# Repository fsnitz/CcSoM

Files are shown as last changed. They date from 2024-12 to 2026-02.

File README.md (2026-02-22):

# CcSoM
Screenshot 2024-12-20 at 3 45 26 PM

## Description
CcSoM is a credit card-sized System on Module built around the GateMate FPGA from Cologne Chip. It is designed to accommodate the CCGM1A1 and CCGM1A2 FPGAs with all their features. 
This repository contains all the necessary design files to fabricate and further develop the SoM itself or an application specific baseboard for it. 
A simple IO tester and programmer baseboard can be found in the [Baseboards](Baseboards) folder.
The [Library](Library) folder contains a symbol and footprint to simplify the process of creating a new baseboard. 
Each board folder includes a PDF version of the board and schematics, as well as an interactive HTML BOM.

## Features: 
  - Choose the IO-Bank supply voltage for each IO-Bank freely within the capability of the GateMate FPGA (default 2.5V).
  - All IOs are routed to the SODIMM-connector and can be accessed either as single-ended signal or as differential pair with its designated partner IO.
  - Configuration of the FPGA is possible over JTAG or the on-board QSPI-Flash.

## Manufacturing notes
- The SoM is designed for JLCPCBs "JLC0610H-3313" layer stack and with vias in pads. If a different manufacturer is chosen, it is advisable to either reroute all differential lines or to find a manufacturer where the layer stack can be specified.
- Most of the resistors and capacitors have a 0201 footprint, which may complicate the manufacturing process. 

## Author
Felix Sebastian Nitz

## Acknowledgment
A special thanks to Cologne chip and its employees for their feedback on the design and FPGA samples.

## License
This project falls under the open hardware licence agreement.

## Project status
- SoM revision 1.0 is currently tested with the CCGM1A1 FPGA. Beginning of 2025 an evaluation of its capabilities with an CCGM1A2 will follow.
- A version of the SoM with a 0402 footprint can be found under its designated Tag [0402 Version](https://github.com/fsnitz/CcSoM/tree/VersionWith0402Components).

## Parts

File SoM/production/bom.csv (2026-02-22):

Designator | Footprint | Quantity | Value | LCSC Part #
C1, C11, C13, C21, C23, C29, C35, C41, C7 | 0402 | 9 | 2u2
C10, C20, C44, C45, C46, C47, C6 | 0603 | 7 | 22u
C12, C22, C8 | 0402 | 3 | 220n
C14, C24, C30, C36 | 0402 | 4 | 470n
C15, C16, C19, C2, C25, C26, C3, C31, C32, C37, C38, C4, C42, C43, C5, C9 | 0402 | 16 | 100n
C17, C18, C27, C28, C33, C34, C39, C40 | 0402 | 8 | 10n
D1 | 0603 | 1 | Orange
D2, D3 | 0603 | 2 | GREEN
JP9 | Diff_pair_solderbridge_closed | 1 | ~
L1, L2 | 0603 | 2 | 600R 1.5A, 0.1R
Q1, Q2 | SOT-23 | 2 | BC847
R1, R12, R13 | 0402 | 3 | 200R
R10, R4, R5 | 0402 | 3 | 4K7
R11, R18, R19, R2, R20, R21, R22, R23, R24, R27, R31, R36, R41, R6, R7, R8, R9 | 0402 | 17 | 10K
R14 | Diff_pair_solderbridge_closed | 1 | 100R
R15 | 0402 | 1 | 1R 1%
R16, R17 | 0402 | 2 | DNS
R25 | 0402 | 1 | 100R
R26, R37 | 0402 | 2 | 1K
R28 | 0402 | 1 | 20K 1%
R29 | 0402 | 1 | 100K 1%
R3 | 0402 | 1 | 33R
R30 | 0402 | 1 | 51K 1%
R32 | 0402 | 1 | 240K 1%
R33 | 0402 | 1 | 47K 1%
R34 | 0402 | 1 | 120K 1%
R35 | 0402 | 1 | 62K 1%
R38 | 0402 | 1 | 200K 1%
R39 | 0402 | 1 | 12K
R40 | 0402 | 1 | 63K4 1%
TP21 | TestPoint_Pad_D1.0mm | 1 | Vcore
TP22 | TestPoint_Pad_D1.0mm | 1 | PG
U1 | BGA-324_15.0x15.0mm_Layout18x18_P0.8mm_Ball0.45mm_Pad0.4mm_NSMD | 1 | CCGM1A1
U2 | SOP-8(150_200MIL) | 1 | MX25V8035F
U3 | DCU8 | 1 | 74LVC2G53
U4, U5 | QFN18 | 2 | MPM3833C
X1 | 5x3.2_Oscillator | 1 | ECS-5032MV

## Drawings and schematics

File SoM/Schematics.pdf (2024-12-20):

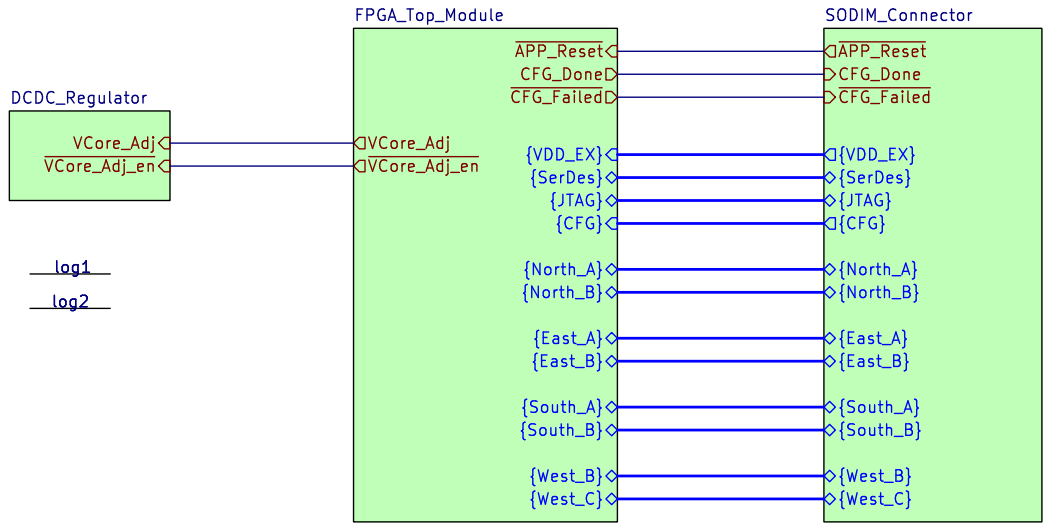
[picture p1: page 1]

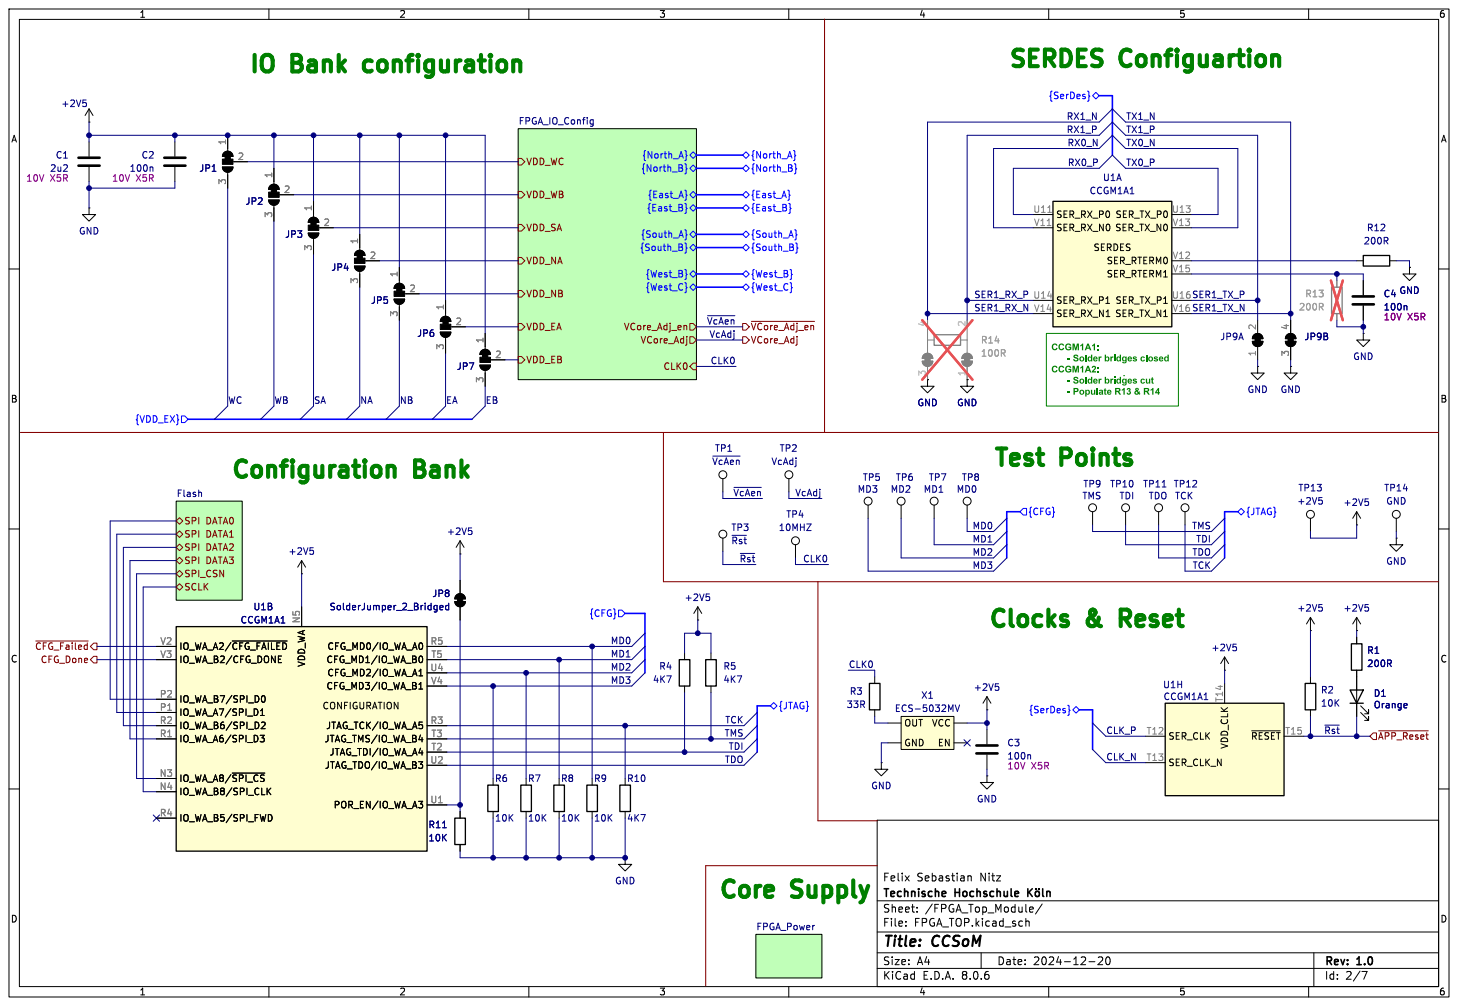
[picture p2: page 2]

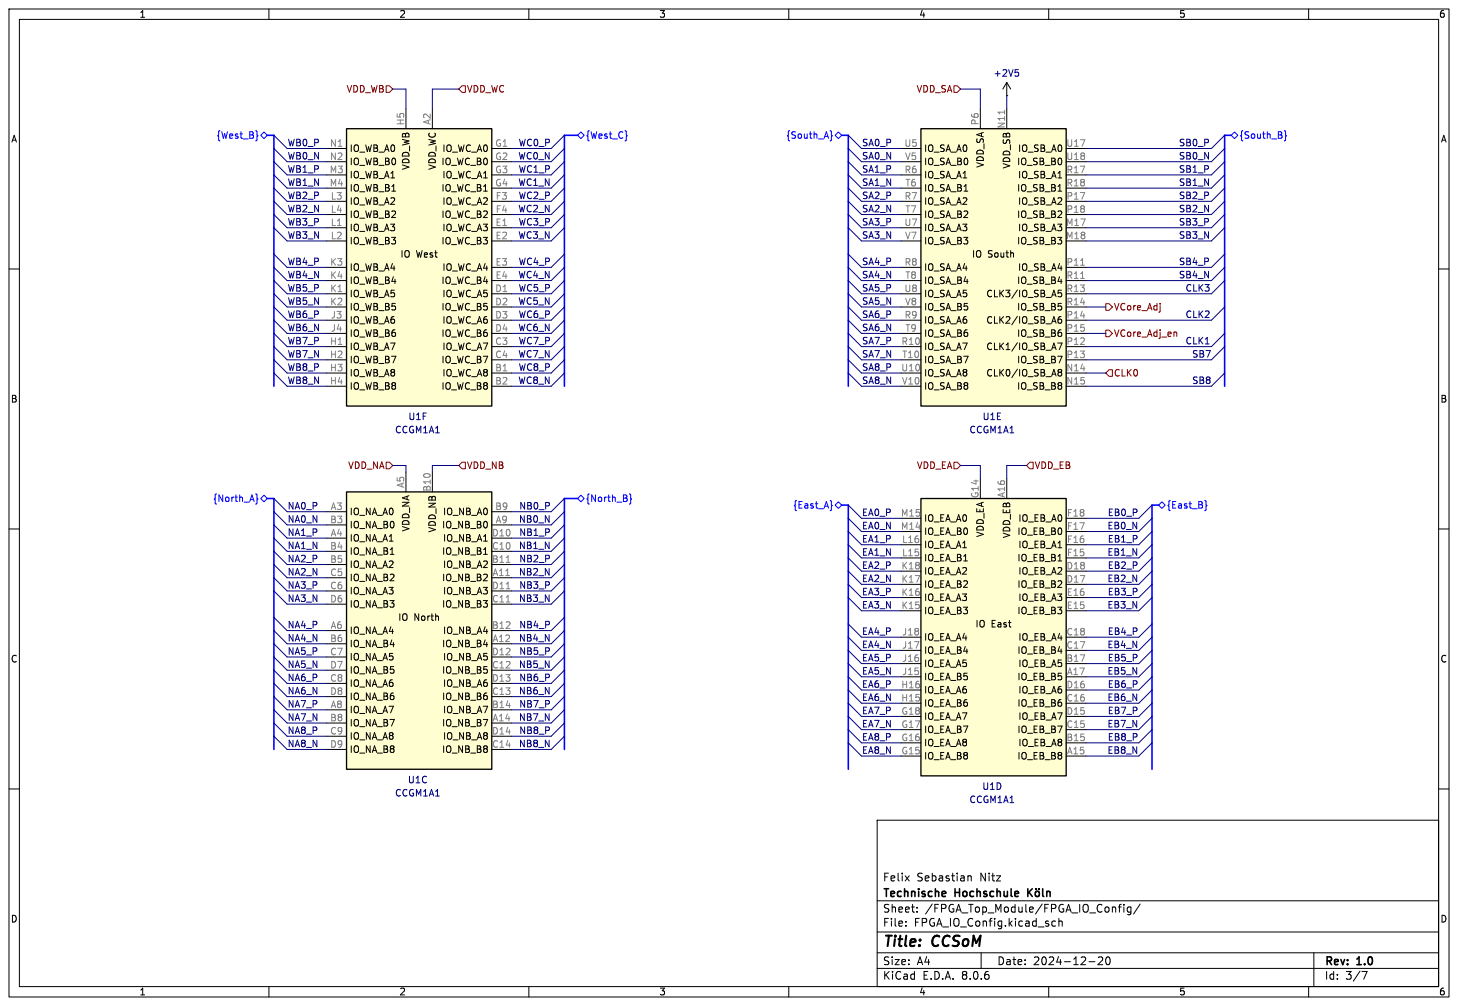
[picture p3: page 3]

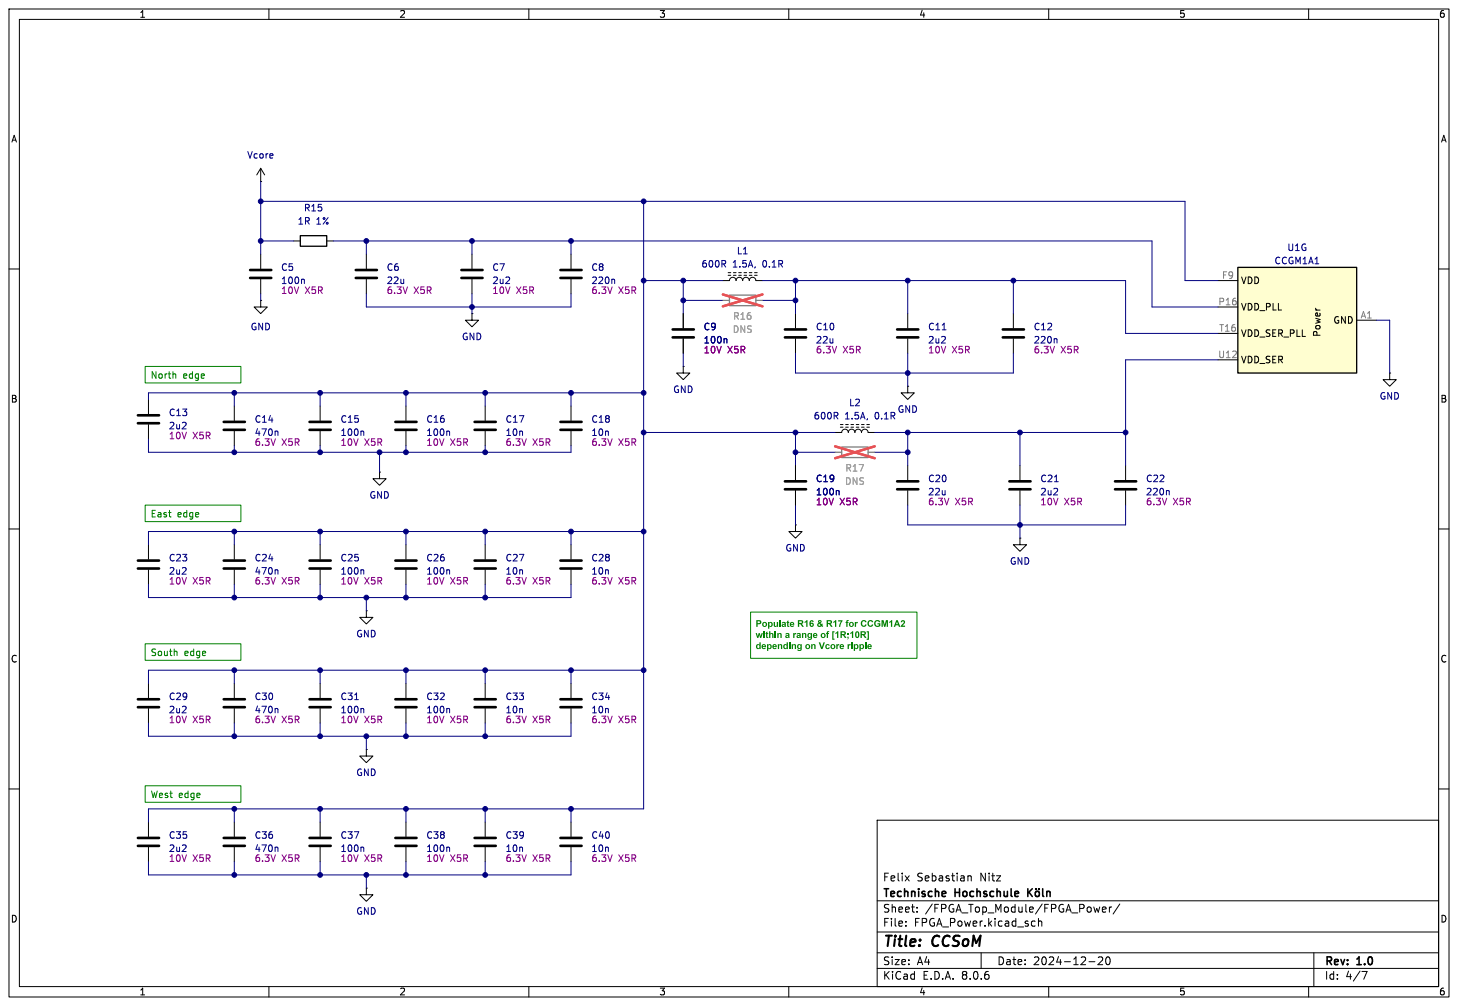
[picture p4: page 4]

Populate R16 & R17 for CCGM1A2 within a range of [1R;10R]

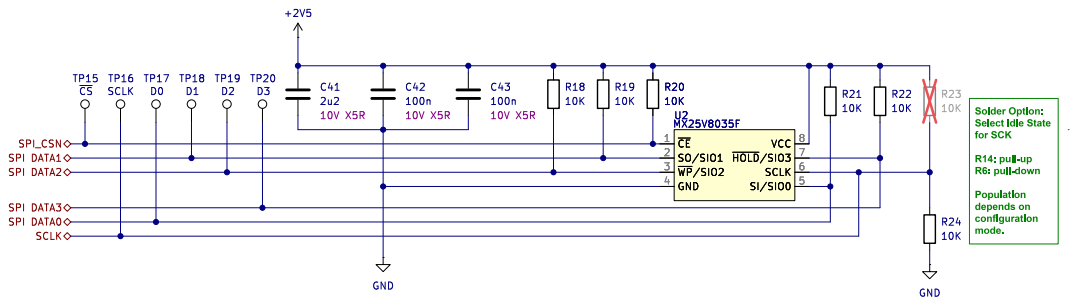
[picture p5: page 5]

Solder Option: Select Idle State

R14: pull-up R6: pull-down

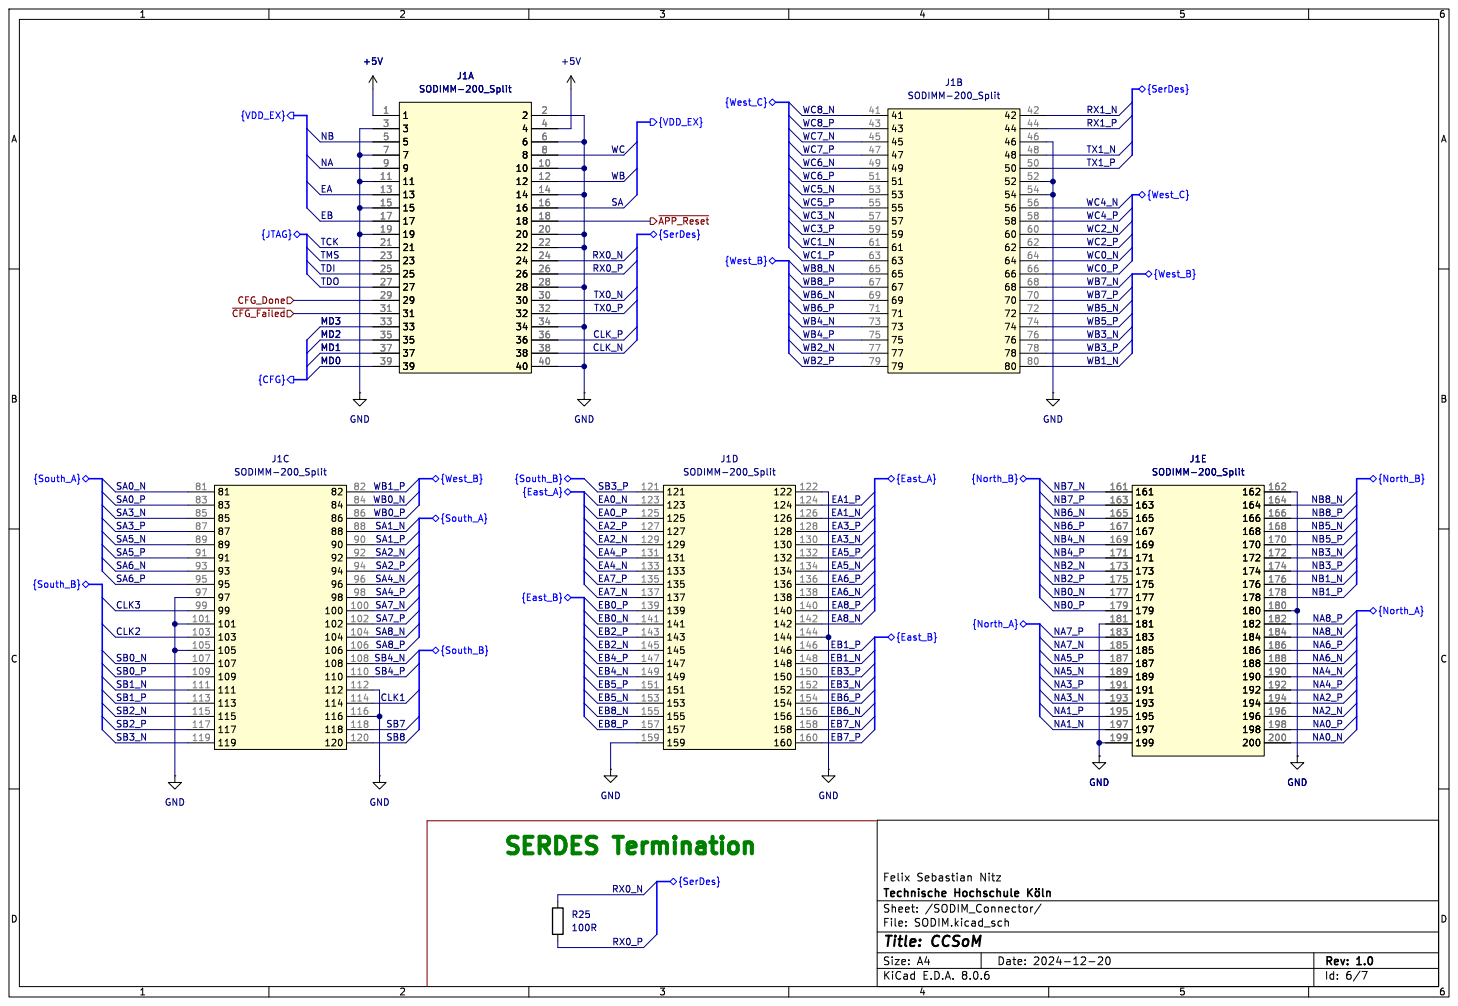
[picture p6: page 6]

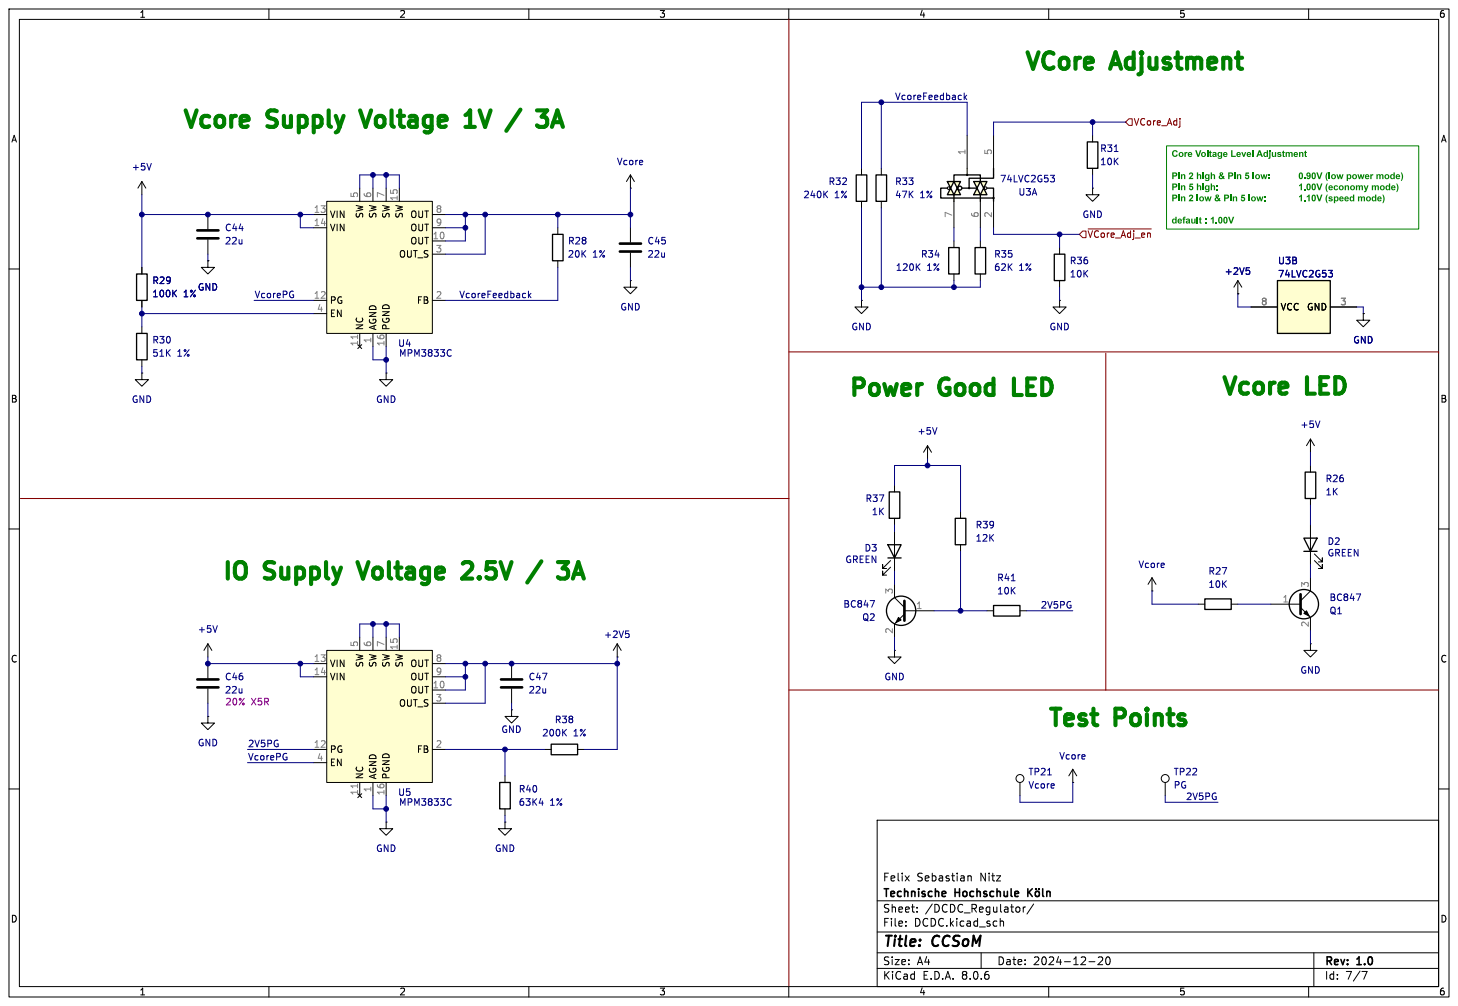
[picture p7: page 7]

1 OUT 10 NC 11 PG 12 VIN 13 VIN 14 SW 15 PGND 16 FB 2 OUT_S 3 EN 4 SW

7 OUT 8 OUT 9 U4MPM3833C GND GND

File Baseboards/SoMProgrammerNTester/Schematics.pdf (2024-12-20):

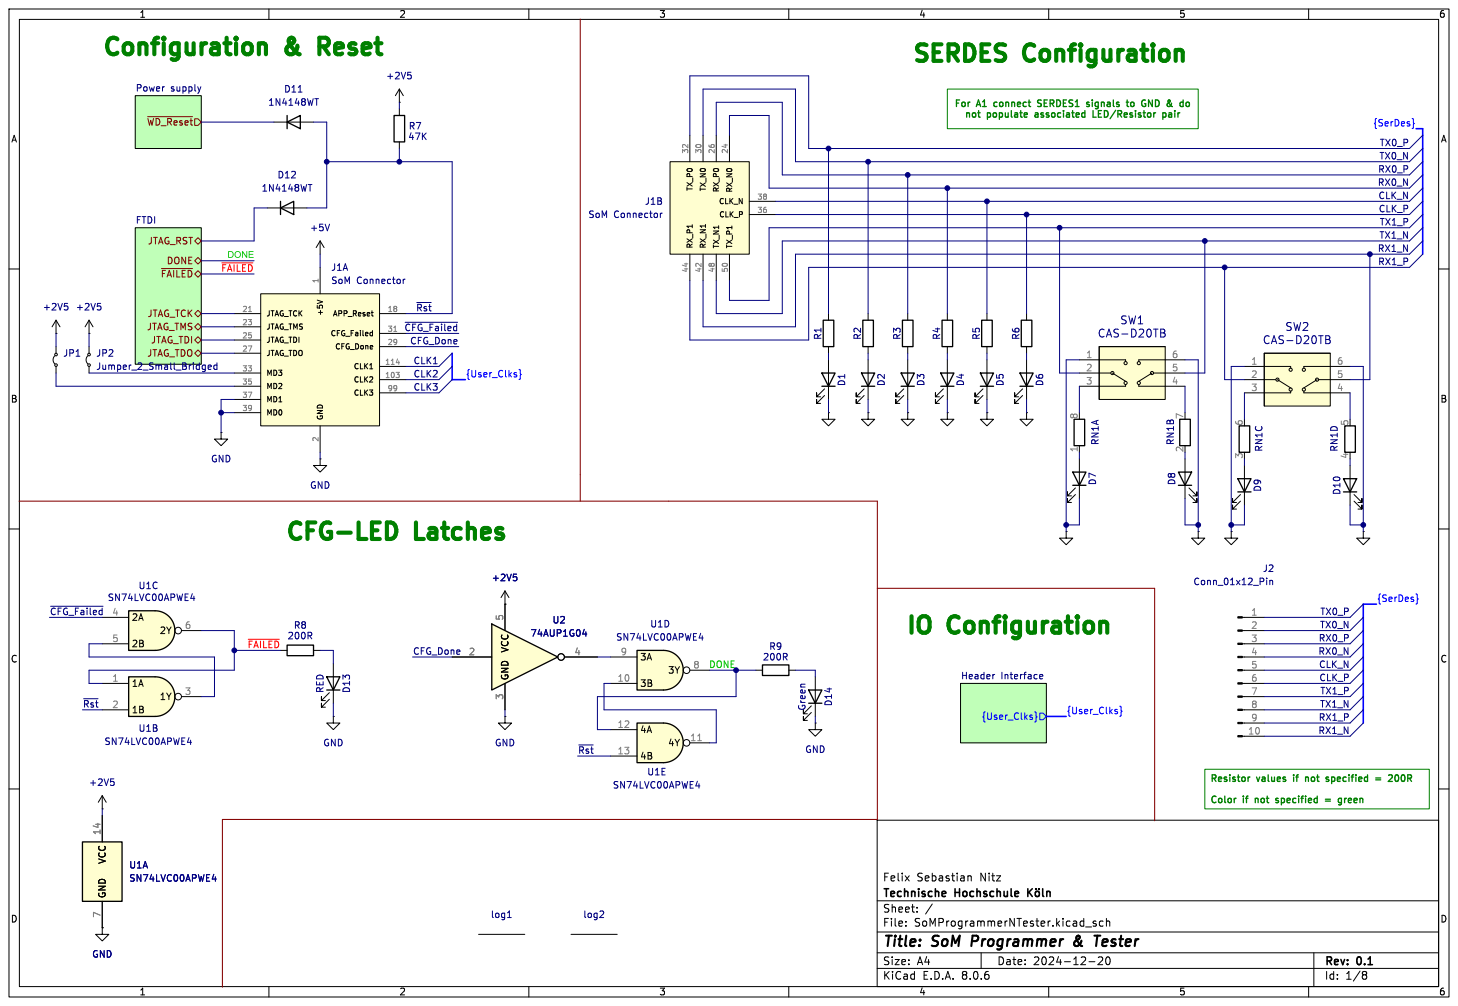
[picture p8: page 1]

For A1 connect SERDES1 signals to GND & do

Color if not specified = green U1A

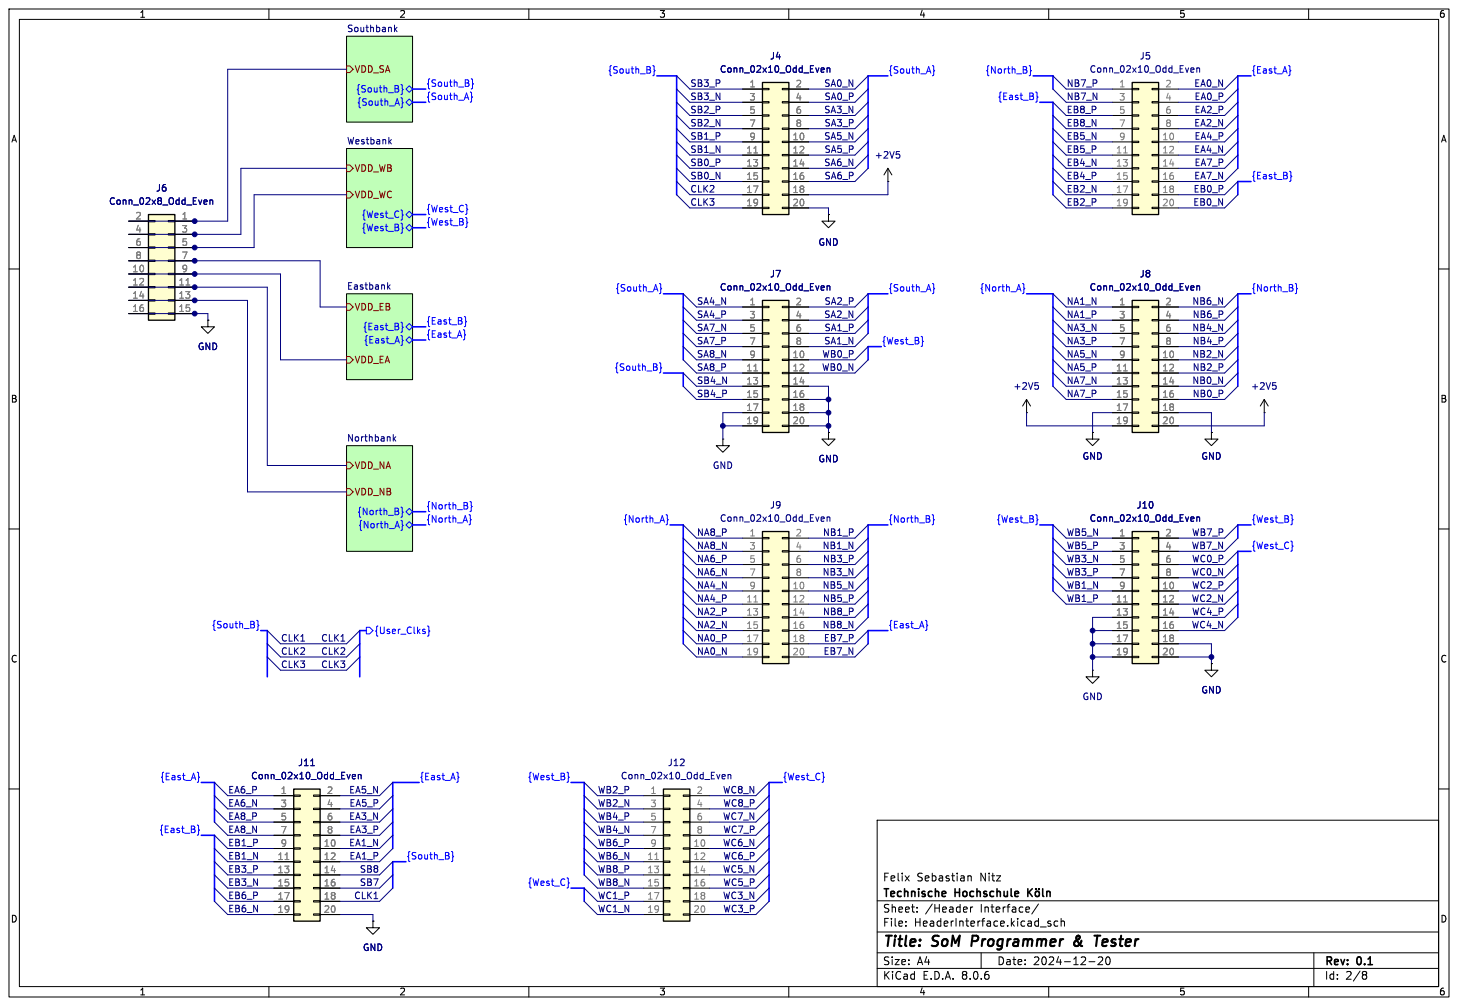
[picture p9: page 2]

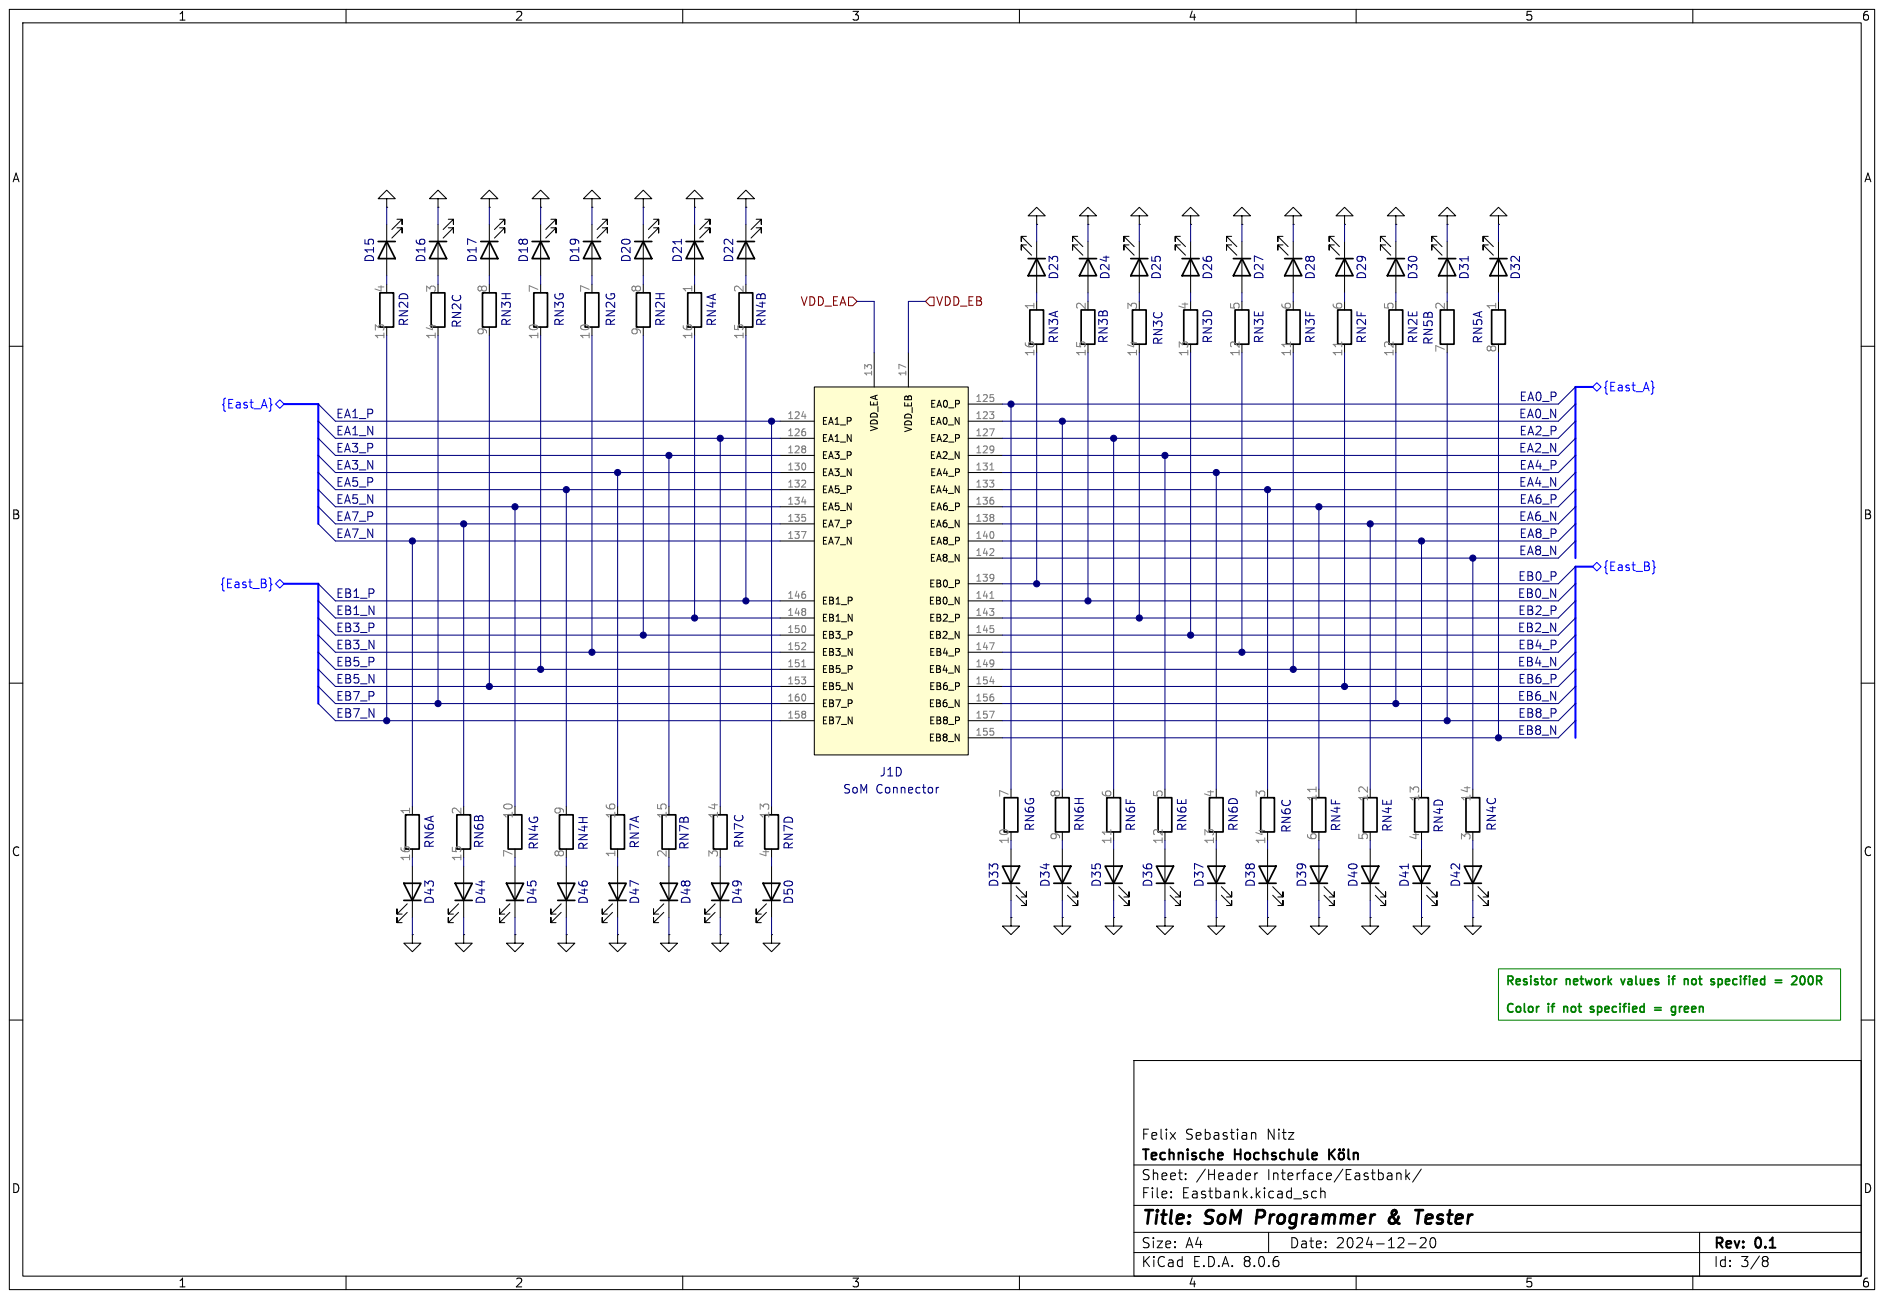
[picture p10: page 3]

Resistor network values if not specified = 200R

Color if not specified = green

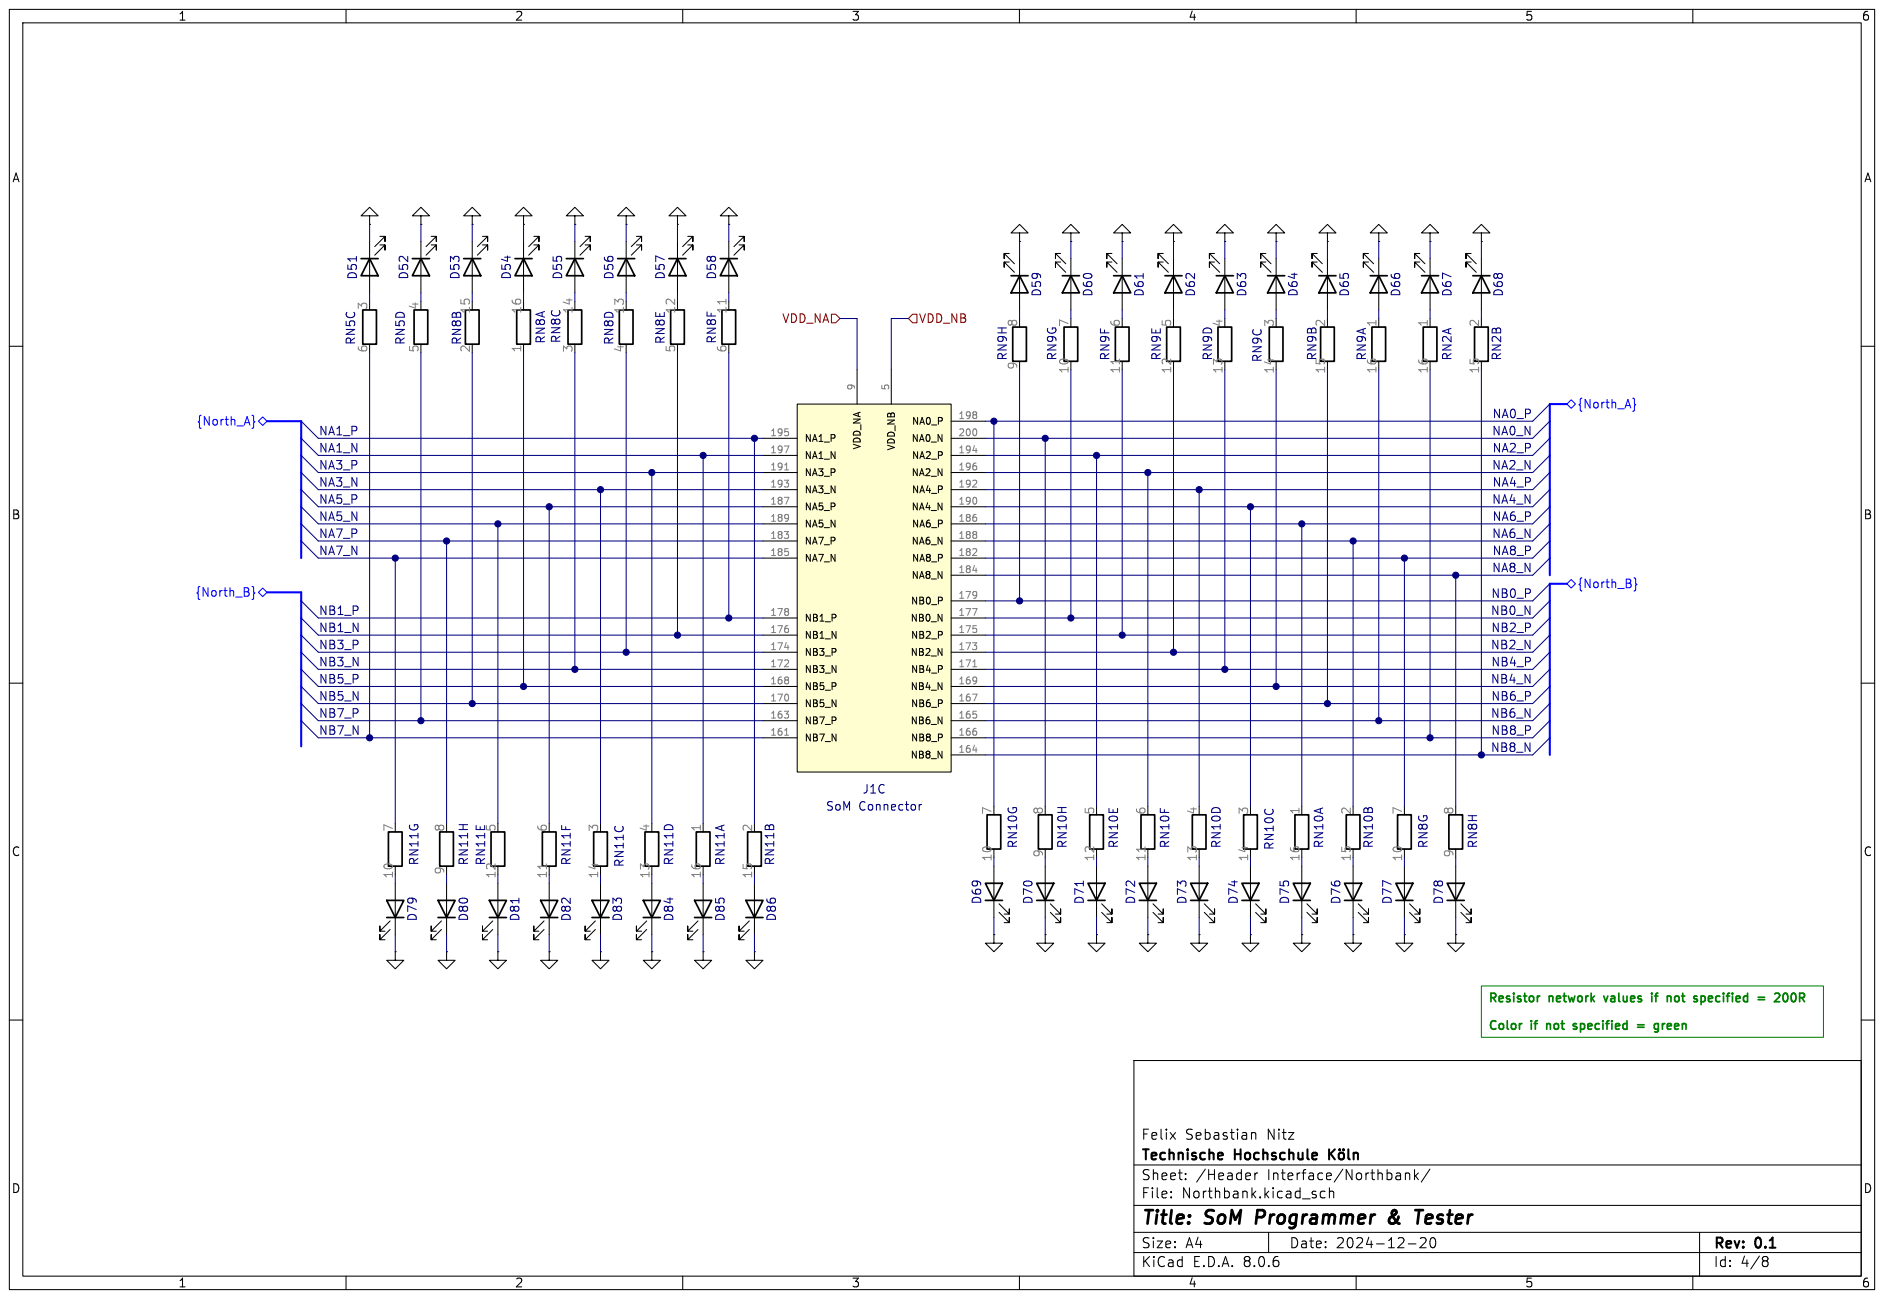
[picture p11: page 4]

NA0_P Resistor network values if not specified = 200R

Color if not specified = green

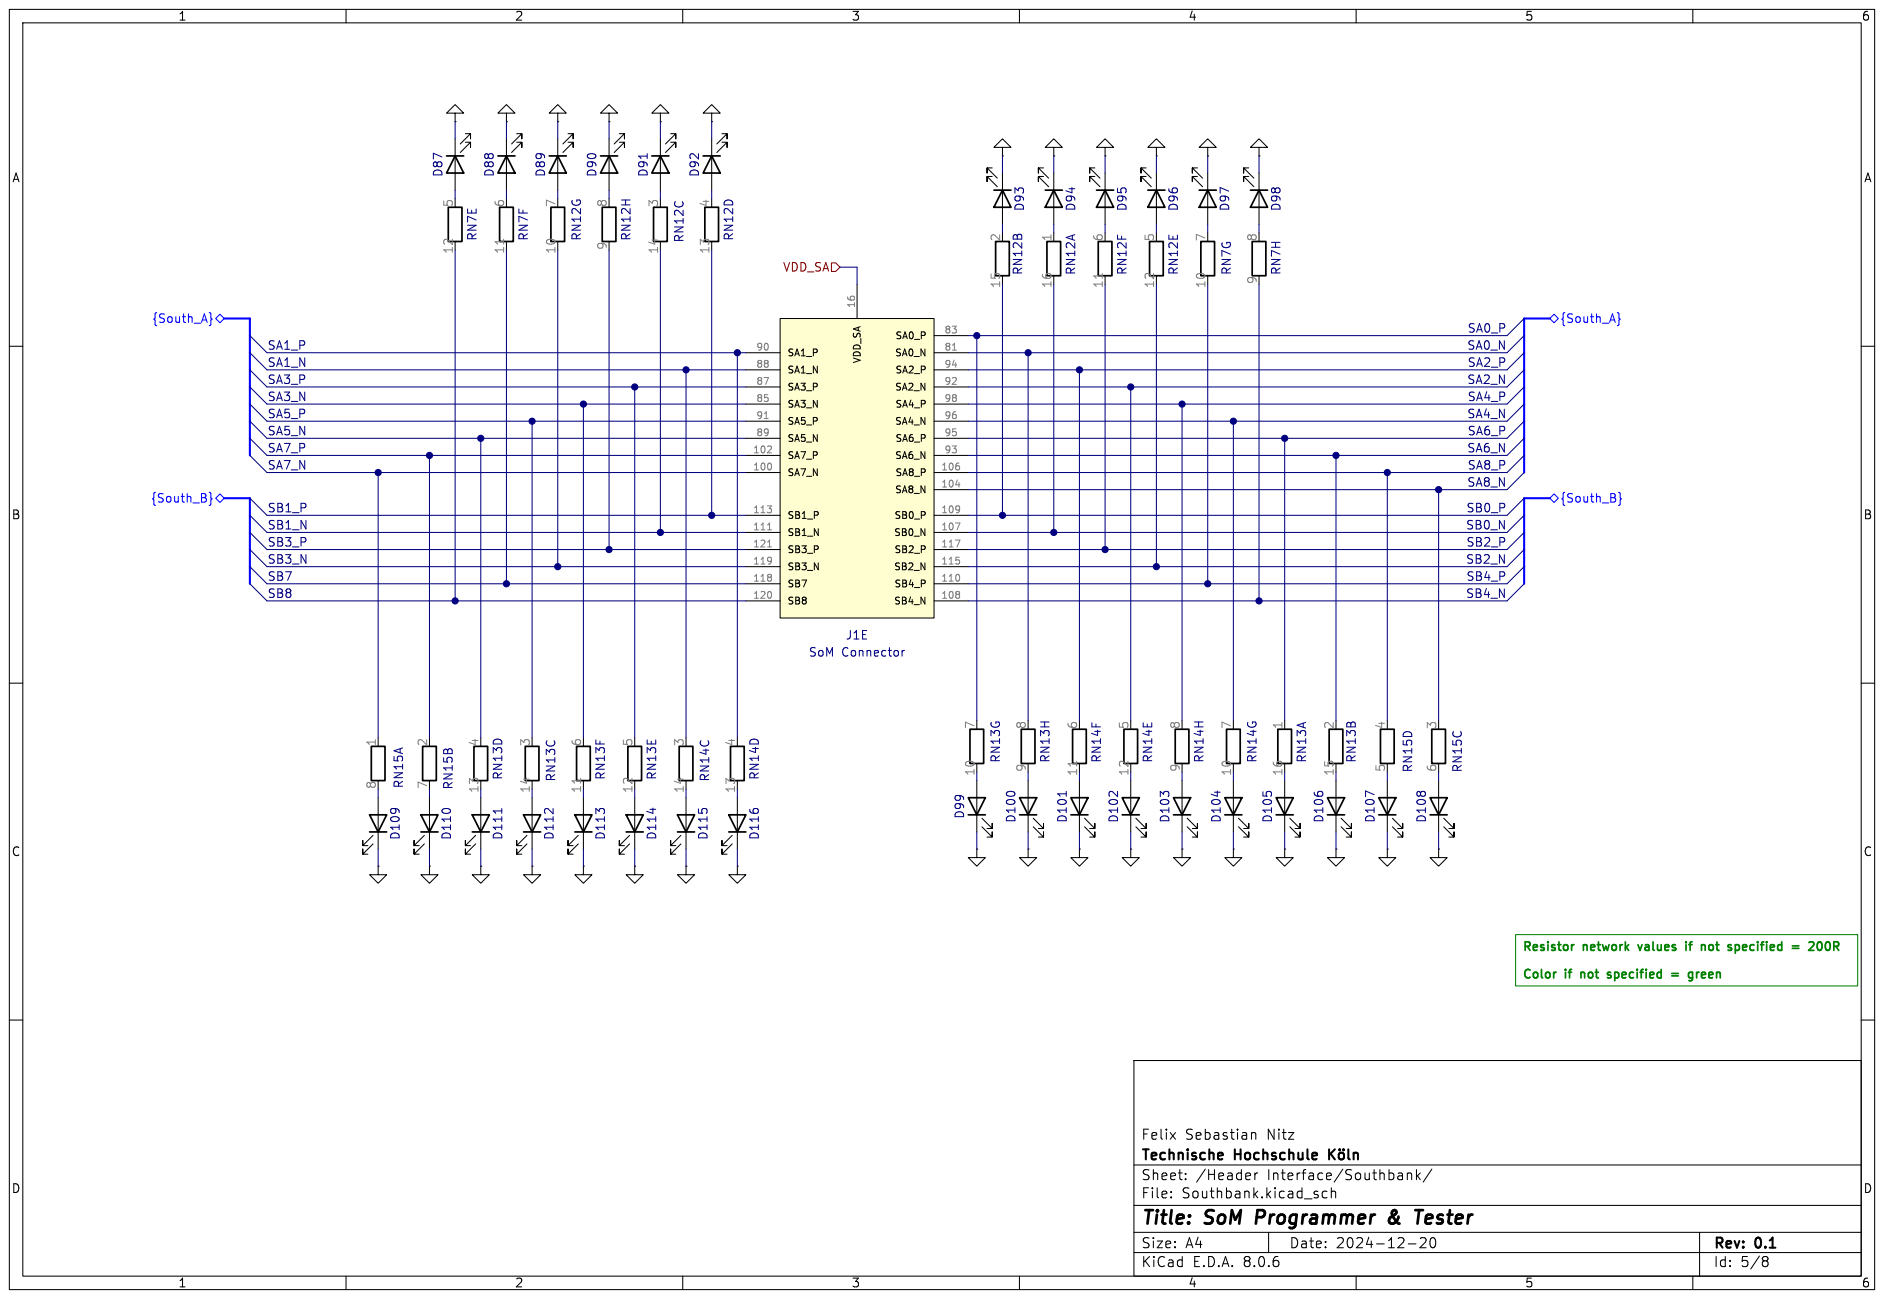
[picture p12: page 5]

Resistor network values if not specified = 200R

Color if not specified = green


Resistor network values if not specified = 200R

Color if not specified = green


1 AGND 10 GND 11 VCORE 12 TEST 13 ~{RESET} 14 GND 15 ADBUS0 16 ADBUS1 17 ADBUS2 18 ADBUS3 19 OSCI 2 VCCIO 20 ADBUS4 21 ADBUS5 22 ADBUS6 23 ADBUS7 24 GND 25 ACBUS0 26 ACBUS1 27 ACBUS2 28 ACBUS3 29 OSCO 3 ACBUS4 30 VCCIO 31 ACBUS5 32 ACBUS6 33 ACBUS7 34 GND 35

4 BDBUS2 40 BDBUS3 41 VCCIO 42 BDBUS4 43 BDBUS5 44 BDBUS6 45 BDBUS7 46 GND 47 BCBUS0 48 VREGOUT 49 GND

5 VREGIN 50 GND 51 BCBUS1 52 BCBUS2 53 BCBUS3 54 BCBUS4 55 VCCIO 56 BCBUS5 57 BCBUS6 58 BCBUS7 59 REF 6 ~{PWREN}60 EEDATA 61 EECLK 62 EECS 63 VCORE 64 DM 7 DP 8 VPLL




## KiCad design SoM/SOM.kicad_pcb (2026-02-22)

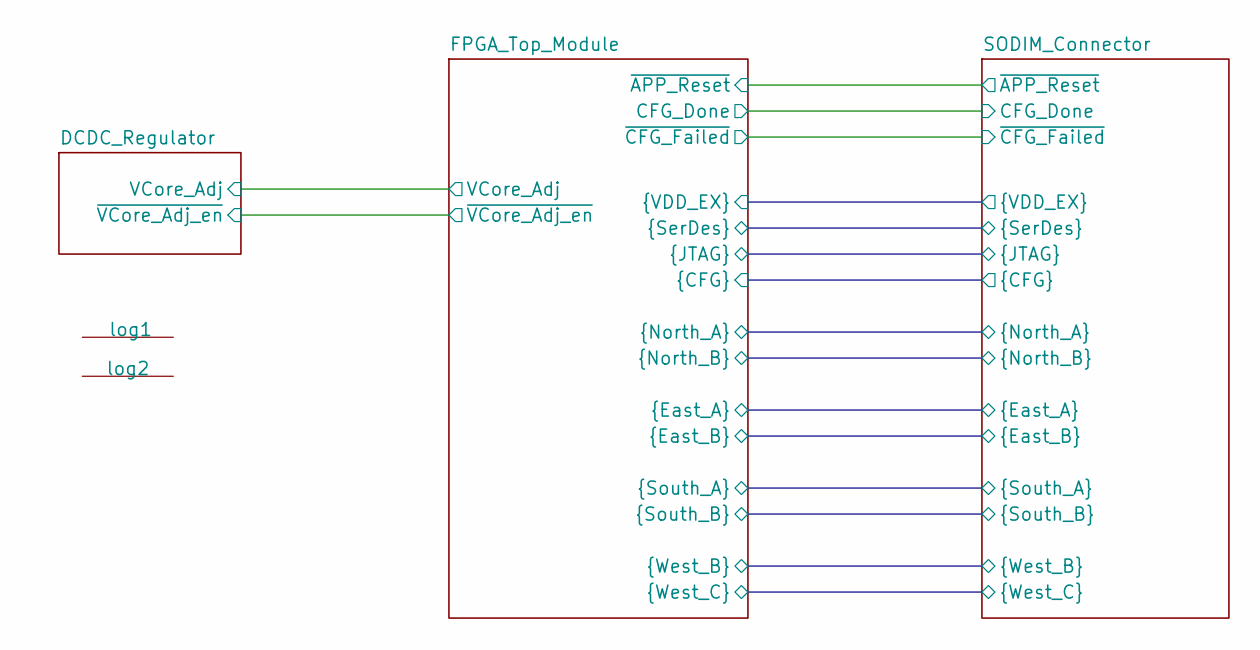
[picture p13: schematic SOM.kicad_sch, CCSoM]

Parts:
log1: PinguinLogo
log2: OpenHardwareLogo

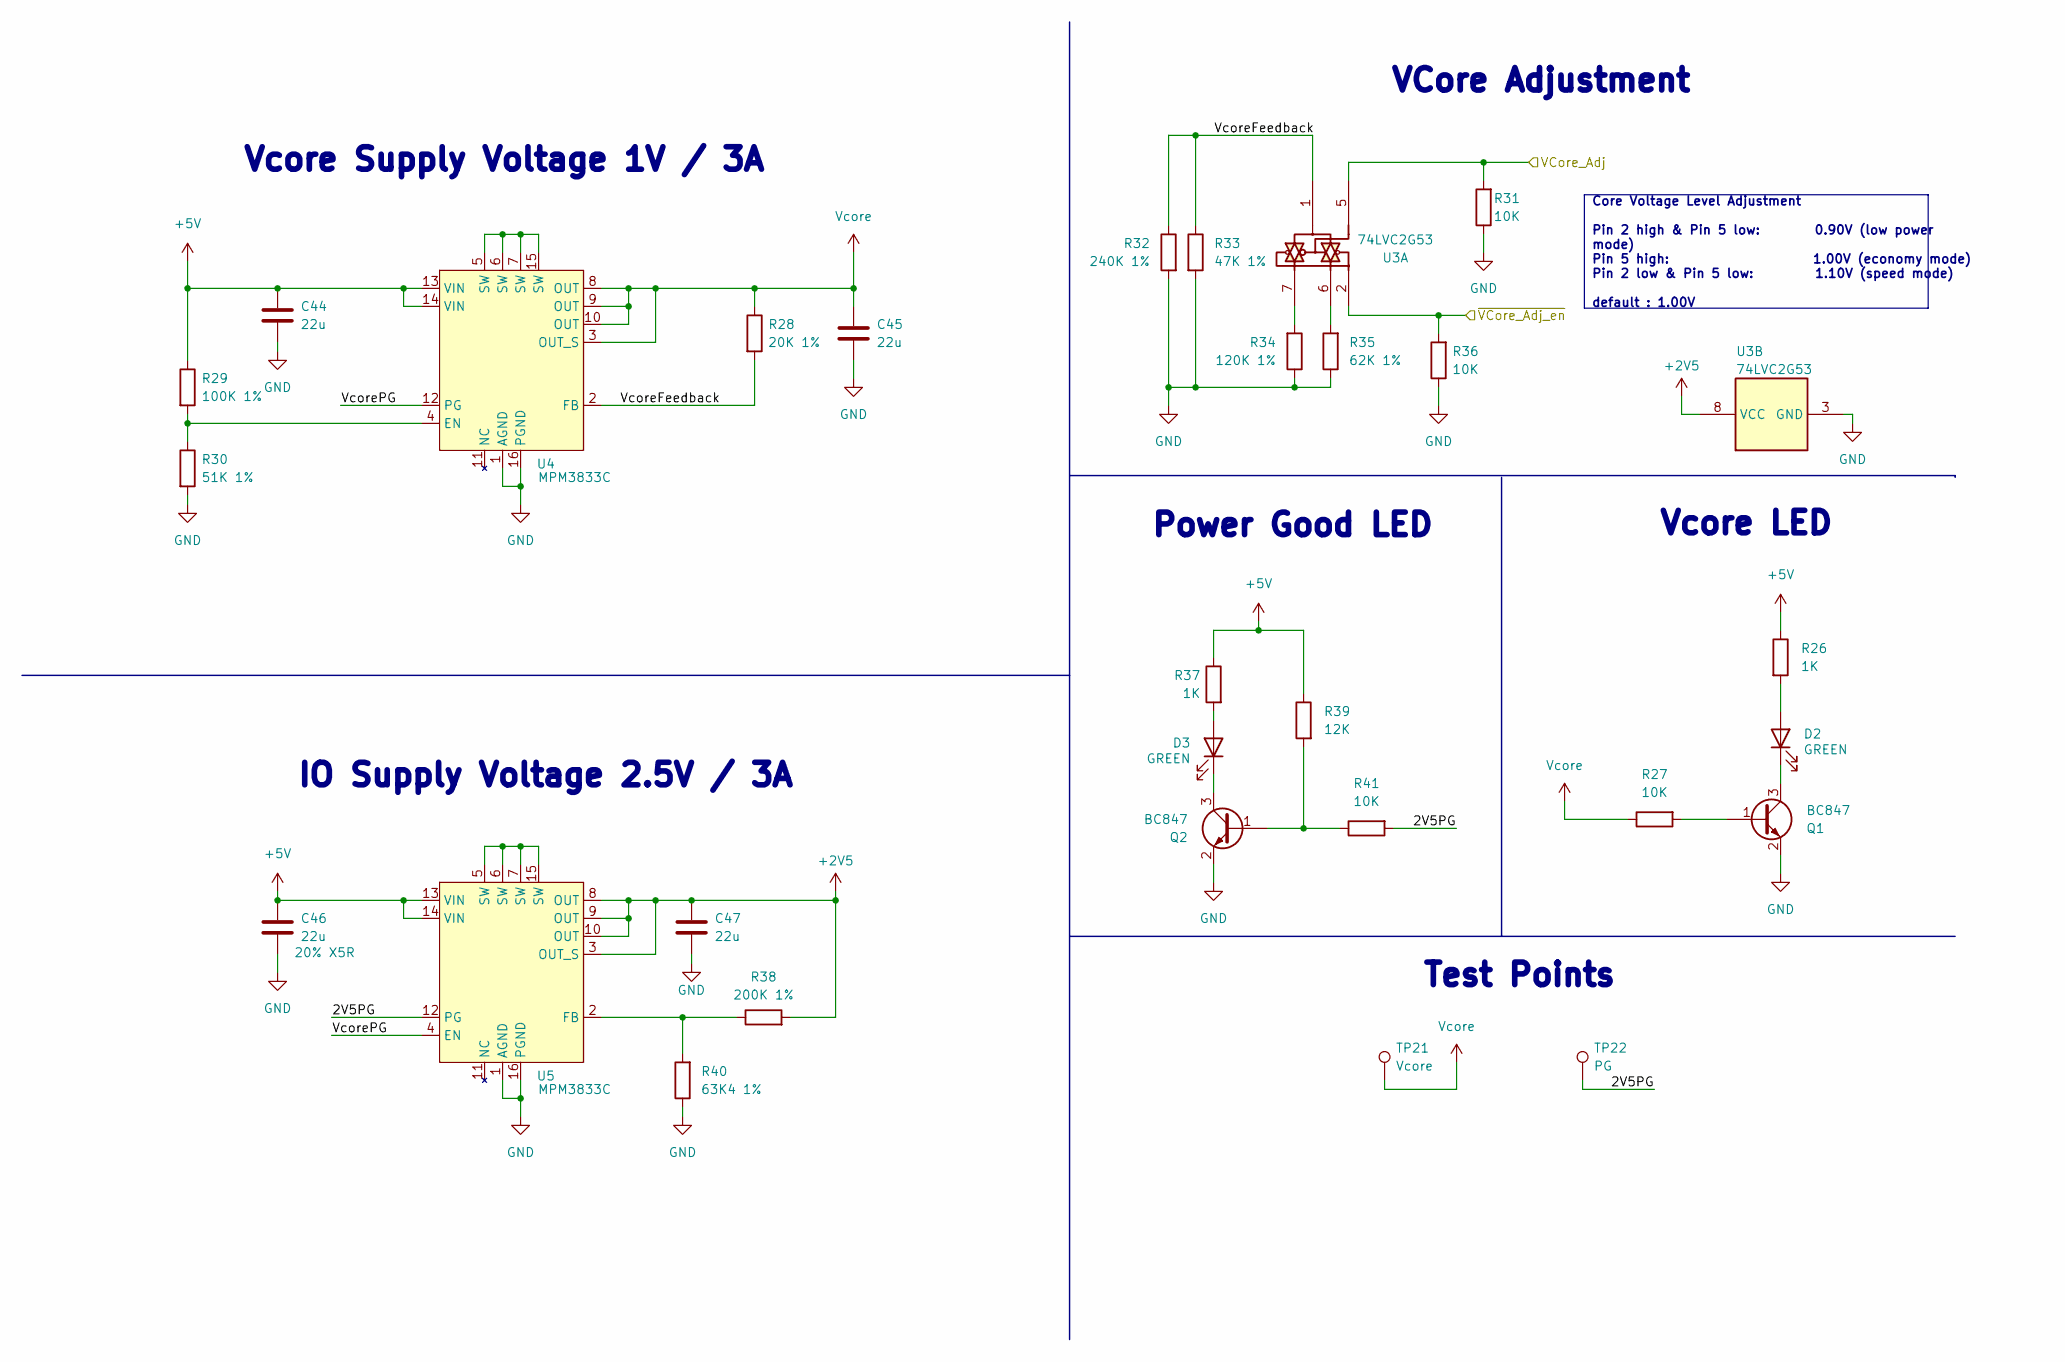
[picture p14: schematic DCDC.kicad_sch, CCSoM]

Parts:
C44, C45, C46, C47: 22u; C_0603_1608Metric; Mouser Part Number GRM188C61C226ME01W
D2, D3: GREEN; LED_0603_1608Metric; Mouser Part Number 150060VS75000
Q1, Q2: BC847; SOT-23; Mouser Part Number BC847C-C
R26, R37: 1K; R_0402_1005Metric; Mouser Part Number MCS04020C1001FE000
R27, R31, R36, R41: 10K; R_0402_1005Metric; Mouser Part Number MCS0402MC1002FE000
R28: 20K 1%; R_0402_1005Metric; Mouser Part Number CRCW040220K0FKED
R29: 100K 1%; R_0402_1005Metric; Mouser Part Number MCS04020C1003FE000
R30: 51K 1%; R_0402_1005Metric; Mouser Part Number CRCW040251K0FKEDC
R32: 240K 1%; R_0402_1005Metric; Mouser Part Number MCS04020C2403FE000
R33: 47K 1%; R_0402_1005Metric; Mouser Part Number CRCW040247K0FKED
R34: 120K 1%; R_0402_1005Metric; Mouser Part Number MCS04020C1203FE000
R35: 62K 1%; R_0402_1005Metric; Mouser Part Number CRCW040262K0FKED
R38: 200K 1%; R_0402_1005Metric; Mouser Part Number CRCW0402200KFKEDC
R39: 12K; R_0402_1005Metric; Mouser Part Number MCS04020C1202FE000
R40: 63K4 1%; R_0402_1005Metric; Mouser Part Number CRCW040263K4FKED
TP21: Vcore; TestPoint_Pad_D1.0mm
TP22: PG; TestPoint_Pad_D1.0mm
U3: 74LVC2G53; DCU8; Mouser Part Number SN74LVC2G53DCUR
U4, U5: MPM3833C; QFN18; Mouser Part Number MPM3833CGRH-Z

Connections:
+2V5: C47.1, R38.2, U3.8 (VCC), U5.3 (OUT_S), U5.8 (OUT), U5.9 (OUT), U5.10 (OUT), U5.20 (OUT); also elsewhere on the board
+5V: C44.1, C46.1, R26.1, R29.1, R37.1, R39.1, U4.13 (VIN), U4.14 (VIN), U5.13 (VIN), U5.14 (VIN); also elsewhere on the board
/DCDC_Regulator/2V5PG: R41.2, TP22.1, U5.12 (PG)
/DCDC_Regulator/VcoreFeedback: R28.2, R32.1, R33.1, U3.1, U4.2 (FB)
/DCDC_Regulator/VcorePG: U4.12 (PG), U5.4 (EN)
/FPGA_Top_Module/VcAdj: R31.2, U3.5; also elsewhere on the board
/FPGA_Top_Module/~VcAen: R36.2, U3.2; also elsewhere on the board
GND: C44.2, C45.2, C46.2, C47.2, Q1.2 (E), Q2.2 (E), R30.2, R31.1, R32.2, R33.2, R34.1, R35.1, R36.1, R40.1, U3.3 (GND), U3.4 (GND), U4.1 (AGND), U4.16 (PGND), U5.1 (AGND), U5.16 (PGND); also elsewhere on the board
unnamed: D2.2 (A), R26.2
unnamed: D2.1 (K), Q1.3 (C)
unnamed: D3.2 (A), R37.2
unnamed: D3.1 (K), Q2.3 (C)
unnamed: Q1.1 (B), R27.2
unnamed: Q2.1 (B), R39.2, R41.1
unnamed: R34.2, U3.7
unnamed: R35.2, U3.6
unnamed: R29.2, R30.1, U4.4 (EN)
unnamed: U4.5 (SW), U4.6 (SW), U4.7 (SW), U4.15 (SW), U4.19 (SW)
unnamed: R38.1, R40.2, U5.2 (FB)
unnamed: U5.5 (SW), U5.6 (SW), U5.7 (SW), U5.15 (SW), U5.19 (SW)
Vcore: C45.1, R27.1, R28.1, TP21.1, U4.3 (OUT_S), U4.8 (OUT), U4.9 (OUT), U4.10 (OUT), U4.20 (OUT); also elsewhere on the board

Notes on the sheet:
Power Good LED
Test Points
Vcore LED
Vcore Supply Voltage 1V / 3A
IO Supply Voltage 2.5V / 3A
VCore Adjustment
Core Voltage Level Adjustment Pin 2 high & Pin 5 low: 0.90V (low power mode) Pin 5 high: 1.00V (economy mode) Pin 2 low & Pin 5 low: 1.10V (speed mode) default : 1.00V

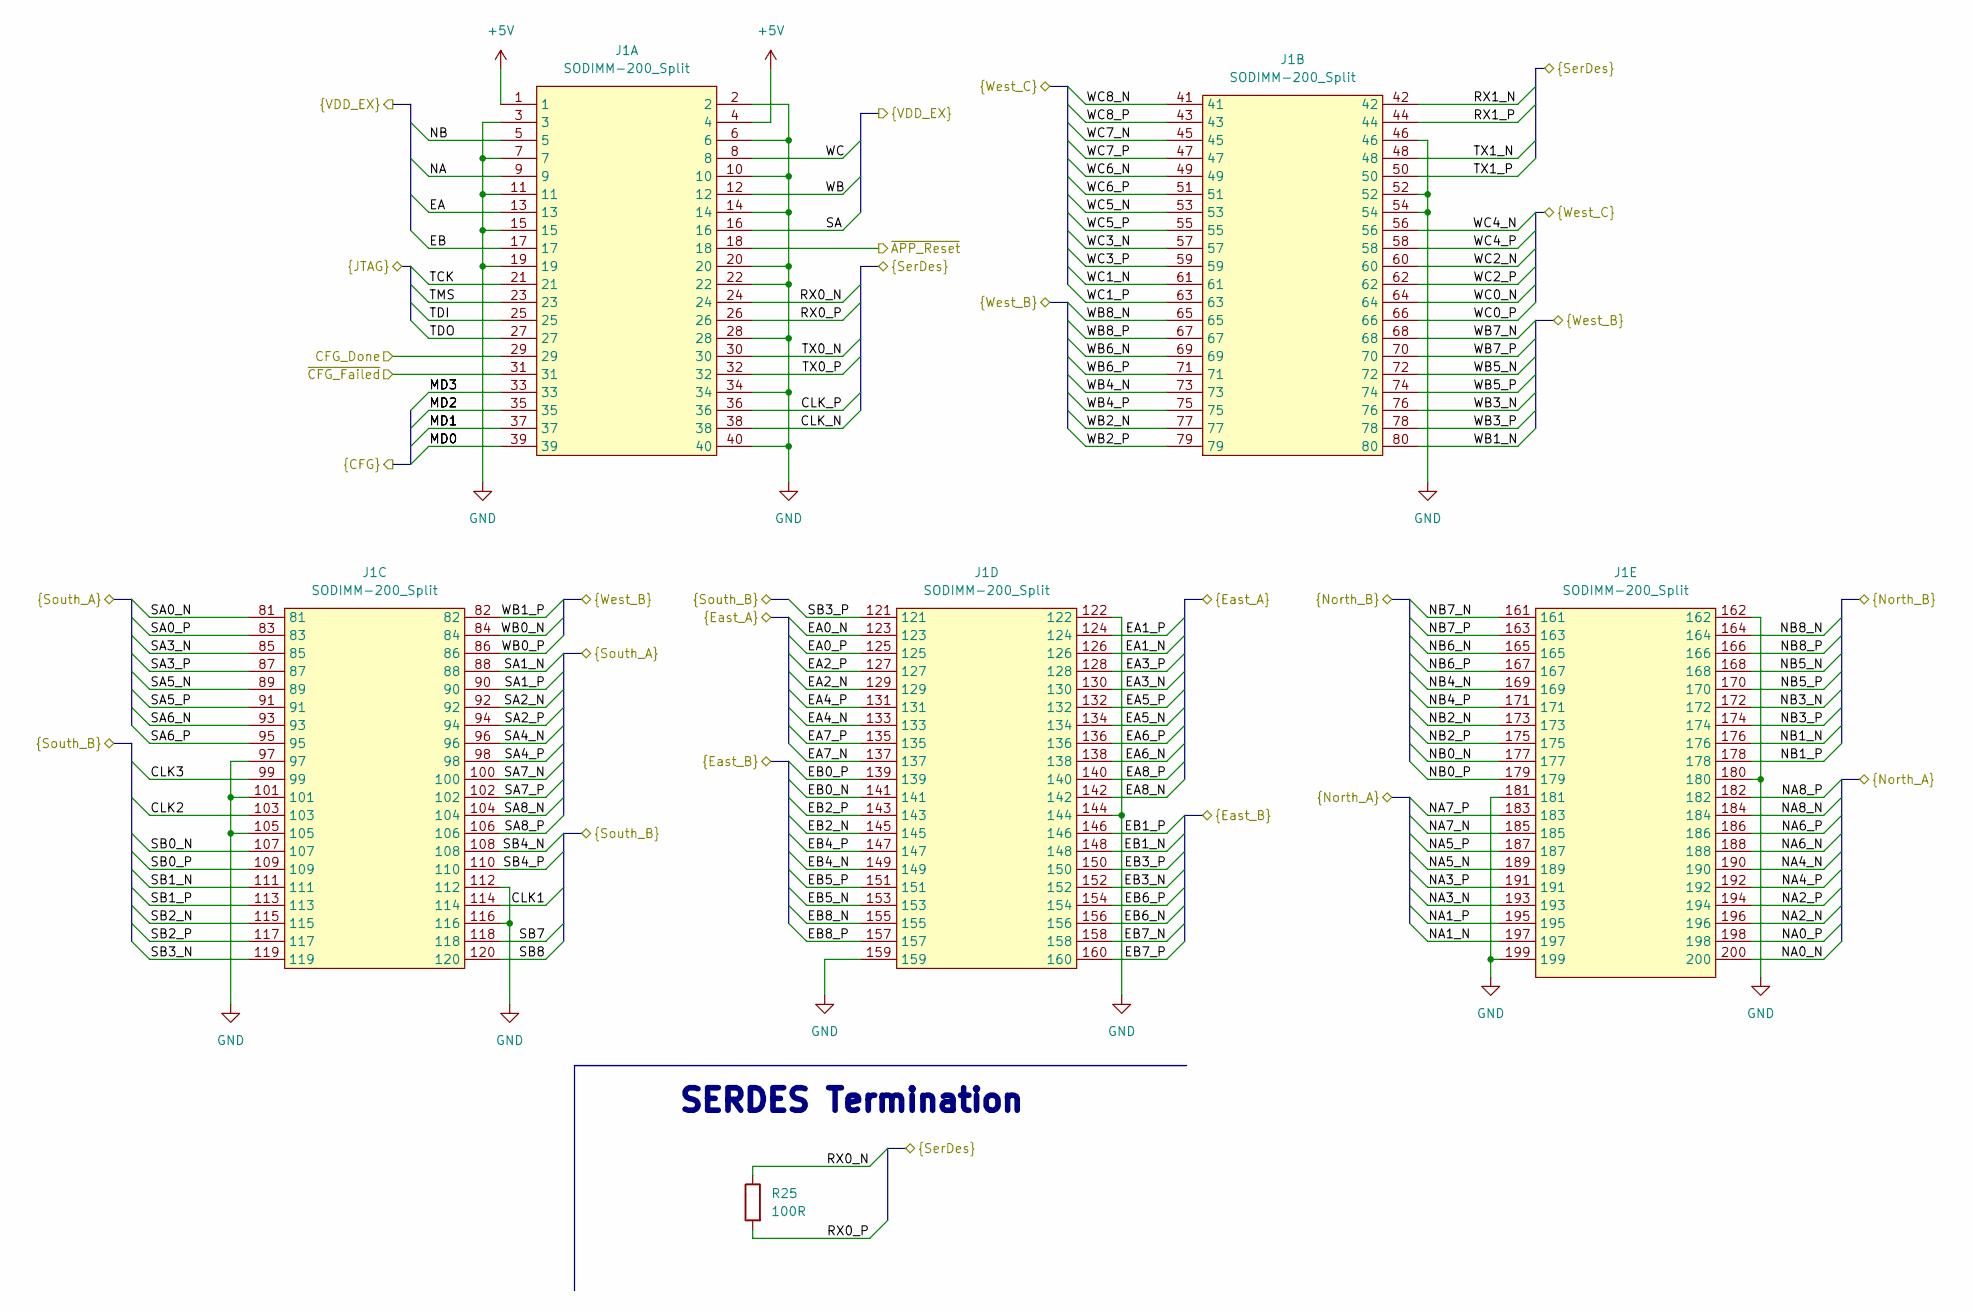
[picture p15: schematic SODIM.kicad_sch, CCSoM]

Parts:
J1: SODIMM-200_Split; SODIMM-200_2.5V_Card_edge
R25: 100R; R_0402_1005Metric; Mouser Part Number MCS04020C1000FE000

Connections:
+5V: J1.1, J1.4; also elsewhere on the board
/FPGA_Top_Module/CFG_Done: J1.29; also elsewhere on the board
/FPGA_Top_Module/CLK1: J1.114; also elsewhere on the board
/FPGA_Top_Module/CLK2: J1.103; also elsewhere on the board
/FPGA_Top_Module/CLK3: J1.99; also elsewhere on the board
/FPGA_Top_Module/CLK_N: J1.38; also elsewhere on the board
/FPGA_Top_Module/CLK_P: J1.36; also elsewhere on the board
/FPGA_Top_Module/EA: J1.13; also elsewhere on the board
/FPGA_Top_Module/EA0_N: J1.123; also elsewhere on the board
/FPGA_Top_Module/EA0_P: J1.125; also elsewhere on the board
/FPGA_Top_Module/EA1_N: J1.126; also elsewhere on the board
/FPGA_Top_Module/EA1_P: J1.124; also elsewhere on the board
/FPGA_Top_Module/EA2_N: J1.129; also elsewhere on the board
/FPGA_Top_Module/EA2_P: J1.127; also elsewhere on the board
/FPGA_Top_Module/EA3_N: J1.130; also elsewhere on the board
/FPGA_Top_Module/EA3_P: J1.128; also elsewhere on the board
/FPGA_Top_Module/EA4_N: J1.133; also elsewhere on the board
/FPGA_Top_Module/EA4_P: J1.131; also elsewhere on the board
/FPGA_Top_Module/EA5_N: J1.134; also elsewhere on the board
/FPGA_Top_Module/EA5_P: J1.132; also elsewhere on the board
/FPGA_Top_Module/EA6_N: J1.138; also elsewhere on the board
/FPGA_Top_Module/EA6_P: J1.136; also elsewhere on the board
/FPGA_Top_Module/EA7_N: J1.137; also elsewhere on the board
/FPGA_Top_Module/EA7_P: J1.135; also elsewhere on the board
/FPGA_Top_Module/EA8_N: J1.142; also elsewhere on the board
/FPGA_Top_Module/EA8_P: J1.140; also elsewhere on the board
/FPGA_Top_Module/EB: J1.17; also elsewhere on the board
/FPGA_Top_Module/EB0_N: J1.141; also elsewhere on the board
/FPGA_Top_Module/EB0_P: J1.139; also elsewhere on the board
/FPGA_Top_Module/EB1_N: J1.148; also elsewhere on the board
/FPGA_Top_Module/EB1_P: J1.146; also elsewhere on the board
/FPGA_Top_Module/EB2_N: J1.145; also elsewhere on the board
/FPGA_Top_Module/EB2_P: J1.143; also elsewhere on the board
/FPGA_Top_Module/EB3_N: J1.152; also elsewhere on the board
/FPGA_Top_Module/EB3_P: J1.150; also elsewhere on the board
/FPGA_Top_Module/EB4_N: J1.149; also elsewhere on the board
/FPGA_Top_Module/EB4_P: J1.147; also elsewhere on the board
/FPGA_Top_Module/EB5_N: J1.153; also elsewhere on the board
/FPGA_Top_Module/EB5_P: J1.151; also elsewhere on the board
/FPGA_Top_Module/EB6_N: J1.156; also elsewhere on the board
/FPGA_Top_Module/EB6_P: J1.154; also elsewhere on the board
/FPGA_Top_Module/EB7_N: J1.158; also elsewhere on the board
/FPGA_Top_Module/EB7_P: J1.160; also elsewhere on the board
/FPGA_Top_Module/EB8_N: J1.155; also elsewhere on the board
/FPGA_Top_Module/EB8_P: J1.157; also elsewhere on the board
/FPGA_Top_Module/MD0: J1.39; also elsewhere on the board
/FPGA_Top_Module/MD1: J1.37; also elsewhere on the board
/FPGA_Top_Module/MD2: J1.35; also elsewhere on the board
/FPGA_Top_Module/MD3: J1.33; also elsewhere on the board
/FPGA_Top_Module/NA: J1.9; also elsewhere on the board
/FPGA_Top_Module/NA0_N: J1.200; also elsewhere on the board
/FPGA_Top_Module/NA0_P: J1.198; also elsewhere on the board
/FPGA_Top_Module/NA1_N: J1.197; also elsewhere on the board
/FPGA_Top_Module/NA1_P: J1.195; also elsewhere on the board
/FPGA_Top_Module/NA2_N: J1.196; also elsewhere on the board
/FPGA_Top_Module/NA2_P: J1.194; also elsewhere on the board
/FPGA_Top_Module/NA3_N: J1.193; also elsewhere on the board
/FPGA_Top_Module/NA3_P: J1.191; also elsewhere on the board
/FPGA_Top_Module/NA4_N: J1.190; also elsewhere on the board
/FPGA_Top_Module/NA4_P: J1.192; also elsewhere on the board
/FPGA_Top_Module/NA5_N: J1.189; also elsewhere on the board
/FPGA_Top_Module/NA5_P: J1.187; also elsewhere on the board
/FPGA_Top_Module/NA6_N: J1.188; also elsewhere on the board
/FPGA_Top_Module/NA6_P: J1.186; also elsewhere on the board
/FPGA_Top_Module/NA7_N: J1.185; also elsewhere on the board
/FPGA_Top_Module/NA7_P: J1.183; also elsewhere on the board
/FPGA_Top_Module/NA8_N: J1.184; also elsewhere on the board
/FPGA_Top_Module/NA8_P: J1.182; also elsewhere on the board
/FPGA_Top_Module/NB: J1.5; also elsewhere on the board
/FPGA_Top_Module/NB0_N: J1.177; also elsewhere on the board
/FPGA_Top_Module/NB0_P: J1.179; also elsewhere on the board
/FPGA_Top_Module/NB1_N: J1.176; also elsewhere on the board
/FPGA_Top_Module/NB1_P: J1.178; also elsewhere on the board
/FPGA_Top_Module/NB2_N: J1.173; also elsewhere on the board
/FPGA_Top_Module/NB2_P: J1.175; also elsewhere on the board
/FPGA_Top_Module/NB3_N: J1.172; also elsewhere on the board
/FPGA_Top_Module/NB3_P: J1.174; also elsewhere on the board
/FPGA_Top_Module/NB4_N: J1.169; also elsewhere on the board
/FPGA_Top_Module/NB4_P: J1.171; also elsewhere on the board
/FPGA_Top_Module/NB5_N: J1.168; also elsewhere on the board
/FPGA_Top_Module/NB5_P: J1.170; also elsewhere on the board
/FPGA_Top_Module/NB6_N: J1.165; also elsewhere on the board
/FPGA_Top_Module/NB6_P: J1.167; also elsewhere on the board
/FPGA_Top_Module/NB7_N: J1.161; also elsewhere on the board
/FPGA_Top_Module/NB7_P: J1.163; also elsewhere on the board
/FPGA_Top_Module/NB8_N: J1.164; also elsewhere on the board
/FPGA_Top_Module/NB8_P: J1.166; also elsewhere on the board
/FPGA_Top_Module/RX0_N: J1.24, R25.1; also elsewhere on the board
/FPGA_Top_Module/RX0_P: J1.26, R25.2; also elsewhere on the board
/FPGA_Top_Module/RX1_N: J1.42; also elsewhere on the board
/FPGA_Top_Module/RX1_P: J1.44; also elsewhere on the board
/FPGA_Top_Module/SA: J1.16; also elsewhere on the board
/FPGA_Top_Module/SA0_N: J1.81; also elsewhere on the board
/FPGA_Top_Module/SA0_P: J1.83; also elsewhere on the board
/FPGA_Top_Module/SA1_N: J1.88; also elsewhere on the board
/FPGA_Top_Module/SA1_P: J1.90; also elsewhere on the board
/FPGA_Top_Module/SA2_N: J1.92; also elsewhere on the board
/FPGA_Top_Module/SA2_P: J1.94; also elsewhere on the board
/FPGA_Top_Module/SA3_N: J1.85; also elsewhere on the board
/FPGA_Top_Module/SA3_P: J1.87; also elsewhere on the board
/FPGA_Top_Module/SA4_N: J1.96; also elsewhere on the board
/FPGA_Top_Module/SA4_P: J1.98; also elsewhere on the board
/FPGA_Top_Module/SA5_N: J1.89; also elsewhere on the board
/FPGA_Top_Module/SA5_P: J1.91; also elsewhere on the board
/FPGA_Top_Module/SA6_N: J1.93; also elsewhere on the board
/FPGA_Top_Module/SA6_P: J1.95; also elsewhere on the board
/FPGA_Top_Module/SA7_N: J1.100; also elsewhere on the board
/FPGA_Top_Module/SA7_P: J1.102; also elsewhere on the board
/FPGA_Top_Module/SA8_N: J1.104; also elsewhere on the board
/FPGA_Top_Module/SA8_P: J1.106; also elsewhere on the board
/FPGA_Top_Module/SB0_N: J1.107; also elsewhere on the board
/FPGA_Top_Module/SB0_P: J1.109; also elsewhere on the board
/FPGA_Top_Module/SB1_N: J1.111; also elsewhere on the board
/FPGA_Top_Module/SB1_P: J1.113; also elsewhere on the board
/FPGA_Top_Module/SB2_N: J1.115; also elsewhere on the board
/FPGA_Top_Module/SB2_P: J1.117; also elsewhere on the board
/FPGA_Top_Module/SB3_N: J1.119; also elsewhere on the board
/FPGA_Top_Module/SB3_P: J1.121; also elsewhere on the board
/FPGA_Top_Module/SB4_N: J1.108; also elsewhere on the board
/FPGA_Top_Module/SB4_P: J1.110; also elsewhere on the board
/FPGA_Top_Module/SB7: J1.118; also elsewhere on the board
/FPGA_Top_Module/SB8: J1.120; also elsewhere on the board
/FPGA_Top_Module/TCK: J1.21; also elsewhere on the board
/FPGA_Top_Module/TDI: J1.25; also elsewhere on the board
/FPGA_Top_Module/TDO: J1.27; also elsewhere on the board
/FPGA_Top_Module/TMS: J1.23; also elsewhere on the board
/FPGA_Top_Module/TX0_N: J1.30; also elsewhere on the board
/FPGA_Top_Module/TX0_P: J1.32; also elsewhere on the board
/FPGA_Top_Module/TX1_N: J1.48; also elsewhere on the board
/FPGA_Top_Module/TX1_P: J1.50; also elsewhere on the board
/FPGA_Top_Module/WB: J1.12; also elsewhere on the board
/FPGA_Top_Module/WB0_N: J1.84; also elsewhere on the board
/FPGA_Top_Module/WB0_P: J1.86; also elsewhere on the board
/FPGA_Top_Module/WB1_N: J1.80; also elsewhere on the board
/FPGA_Top_Module/WB1_P: J1.82; also elsewhere on the board
/FPGA_Top_Module/WB2_N: J1.77; also elsewhere on the board
/FPGA_Top_Module/WB2_P: J1.79; also elsewhere on the board
/FPGA_Top_Module/WB3_N: J1.76; also elsewhere on the board
/FPGA_Top_Module/WB3_P: J1.78; also elsewhere on the board
/FPGA_Top_Module/WB4_N: J1.73; also elsewhere on the board
/FPGA_Top_Module/WB4_P: J1.75; also elsewhere on the board
/FPGA_Top_Module/WB5_N: J1.72; also elsewhere on the board
/FPGA_Top_Module/WB5_P: J1.74; also elsewhere on the board
/FPGA_Top_Module/WB6_N: J1.69; also elsewhere on the board
/FPGA_Top_Module/WB6_P: J1.71; also elsewhere on the board
/FPGA_Top_Module/WB7_N: J1.68; also elsewhere on the board
/FPGA_Top_Module/WB7_P: J1.70; also elsewhere on the board
/FPGA_Top_Module/WB8_N: J1.65; also elsewhere on the board
/FPGA_Top_Module/WB8_P: J1.67; also elsewhere on the board
/FPGA_Top_Module/WC: J1.8; also elsewhere on the board
/FPGA_Top_Module/WC0_N: J1.64; also elsewhere on the board
/FPGA_Top_Module/WC0_P: J1.66; also elsewhere on the board
/FPGA_Top_Module/WC1_N: J1.61; also elsewhere on the board
/FPGA_Top_Module/WC1_P: J1.63; also elsewhere on the board
/FPGA_Top_Module/WC2_N: J1.60; also elsewhere on the board
/FPGA_Top_Module/WC2_P: J1.62; also elsewhere on the board
/FPGA_Top_Module/WC3_N: J1.57; also elsewhere on the board
/FPGA_Top_Module/WC3_P: J1.59; also elsewhere on the board
/FPGA_Top_Module/WC4_N: J1.56; also elsewhere on the board
/FPGA_Top_Module/WC4_P: J1.58; also elsewhere on the board
/FPGA_Top_Module/WC5_N: J1.53; also elsewhere on the board
/FPGA_Top_Module/WC5_P: J1.55; also elsewhere on the board
/FPGA_Top_Module/WC6_N: J1.49; also elsewhere on the board
/FPGA_Top_Module/WC6_P: J1.51; also elsewhere on the board
/FPGA_Top_Module/WC7_N: J1.45; also elsewhere on the board
/FPGA_Top_Module/WC7_P: J1.47; also elsewhere on the board
/FPGA_Top_Module/WC8_N: J1.41; also elsewhere on the board
/FPGA_Top_Module/WC8_P: J1.43; also elsewhere on the board
/FPGA_Top_Module/~CFG_Failed: J1.31; also elsewhere on the board
/FPGA_Top_Module/~Rst: J1.18; also elsewhere on the board
GND: J1.2, J1.3, J1.6, J1.7, J1.10, J1.11, J1.14, J1.15, J1.19, J1.20, J1.22, J1.28, J1.34, J1.40, J1.46, J1.52, J1.54, J1.97, J1.101, J1.105, J1.112, J1.116, J1.122, J1.144, J1.159, J1.162, J1.180, J1.181, J1.199; also elsewhere on the board

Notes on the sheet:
SERDES Termination

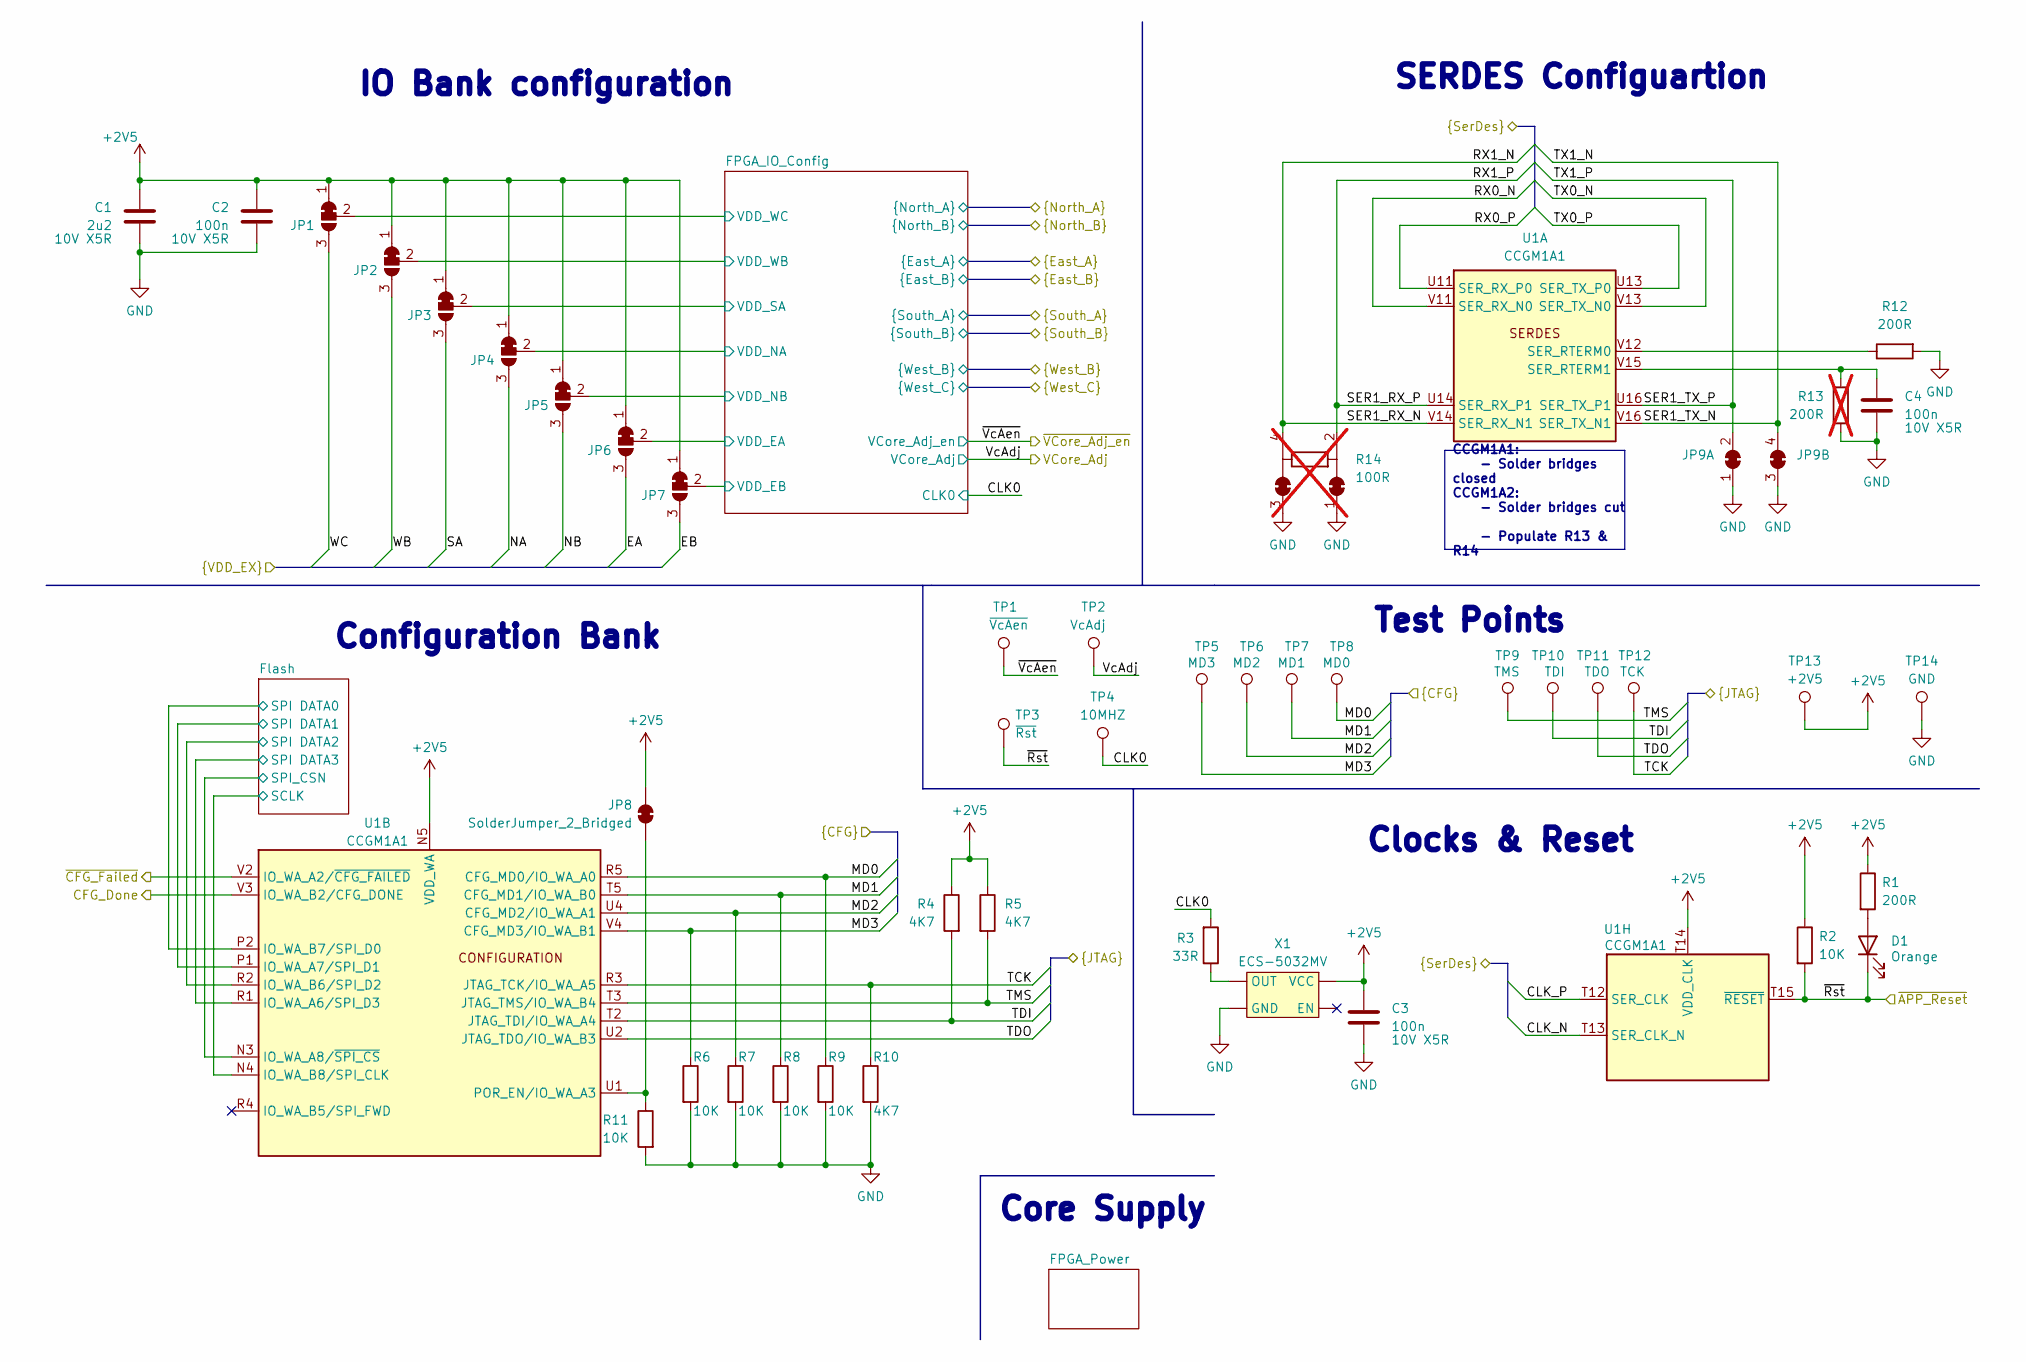
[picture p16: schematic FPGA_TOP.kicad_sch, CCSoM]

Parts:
C1: 2u2; C_0402_1005Metric; Voltage/Precision 10V X5R; Mouser Part Number GRM155Z71A225KE44D
C2, C3, C4: 100n; C_0402_1005Metric; Voltage/Precision 10V X5R; Mouser Part Number GRM155R71C104KA88J
D1: Orange; LED_0603_1608Metric; Mouser Part Number APT1608SECK-AMT
JP1, JP2, JP3, JP4, JP5, JP6, JP7: SolderJumper_3_Bridged12; SolderBridge3Pin
JP8: SolderJumper_2_Bridged; Solderbridge_closed
JP9: Diff_pair_solderbridge_closed
R1, R12: 200R; R_0402_1005Metric; Mouser Part Number MCS04020C2000FE000
R2, R6, R7, R8, R9, R11: 10K; R_0402_1005Metric; Mouser Part Number MCS0402MC1002FE000
R3: 33R; R_0402_1005Metric; Mouser Part Number MCS04020C3309FE000
R4, R5, R10: 4K7; R_0402_1005Metric; Mouser Part Number CRCW04024K70FKED
R13: 200R; R_0402_1005Metric; Mouser Part Number 71-CRCW0201-200; not fitted
R14: 100R; Diff_pair_solderbridge_closed; not fitted
TP1: ~{VcAen}; TestPoint_Pad_D1.0mm
TP2: VcAdj; TestPoint_Pad_D1.0mm
TP3: ~{Rst}; TestPoint_Pad_D1.0mm
TP4: 10MHZ; TestPoint_Pad_D1.0mm
TP5: MD3; TestPoint_Pad_D1.0mm
TP6: MD2; TestPoint_Pad_D1.0mm
TP7: MD1; TestPoint_Pad_D1.0mm
TP8: MD0; TestPoint_Pad_D1.0mm
TP9: TMS; TestPoint_Pad_D1.0mm
TP10: TDI; TestPoint_Pad_D1.0mm
TP11: TDO; TestPoint_Pad_D1.0mm
TP12: TCK; TestPoint_Pad_D1.0mm
TP13: +2V5; TestPoint_Pad_D1.0mm
TP14: GND; TestPoint_Pad_D1.0mm
U1: CCGM1A1; BGA-324_15.0x15.0mm_Layout18x18_P0.8mm_Ball0.45mm_Pad0.4mm_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; Mouser Part Number CCGM1A1-BGA324
X1: ECS-5032MV; 5x3.2_Oscillator; Mouser Part Number ECS-5032MV-100-BN-TR

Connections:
+2V5: C1.1, C2.1, C3.1, JP1.1 (A), JP2.1 (A), JP3.1 (A), JP4.1 (A), JP5.1 (A), JP6.1 (A), JP7.1 (A), JP8.2 (B), R1.1, R2.1, R4.1, R5.1, TP13.1, U1.N5 (VDD_WA), U1.P3 (VDD_WA), U1.P5 (VDD_WA), U1.T1 (VDD_WA), U1.T14 (VDD_CLK), U1.U3 (VDD_WA), X1.4 (VCC); also elsewhere on the board
/FPGA_Top_Module/CFG_Done: U1.V3 (IO_WA_B2/CFG_DONE); also elsewhere on the board
/FPGA_Top_Module/CLK0: R3.2, TP4.1; also elsewhere on the board
/FPGA_Top_Module/CLK_N: U1.T13 (SER_CLK_N); also elsewhere on the board
/FPGA_Top_Module/CLK_P: U1.T12 (SER_CLK); also elsewhere on the board
/FPGA_Top_Module/EA: JP6.3 (B); also elsewhere on the board
/FPGA_Top_Module/EB: JP7.3 (B); also elsewhere on the board
/FPGA_Top_Module/FPGA_IO_Config/VDD_EA: JP6.2 (C); also elsewhere on the board
/FPGA_Top_Module/FPGA_IO_Config/VDD_EB: JP7.2 (C); also elsewhere on the board
/FPGA_Top_Module/FPGA_IO_Config/VDD_NA: JP4.2 (C); also elsewhere on the board
/FPGA_Top_Module/FPGA_IO_Config/VDD_NB: JP5.2 (C); also elsewhere on the board
/FPGA_Top_Module/FPGA_IO_Config/VDD_SA: JP3.2 (C); also elsewhere on the board
/FPGA_Top_Module/FPGA_IO_Config/VDD_WB: JP2.2 (C); also elsewhere on the board
/FPGA_Top_Module/FPGA_IO_Config/VDD_WC: JP1.2 (C); also elsewhere on the board
/FPGA_Top_Module/Flash/SCLK: U1.N4 (IO_WA_B8/SPI_CLK); also elsewhere on the board
/FPGA_Top_Module/Flash/SPI DATA0: U1.P2 (IO_WA_B7/SPI_D0); also elsewhere on the board
/FPGA_Top_Module/Flash/SPI DATA1: U1.P1 (IO_WA_A7/SPI_D1); also elsewhere on the board
/FPGA_Top_Module/Flash/SPI DATA2: U1.R2 (IO_WA_B6/SPI_D2); also elsewhere on the board
/FPGA_Top_Module/Flash/SPI DATA3: U1.R1 (IO_WA_A6/SPI_D3); also elsewhere on the board
/FPGA_Top_Module/Flash/SPI_CSN: U1.N3 (IO_WA_A8/~SPI_CS); also elsewhere on the board
/FPGA_Top_Module/MD0: R9.1, TP8.1, U1.R5 (CFG_MD0/IO_WA_A0); also elsewhere on the board
/FPGA_Top_Module/MD1: R8.1, TP7.1, U1.T5 (CFG_MD1/IO_WA_B0); also elsewhere on the board
/FPGA_Top_Module/MD2: R7.1, TP6.1, U1.U4 (CFG_MD2/IO_WA_A1); also elsewhere on the board
/FPGA_Top_Module/MD3: R6.1, TP5.1, U1.V4 (CFG_MD3/IO_WA_B1); also elsewhere on the board
/FPGA_Top_Module/NA: JP4.3 (B); also elsewhere on the board
/FPGA_Top_Module/NB: JP5.3 (B); also elsewhere on the board
/FPGA_Top_Module/RX0_N: U1.V11 (SER_RX_N0); also elsewhere on the board
/FPGA_Top_Module/RX0_P: U1.U11 (SER_RX_P0); also elsewhere on the board
/FPGA_Top_Module/RX1_N: R14.4, U1.V14 (SER_RX_N1); also elsewhere on the board
/FPGA_Top_Module/RX1_P: R14.2, U1.U14 (SER_RX_P1); also elsewhere on the board
/FPGA_Top_Module/SA: JP3.3 (B); also elsewhere on the board
/FPGA_Top_Module/TCK: R10.1, TP12.1, U1.R3 (JTAG_TCK/IO_WA_A5); also elsewhere on the board
/FPGA_Top_Module/TDI: R4.2, TP10.1, U1.T2 (JTAG_TDI/IO_WA_A4); also elsewhere on the board
/FPGA_Top_Module/TDO: TP11.1, U1.U2 (JTAG_TDO/IO_WA_B3); also elsewhere on the board
/FPGA_Top_Module/TMS: R5.2, TP9.1, U1.T3 (JTAG_TMS/IO_WA_B4); also elsewhere on the board
/FPGA_Top_Module/TX0_N: U1.V13 (SER_TX_N0); also elsewhere on the board
/FPGA_Top_Module/TX0_P: U1.U13 (SER_TX_P0); also elsewhere on the board
/FPGA_Top_Module/TX1_N: JP9.4 (B), U1.V16 (SER_TX_N1); also elsewhere on the board
/FPGA_Top_Module/TX1_P: JP9.2 (B), U1.U16 (SER_TX_P1); also elsewhere on the board
/FPGA_Top_Module/VcAdj: TP2.1; also elsewhere on the board
/FPGA_Top_Module/WB: JP2.3 (B); also elsewhere on the board
/FPGA_Top_Module/WC: JP1.3 (B); also elsewhere on the board
/FPGA_Top_Module/~CFG_Failed: U1.V2 (IO_WA_A2/~CFG_FAILED); also elsewhere on the board
/FPGA_Top_Module/~Rst: D1.1 (K), R2.2, TP3.1, U1.T15 (~RESET); also elsewhere on the board
/FPGA_Top_Module/~VcAen: TP1.1; also elsewhere on the board
GND: C1.2, C2.2, C3.2, C4.2, JP9.1 (A), JP9.3 (A), R6.2, R7.2, R8.2, R9.2, R10.2, R11.2, R12.2, R13.2, R14.1 (A), R14.3 (A), TP14.1, X1.2 (GND); also elsewhere on the board
unnamed: D1.2 (A), R1.2
unnamed: JP8.1 (A), R11.1, U1.U1 (POR_EN/IO_WA_A3)
unnamed: R12.1, U1.V12 (SER_RTERM0)
unnamed: C4.1, R13.1, U1.V15 (SER_RTERM1)
unnamed: R3.1, X1.3 (OUT)

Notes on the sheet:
Test Points
IO Bank configuration
Core Supply
Clocks & Reset
SERDES Configuartion
Configuration Bank
CCGM1A1: - Solder bridges closed CCGM1A2: - Solder bridges cut - Populate R13 & R14

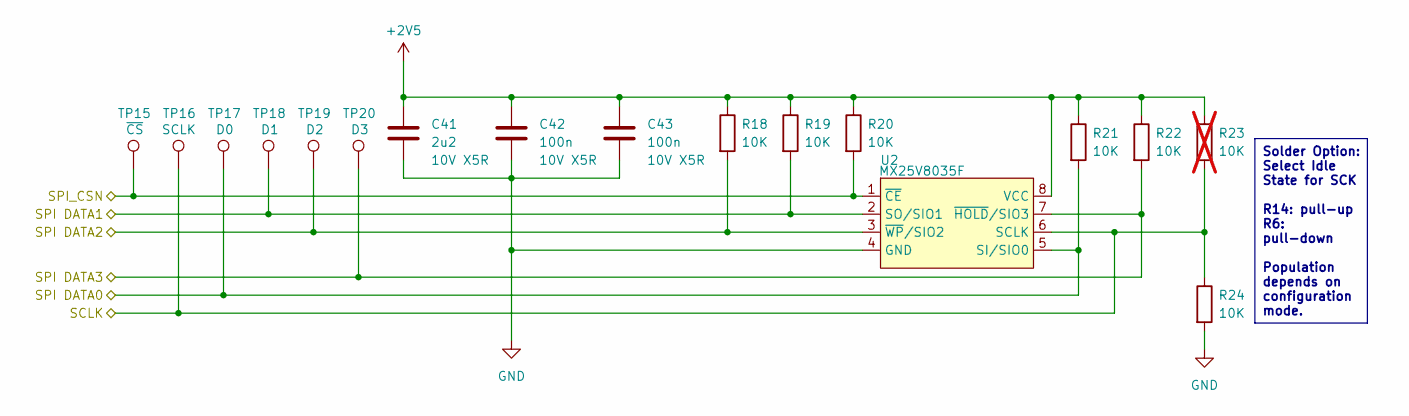
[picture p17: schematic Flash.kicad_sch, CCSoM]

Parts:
C41: 2u2; C_0402_1005Metric; Voltage/Precision 10V X5R; Mouser Part Number GRM155Z71A225KE44D
C42, C43: 100n; C_0402_1005Metric; Voltage/Precision 10V X5R; Mouser Part Number GRM155R71C104KA88J
R18, R19, R20, R21, R22, R24: 10K; R_0402_1005Metric; Mouser Part Number MCS0402MC1002FE000
R23: 10K; R_0402_1005Metric; Mouser Part Number 71-CRCW0201-10K; not fitted
TP15: ~{CS}; TestPoint_Pad_D1.0mm
TP16: SCLK; TestPoint_Pad_D1.0mm
TP17: D0; TestPoint_Pad_D1.0mm
TP18: D1; TestPoint_Pad_D1.0mm
TP19: D2; TestPoint_Pad_D1.0mm
TP20: D3; TestPoint_Pad_D1.0mm
U2: MX25V8035F; SOP-8(150_200MIL); Mouser Part Number MX25V8035FM2I

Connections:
+2V5: C41.1, C42.1, C43.1, R18.1, R19.1, R20.1, R21.1, R22.1, R23.1, U2.8 (VCC); also elsewhere on the board
/FPGA_Top_Module/Flash/SCLK: R23.2, R24.1, TP16.1, U2.6 (SCLK); also elsewhere on the board
/FPGA_Top_Module/Flash/SPI DATA0: R21.2, TP17.1, U2.5 (SI/SIO0); also elsewhere on the board
/FPGA_Top_Module/Flash/SPI DATA1: R19.2, TP18.1, U2.2 (SO/SIO1); also elsewhere on the board
/FPGA_Top_Module/Flash/SPI DATA2: R18.2, TP19.1, U2.3 (~WP/SIO2); also elsewhere on the board
/FPGA_Top_Module/Flash/SPI DATA3: R22.2, TP20.1, U2.7 (~HOLD/SIO3); also elsewhere on the board
/FPGA_Top_Module/Flash/SPI_CSN: R20.2, TP15.1, U2.1 (~CE); also elsewhere on the board
GND: C41.2, C42.2, C43.2, R24.2, U2.4 (GND); also elsewhere on the board

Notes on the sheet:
Solder Option: Select Idle State for SCK R14: pull-up R6: pull-down Population depends on configuration mode.

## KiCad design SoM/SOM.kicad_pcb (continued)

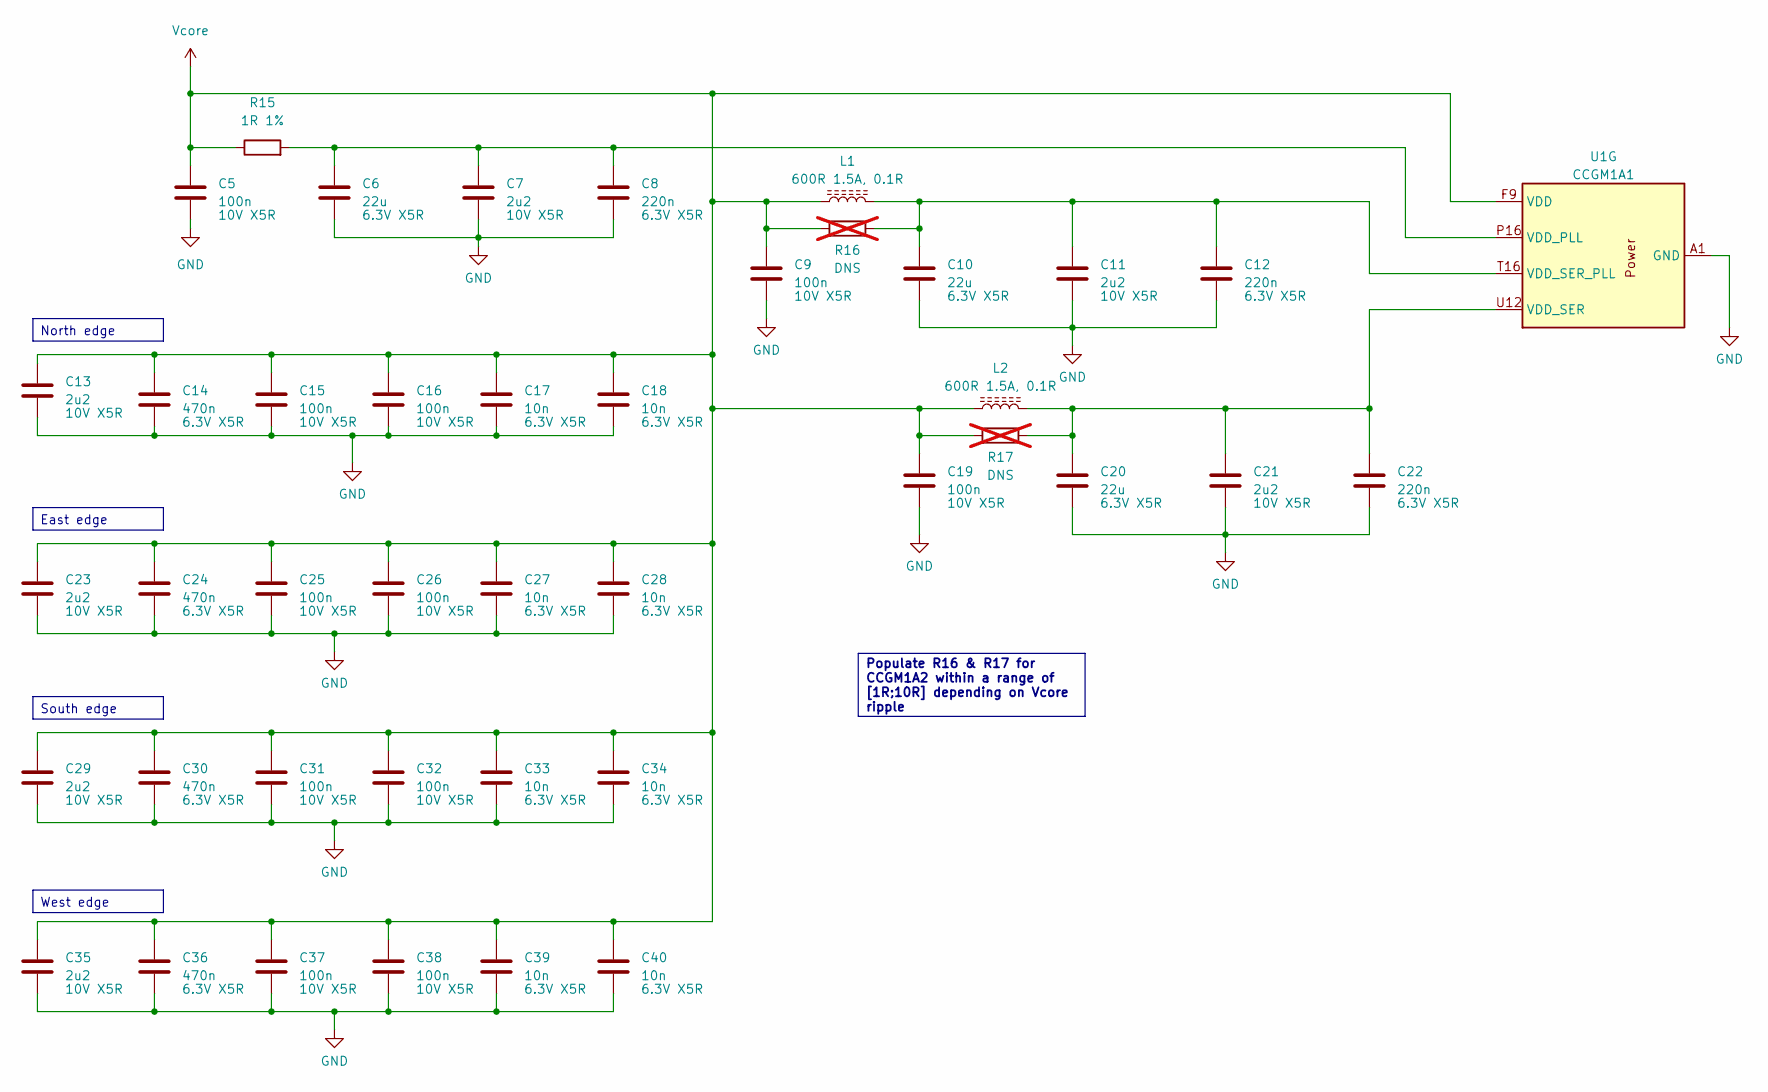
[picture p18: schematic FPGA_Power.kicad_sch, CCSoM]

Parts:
C5, C9, C15, C16, C19, C25, C26, C31, C32, C37, C38: 100n; C_0402_1005Metric; Voltage/Precision 10V X5R; Mouser Part Number GRM155R71C104KA88J
C6, C10, C20: 22u; C_0603_1608Metric; Voltage/Precision 6.3V X5R; Mouser Part Number GRM188C61C226ME01W
C7, C11, C13, C21, C23, C29, C35: 2u2; C_0402_1005Metric; Voltage/Precision 10V X5R; Mouser Part Number GRM155Z71A225KE44D
C8, C12, C22: 220n; C_0402_1005Metric; Voltage/Precision 6.3V X5R; Mouser Part Number GRM155R71C224KA12D
C14, C24, C30, C36: 470n; C_0402_1005Metric; Voltage/Precision 6.3V X5R; Mouser Part Number GRT155C81C474KE01D
C17, C18, C27, C28, C33, C34, C39, C40: 10n; C_0402_1005Metric; Voltage/Precision 6.3V X5R; Mouser Part Number GRM155R71C103KA01D
L1, L2: 600R 1.5A, 0.1R; C_0603_1608Metric; Mouser Part Number 74269262601
R15: 1R 1%; R_0402_1005Metric; Mouser Part Number CRCW04021R00FKEDHP
R16, R17: DNS; R_0402_1005Metric; Mouser Part Number 71-CRCW020133R0FNED; not fitted
U1: CCGM1A1; BGA-324_15.0x15.0mm_Layout18x18_P0.8mm_Ball0.45mm_Pad0.4mm_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; Mouser Part Number CCGM1A1-BGA324

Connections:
GND: C5.2, C6.2, C7.2, C8.2, C9.2, C10.2, C11.2, C12.2, C13.2, C14.2, C15.2, C16.2, C17.2, C18.2, C19.2, C20.2, C21.2, C22.2, C23.2, C24.2, C25.2, C26.2, C27.2, C28.2, C29.2, C30.2, C31.2, C32.2, C33.2, C34.2, C35.2, C36.2, C37.2, C38.2, C39.2, C40.2, U1.A1 (GND), U1.A7 (GND), U1.A10 (GND), U1.A13 (GND), U1.A18 (GND), U1.B16 (GND), U1.C1 (GND), U1.E5 (GND), U1.E7 (GND), U1.E9 (GND), U1.E11 (GND), U1.E13 (GND), U1.E18 (GND), U1.F1 (GND), U1.F6 (GND), U1.F8 (GND), U1.F10 (GND), U1.F12 (GND), U1.F14 (GND), U1.G5 (GND), U1.G7 (GND), U1.G9 (GND), U1.G11 (GND), U1.G13 (GND), U1.H6 (GND), U1.H8 (GND), U1.H10 (GND), U1.H12 (GND), U1.H14 (GND), U1.H18 (GND), U1.J1 (GND), U1.J5 (GND), U1.J7 (GND), U1.J9 (GND), U1.J11 (GND), U1.J13 (GND), U1.K6 (GND), U1.K8 (GND), U1.K10 (GND), U1.K12 (GND), U1.K14 (GND), U1.L5 (GND), U1.L7 (GND), U1.L9 (GND), U1.L11 (GND), U1.L13 (GND), U1.L18 (GND), U1.M1 (GND), U1.M6 (GND), U1.M8 (GND), U1.M10 (GND), U1.M12 (GND), U1.M16 (GND), U1.N7 (GND), U1.N9 (GND), U1.N12 (GND), U1.N17 (GND), U1.P4 (GND), U1.P7 (GND), U1.P9 (GND), U1.R12 (GND), U1.R16 (GND), U1.T4 (GND), U1.T11 (GND), U1.T17 (GND), U1.U15 (GND), U1.V1 (GND), U1.V6 (GND), U1.V9 (GND), U1.V18 (GND); also elsewhere on the board
unnamed: C20.1, C21.1, C22.1, L2.2, R17.1, U1.U12 (VDD_SER), U1.V17 (VDD_SER)
unnamed: C6.1, C7.1, C8.1, R15.2, U1.P16 (VDD_PLL)
unnamed: C10.1, C11.1, C12.1, L1.2, R16.1, U1.T16 (VDD_SER_PLL)
Vcore: C5.1, C9.1, C13.1, C14.1, C15.1, C16.1, C17.1, C18.1, C19.1, C23.1, C24.1, C25.1, C26.1, C27.1, C28.1, C29.1, C30.1, C31.1, C32.1, C33.1, C34.1, C35.1, C36.1, C37.1, C38.1, C39.1, C40.1, L1.1, L2.1, R15.1, R16.2, R17.2, U1.F9 (VDD), U1.G6 (VDD), U1.G8 (VDD), U1.G10 (VDD), U1.G12 (VDD), U1.H7 (VDD), U1.H9 (VDD), U1.H11 (VDD), U1.H13 (VDD), U1.J6 (VDD), U1.J8 (VDD), U1.J10 (VDD), U1.J12 (VDD), U1.K7 (VDD), U1.K9 (VDD), U1.K11 (VDD), U1.K13 (VDD), U1.L6 (VDD), U1.L8 (VDD), U1.L10 (VDD), U1.L12 (VDD), U1.M7 (VDD), U1.M9 (VDD), U1.M11 (VDD), U1.M13 (VDD), U1.N6 (VDD), U1.N8 (VDD), U1.N10 (VDD); also elsewhere on the board

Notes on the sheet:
East edge
North edge
South edge
Populate R16 & R17 for CCGM1A2 within a range of [1R;10R] depending on Vcore ripple
West edge

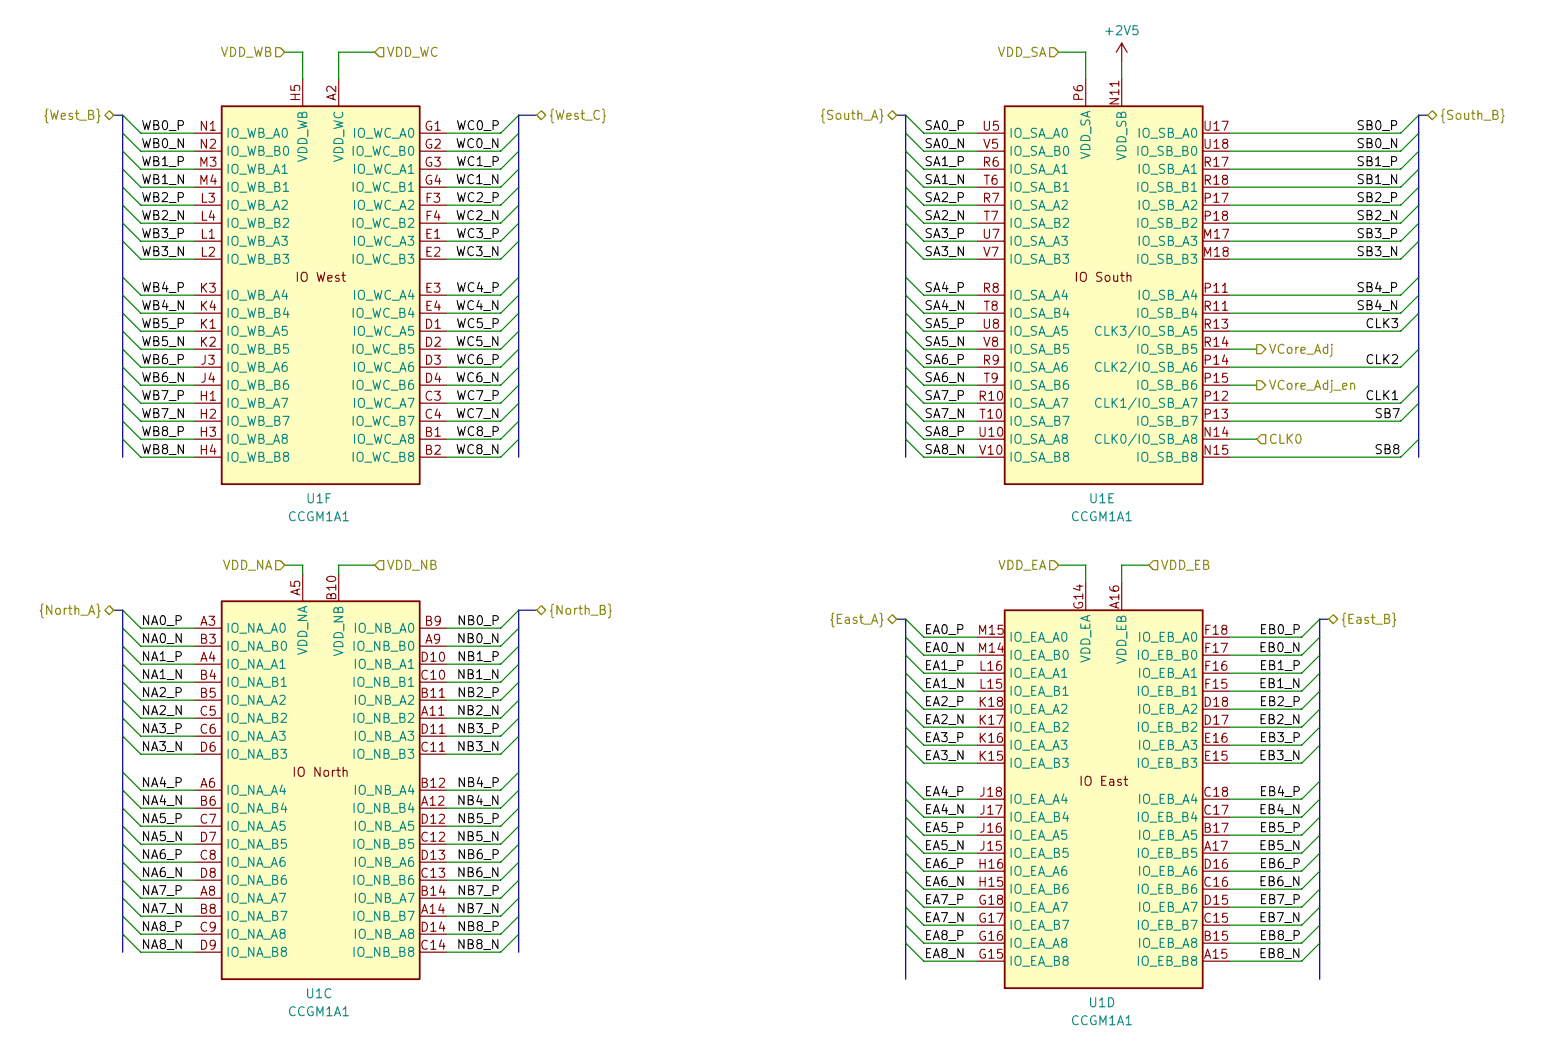
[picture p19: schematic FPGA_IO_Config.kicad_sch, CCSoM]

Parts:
U1: CCGM1A1; BGA-324_15.0x15.0mm_Layout18x18_P0.8mm_Ball0.45mm_Pad0.4mm_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; Mouser Part Number CCGM1A1-BGA324

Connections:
+2V5: U1.N11 (VDD_SB), U1.N13 (VDD_SB), U1.N18 (VDD_SB), U1.R15 (VDD_SB), U1.T18 (VDD_SB); also elsewhere on the board
/FPGA_Top_Module/CLK0: U1.N14 (CLK0/IO_SB_A8); also elsewhere on the board
/FPGA_Top_Module/CLK1: U1.P12 (CLK1/IO_SB_A7); also elsewhere on the board
/FPGA_Top_Module/CLK2: U1.P14 (CLK2/IO_SB_A6); also elsewhere on the board
/FPGA_Top_Module/CLK3: U1.R13 (CLK3/IO_SB_A5); also elsewhere on the board
/FPGA_Top_Module/EA0_N: U1.M14 (IO_EA_B0); also elsewhere on the board
/FPGA_Top_Module/EA0_P: U1.M15 (IO_EA_A0); also elsewhere on the board
/FPGA_Top_Module/EA1_N: U1.L15 (IO_EA_B1); also elsewhere on the board
/FPGA_Top_Module/EA1_P: U1.L16 (IO_EA_A1); also elsewhere on the board
/FPGA_Top_Module/EA2_N: U1.K17 (IO_EA_B2); also elsewhere on the board
/FPGA_Top_Module/EA2_P: U1.K18 (IO_EA_A2); also elsewhere on the board
/FPGA_Top_Module/EA3_N: U1.K15 (IO_EA_B3); also elsewhere on the board
/FPGA_Top_Module/EA3_P: U1.K16 (IO_EA_A3); also elsewhere on the board
/FPGA_Top_Module/EA4_N: U1.J17 (IO_EA_B4); also elsewhere on the board
/FPGA_Top_Module/EA4_P: U1.J18 (IO_EA_A4); also elsewhere on the board
/FPGA_Top_Module/EA5_N: U1.J15 (IO_EA_B5); also elsewhere on the board
/FPGA_Top_Module/EA5_P: U1.J16 (IO_EA_A5); also elsewhere on the board
/FPGA_Top_Module/EA6_N: U1.H15 (IO_EA_B6); also elsewhere on the board
/FPGA_Top_Module/EA6_P: U1.H16 (IO_EA_A6); also elsewhere on the board
/FPGA_Top_Module/EA7_N: U1.G17 (IO_EA_B7); also elsewhere on the board
/FPGA_Top_Module/EA7_P: U1.G18 (IO_EA_A7); also elsewhere on the board
/FPGA_Top_Module/EA8_N: U1.G15 (IO_EA_B8); also elsewhere on the board
/FPGA_Top_Module/EA8_P: U1.G16 (IO_EA_A8); also elsewhere on the board
/FPGA_Top_Module/EB0_N: U1.F17 (IO_EB_B0); also elsewhere on the board
/FPGA_Top_Module/EB0_P: U1.F18 (IO_EB_A0); also elsewhere on the board
/FPGA_Top_Module/EB1_N: U1.F15 (IO_EB_B1); also elsewhere on the board
/FPGA_Top_Module/EB1_P: U1.F16 (IO_EB_A1); also elsewhere on the board
/FPGA_Top_Module/EB2_N: U1.D17 (IO_EB_B2); also elsewhere on the board
/FPGA_Top_Module/EB2_P: U1.D18 (IO_EB_A2); also elsewhere on the board
/FPGA_Top_Module/EB3_N: U1.E15 (IO_EB_B3); also elsewhere on the board
/FPGA_Top_Module/EB3_P: U1.E16 (IO_EB_A3); also elsewhere on the board
/FPGA_Top_Module/EB4_N: U1.C17 (IO_EB_B4); also elsewhere on the board
/FPGA_Top_Module/EB4_P: U1.C18 (IO_EB_A4); also elsewhere on the board
/FPGA_Top_Module/EB5_N: U1.A17 (IO_EB_B5); also elsewhere on the board
/FPGA_Top_Module/EB5_P: U1.B17 (IO_EB_A5); also elsewhere on the board
/FPGA_Top_Module/EB6_N: U1.C16 (IO_EB_B6); also elsewhere on the board
/FPGA_Top_Module/EB6_P: U1.D16 (IO_EB_A6); also elsewhere on the board
/FPGA_Top_Module/EB7_N: U1.C15 (IO_EB_B7); also elsewhere on the board
/FPGA_Top_Module/EB7_P: U1.D15 (IO_EB_A7); also elsewhere on the board
/FPGA_Top_Module/EB8_N: U1.A15 (IO_EB_B8); also elsewhere on the board
/FPGA_Top_Module/EB8_P: U1.B15 (IO_EB_A8); also elsewhere on the board
/FPGA_Top_Module/FPGA_IO_Config/VDD_EA: U1.G14 (VDD_EA), U1.H17 (VDD_EA), U1.J14 (VDD_EA), U1.L14 (VDD_EA), U1.L17 (VDD_EA); also elsewhere on the board
/FPGA_Top_Module/FPGA_IO_Config/VDD_EB: U1.A16 (VDD_EB), U1.B18 (VDD_EB), U1.E14 (VDD_EB), U1.E17 (VDD_EB), U1.F13 (VDD_EB); also elsewhere on the board
/FPGA_Top_Module/FPGA_IO_Config/VDD_NA: U1.A5 (VDD_NA), U1.B7 (VDD_NA), U1.E6 (VDD_NA), U1.E8 (VDD_NA), U1.F7 (VDD_NA); also elsewhere on the board
/FPGA_Top_Module/FPGA_IO_Config/VDD_NB: U1.B10 (VDD_NB), U1.B13 (VDD_NB), U1.E10 (VDD_NB), U1.E12 (VDD_NB), U1.F11 (VDD_NB); also elsewhere on the board
/FPGA_Top_Module/FPGA_IO_Config/VDD_SA: U1.P6 (VDD_SA), U1.P8 (VDD_SA), U1.P10 (VDD_SA), U1.U6 (VDD_SA), U1.U9 (VDD_SA); also elsewhere on the board
/FPGA_Top_Module/FPGA_IO_Config/VDD_WB: U1.H5 (VDD_WB), U1.J2 (VDD_WB), U1.K5 (VDD_WB), U1.M2 (VDD_WB), U1.M5 (VDD_WB); also elsewhere on the board
/FPGA_Top_Module/FPGA_IO_Config/VDD_WC: U1.A2 (VDD_WC), U1.C2 (VDD_WC), U1.D5 (VDD_WC), U1.F2 (VDD_WC), U1.F5 (VDD_WC); also elsewhere on the board
/FPGA_Top_Module/NA0_N: U1.B3 (IO_NA_B0); also elsewhere on the board
/FPGA_Top_Module/NA0_P: U1.A3 (IO_NA_A0); also elsewhere on the board
/FPGA_Top_Module/NA1_N: U1.B4 (IO_NA_B1); also elsewhere on the board
/FPGA_Top_Module/NA1_P: U1.A4 (IO_NA_A1); also elsewhere on the board
/FPGA_Top_Module/NA2_N: U1.C5 (IO_NA_B2); also elsewhere on the board
/FPGA_Top_Module/NA2_P: U1.B5 (IO_NA_A2); also elsewhere on the board
/FPGA_Top_Module/NA3_N: U1.D6 (IO_NA_B3); also elsewhere on the board
/FPGA_Top_Module/NA3_P: U1.C6 (IO_NA_A3); also elsewhere on the board
/FPGA_Top_Module/NA4_N: U1.B6 (IO_NA_B4); also elsewhere on the board
/FPGA_Top_Module/NA4_P: U1.A6 (IO_NA_A4); also elsewhere on the board
/FPGA_Top_Module/NA5_N: U1.D7 (IO_NA_B5); also elsewhere on the board
/FPGA_Top_Module/NA5_P: U1.C7 (IO_NA_A5); also elsewhere on the board
/FPGA_Top_Module/NA6_N: U1.D8 (IO_NA_B6); also elsewhere on the board
/FPGA_Top_Module/NA6_P: U1.C8 (IO_NA_A6); also elsewhere on the board
/FPGA_Top_Module/NA7_N: U1.B8 (IO_NA_B7); also elsewhere on the board
/FPGA_Top_Module/NA7_P: U1.A8 (IO_NA_A7); also elsewhere on the board
/FPGA_Top_Module/NA8_N: U1.D9 (IO_NA_B8); also elsewhere on the board
/FPGA_Top_Module/NA8_P: U1.C9 (IO_NA_A8); also elsewhere on the board
/FPGA_Top_Module/NB0_N: U1.A9 (IO_NB_B0); also elsewhere on the board
/FPGA_Top_Module/NB0_P: U1.B9 (IO_NB_A0); also elsewhere on the board
/FPGA_Top_Module/NB1_N: U1.C10 (IO_NB_B1); also elsewhere on the board
/FPGA_Top_Module/NB1_P: U1.D10 (IO_NB_A1); also elsewhere on the board
/FPGA_Top_Module/NB2_N: U1.A11 (IO_NB_B2); also elsewhere on the board
/FPGA_Top_Module/NB2_P: U1.B11 (IO_NB_A2); also elsewhere on the board
/FPGA_Top_Module/NB3_N: U1.C11 (IO_NB_B3); also elsewhere on the board
/FPGA_Top_Module/NB3_P: U1.D11 (IO_NB_A3); also elsewhere on the board
/FPGA_Top_Module/NB4_N: U1.A12 (IO_NB_B4); also elsewhere on the board
/FPGA_Top_Module/NB4_P: U1.B12 (IO_NB_A4); also elsewhere on the board
/FPGA_Top_Module/NB5_N: U1.C12 (IO_NB_B5); also elsewhere on the board
/FPGA_Top_Module/NB5_P: U1.D12 (IO_NB_A5); also elsewhere on the board
/FPGA_Top_Module/NB6_N: U1.C13 (IO_NB_B6); also elsewhere on the board
/FPGA_Top_Module/NB6_P: U1.D13 (IO_NB_A6); also elsewhere on the board
/FPGA_Top_Module/NB7_N: U1.A14 (IO_NB_B7); also elsewhere on the board
/FPGA_Top_Module/NB7_P: U1.B14 (IO_NB_A7); also elsewhere on the board
/FPGA_Top_Module/NB8_N: U1.C14 (IO_NB_B8); also elsewhere on the board
/FPGA_Top_Module/NB8_P: U1.D14 (IO_NB_A8); also elsewhere on the board
/FPGA_Top_Module/SA0_N: U1.V5 (IO_SA_B0); also elsewhere on the board
/FPGA_Top_Module/SA0_P: U1.U5 (IO_SA_A0); also elsewhere on the board
/FPGA_Top_Module/SA1_N: U1.T6 (IO_SA_B1); also elsewhere on the board
/FPGA_Top_Module/SA1_P: U1.R6 (IO_SA_A1); also elsewhere on the board
/FPGA_Top_Module/SA2_N: U1.T7 (IO_SA_B2); also elsewhere on the board
/FPGA_Top_Module/SA2_P: U1.R7 (IO_SA_A2); also elsewhere on the board
/FPGA_Top_Module/SA3_N: U1.V7 (IO_SA_B3); also elsewhere on the board
/FPGA_Top_Module/SA3_P: U1.U7 (IO_SA_A3); also elsewhere on the board
/FPGA_Top_Module/SA4_N: U1.T8 (IO_SA_B4); also elsewhere on the board
/FPGA_Top_Module/SA4_P: U1.R8 (IO_SA_A4); also elsewhere on the board
/FPGA_Top_Module/SA5_N: U1.V8 (IO_SA_B5); also elsewhere on the board
/FPGA_Top_Module/SA5_P: U1.U8 (IO_SA_A5); also elsewhere on the board
/FPGA_Top_Module/SA6_N: U1.T9 (IO_SA_B6); also elsewhere on the board
/FPGA_Top_Module/SA6_P: U1.R9 (IO_SA_A6); also elsewhere on the board
/FPGA_Top_Module/SA7_N: U1.T10 (IO_SA_B7); also elsewhere on the board
/FPGA_Top_Module/SA7_P: U1.R10 (IO_SA_A7); also elsewhere on the board
/FPGA_Top_Module/SA8_N: U1.V10 (IO_SA_B8); also elsewhere on the board
/FPGA_Top_Module/SA8_P: U1.U10 (IO_SA_A8); also elsewhere on the board
/FPGA_Top_Module/SB0_N: U1.U18 (IO_SB_B0); also elsewhere on the board
/FPGA_Top_Module/SB0_P: U1.U17 (IO_SB_A0); also elsewhere on the board
/FPGA_Top_Module/SB1_N: U1.R18 (IO_SB_B1); also elsewhere on the board
/FPGA_Top_Module/SB1_P: U1.R17 (IO_SB_A1); also elsewhere on the board
/FPGA_Top_Module/SB2_N: U1.P18 (IO_SB_B2); also elsewhere on the board
/FPGA_Top_Module/SB2_P: U1.P17 (IO_SB_A2); also elsewhere on the board
/FPGA_Top_Module/SB3_N: U1.M18 (IO_SB_B3); also elsewhere on the board
/FPGA_Top_Module/SB3_P: U1.M17 (IO_SB_A3); also elsewhere on the board
/FPGA_Top_Module/SB4_N: U1.R11 (IO_SB_B4); also elsewhere on the board
/FPGA_Top_Module/SB4_P: U1.P11 (IO_SB_A4); also elsewhere on the board
/FPGA_Top_Module/SB7: U1.P13 (IO_SB_B7); also elsewhere on the board
/FPGA_Top_Module/SB8: U1.N15 (IO_SB_B8); also elsewhere on the board
/FPGA_Top_Module/VcAdj: U1.R14 (IO_SB_B5); also elsewhere on the board
/FPGA_Top_Module/WB0_N: U1.N2 (IO_WB_B0); also elsewhere on the board
/FPGA_Top_Module/WB0_P: U1.N1 (IO_WB_A0); also elsewhere on the board
/FPGA_Top_Module/WB1_N: U1.M4 (IO_WB_B1); also elsewhere on the board
/FPGA_Top_Module/WB1_P: U1.M3 (IO_WB_A1); also elsewhere on the board
/FPGA_Top_Module/WB2_N: U1.L4 (IO_WB_B2); also elsewhere on the board
/FPGA_Top_Module/WB2_P: U1.L3 (IO_WB_A2); also elsewhere on the board
/FPGA_Top_Module/WB3_N: U1.L2 (IO_WB_B3); also elsewhere on the board
/FPGA_Top_Module/WB3_P: U1.L1 (IO_WB_A3); also elsewhere on the board
/FPGA_Top_Module/WB4_N: U1.K4 (IO_WB_B4); also elsewhere on the board
/FPGA_Top_Module/WB4_P: U1.K3 (IO_WB_A4); also elsewhere on the board
/FPGA_Top_Module/WB5_N: U1.K2 (IO_WB_B5); also elsewhere on the board
/FPGA_Top_Module/WB5_P: U1.K1 (IO_WB_A5); also elsewhere on the board
/FPGA_Top_Module/WB6_N: U1.J4 (IO_WB_B6); also elsewhere on the board
/FPGA_Top_Module/WB6_P: U1.J3 (IO_WB_A6); also elsewhere on the board
/FPGA_Top_Module/WB7_N: U1.H2 (IO_WB_B7); also elsewhere on the board
/FPGA_Top_Module/WB7_P: U1.H1 (IO_WB_A7); also elsewhere on the board
/FPGA_Top_Module/WB8_N: U1.H4 (IO_WB_B8); also elsewhere on the board
/FPGA_Top_Module/WB8_P: U1.H3 (IO_WB_A8); also elsewhere on the board
/FPGA_Top_Module/WC0_N: U1.G2 (IO_WC_B0); also elsewhere on the board
/FPGA_Top_Module/WC0_P: U1.G1 (IO_WC_A0); also elsewhere on the board
/FPGA_Top_Module/WC1_N: U1.G4 (IO_WC_B1); also elsewhere on the board
/FPGA_Top_Module/WC1_P: U1.G3 (IO_WC_A1); also elsewhere on the board
/FPGA_Top_Module/WC2_N: U1.F4 (IO_WC_B2); also elsewhere on the board
/FPGA_Top_Module/WC2_P: U1.F3 (IO_WC_A2); also elsewhere on the board
/FPGA_Top_Module/WC3_N: U1.E2 (IO_WC_B3); also elsewhere on the board
/FPGA_Top_Module/WC3_P: U1.E1 (IO_WC_A3); also elsewhere on the board
/FPGA_Top_Module/WC4_N: U1.E4 (IO_WC_B4); also elsewhere on the board
/FPGA_Top_Module/WC4_P: U1.E3 (IO_WC_A4); also elsewhere on the board
/FPGA_Top_Module/WC5_N: U1.D2 (IO_WC_B5); also elsewhere on the board
/FPGA_Top_Module/WC5_P: U1.D1 (IO_WC_A5); also elsewhere on the board
/FPGA_Top_Module/WC6_N: U1.D4 (IO_WC_B6); also elsewhere on the board
/FPGA_Top_Module/WC6_P: U1.D3 (IO_WC_A6); also elsewhere on the board
/FPGA_Top_Module/WC7_N: U1.C4 (IO_WC_B7); also elsewhere on the board
/FPGA_Top_Module/WC7_P: U1.C3 (IO_WC_A7); also elsewhere on the board
/FPGA_Top_Module/WC8_N: U1.B2 (IO_WC_B8); also elsewhere on the board
/FPGA_Top_Module/WC8_P: U1.B1 (IO_WC_A8); also elsewhere on the board
/FPGA_Top_Module/~VcAen: U1.P15 (IO_SB_B6); also elsewhere on the board

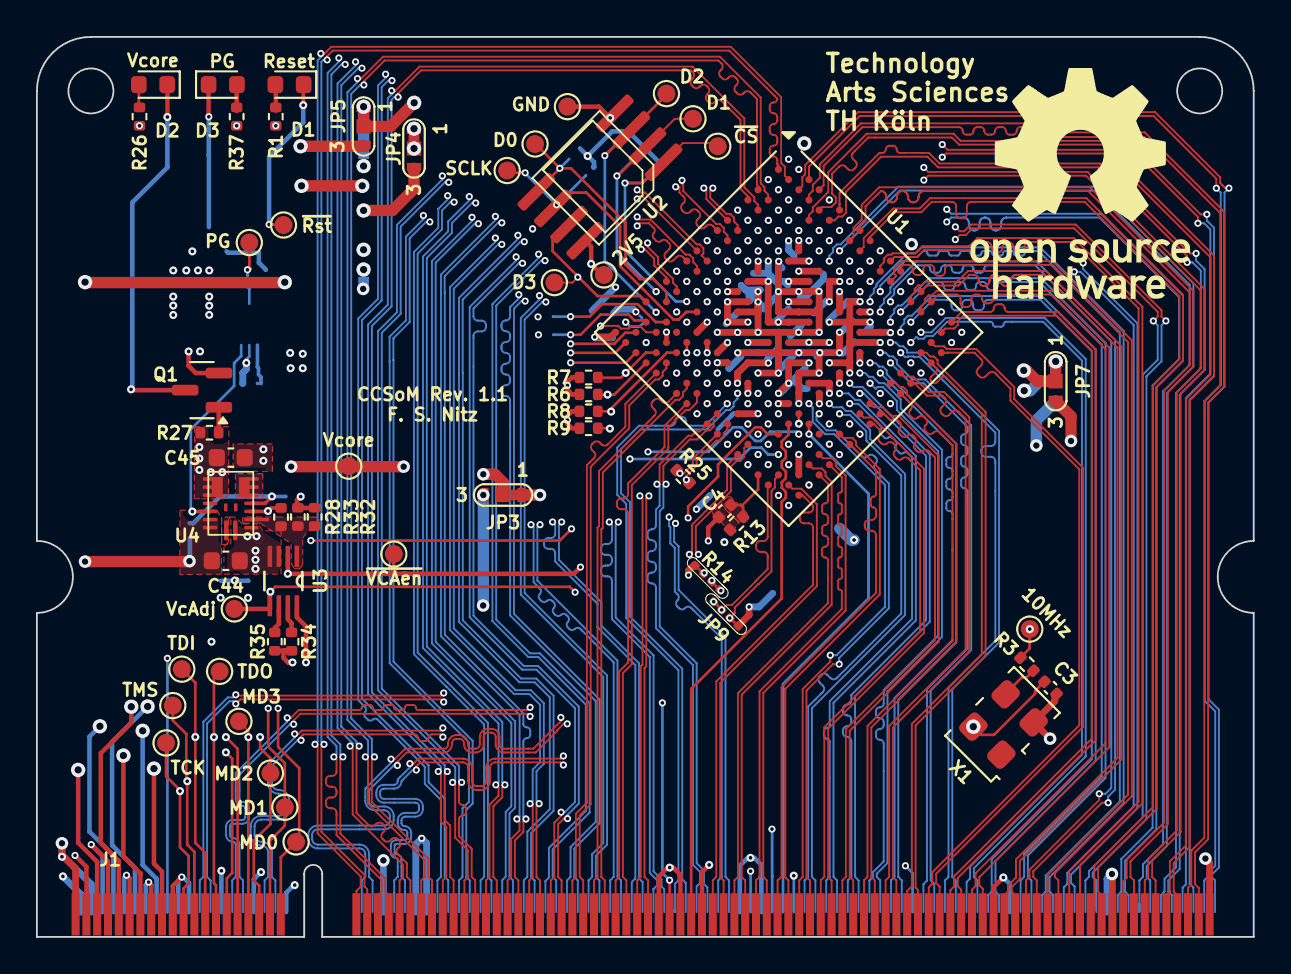
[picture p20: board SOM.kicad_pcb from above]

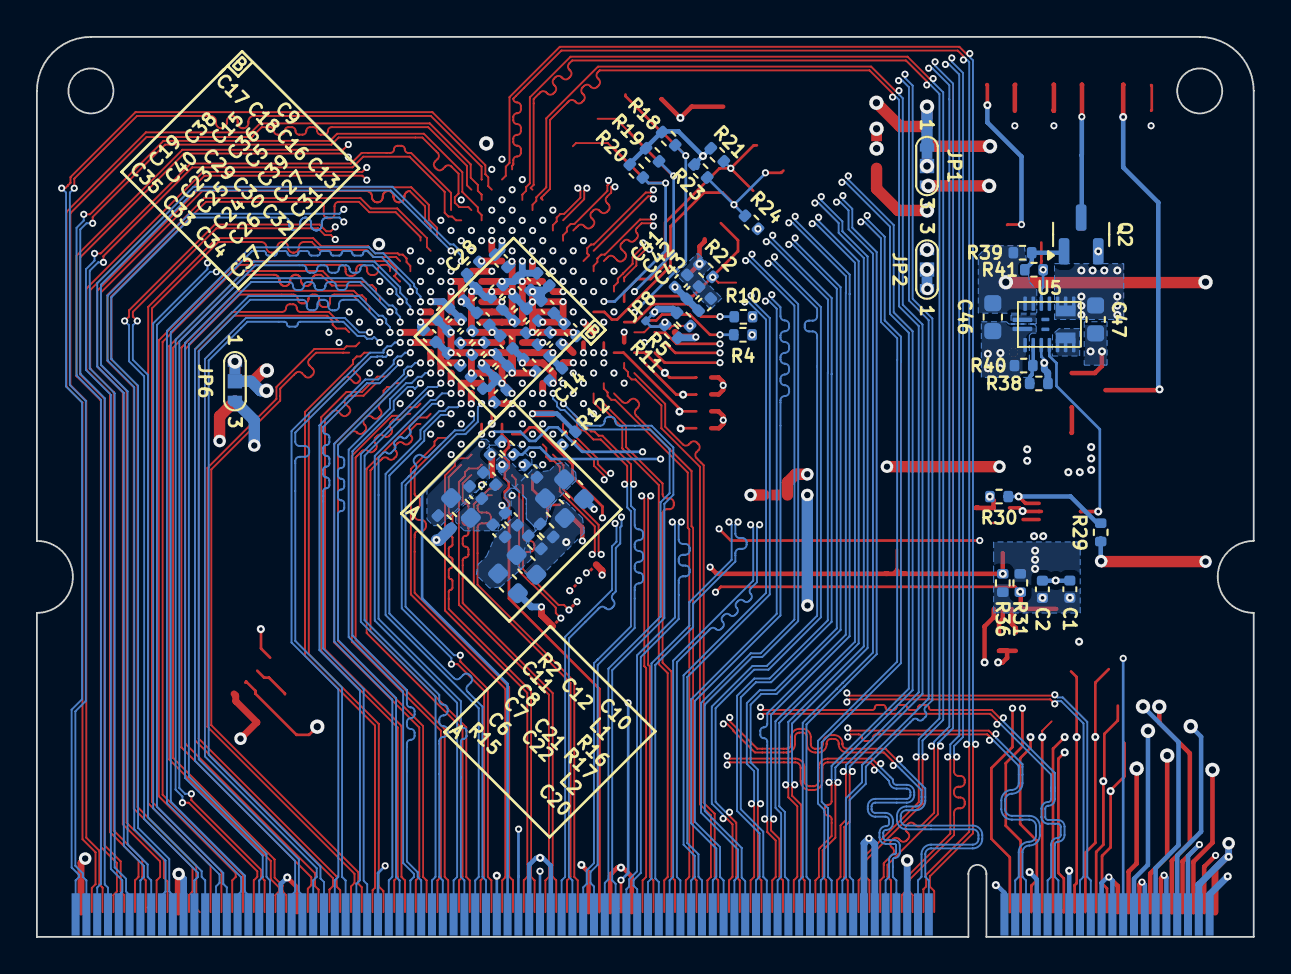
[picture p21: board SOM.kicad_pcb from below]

Board: 6 copper layers, 67.6 x 50.0 mm, 135 parts (75 on the bottom side), 212 nets.

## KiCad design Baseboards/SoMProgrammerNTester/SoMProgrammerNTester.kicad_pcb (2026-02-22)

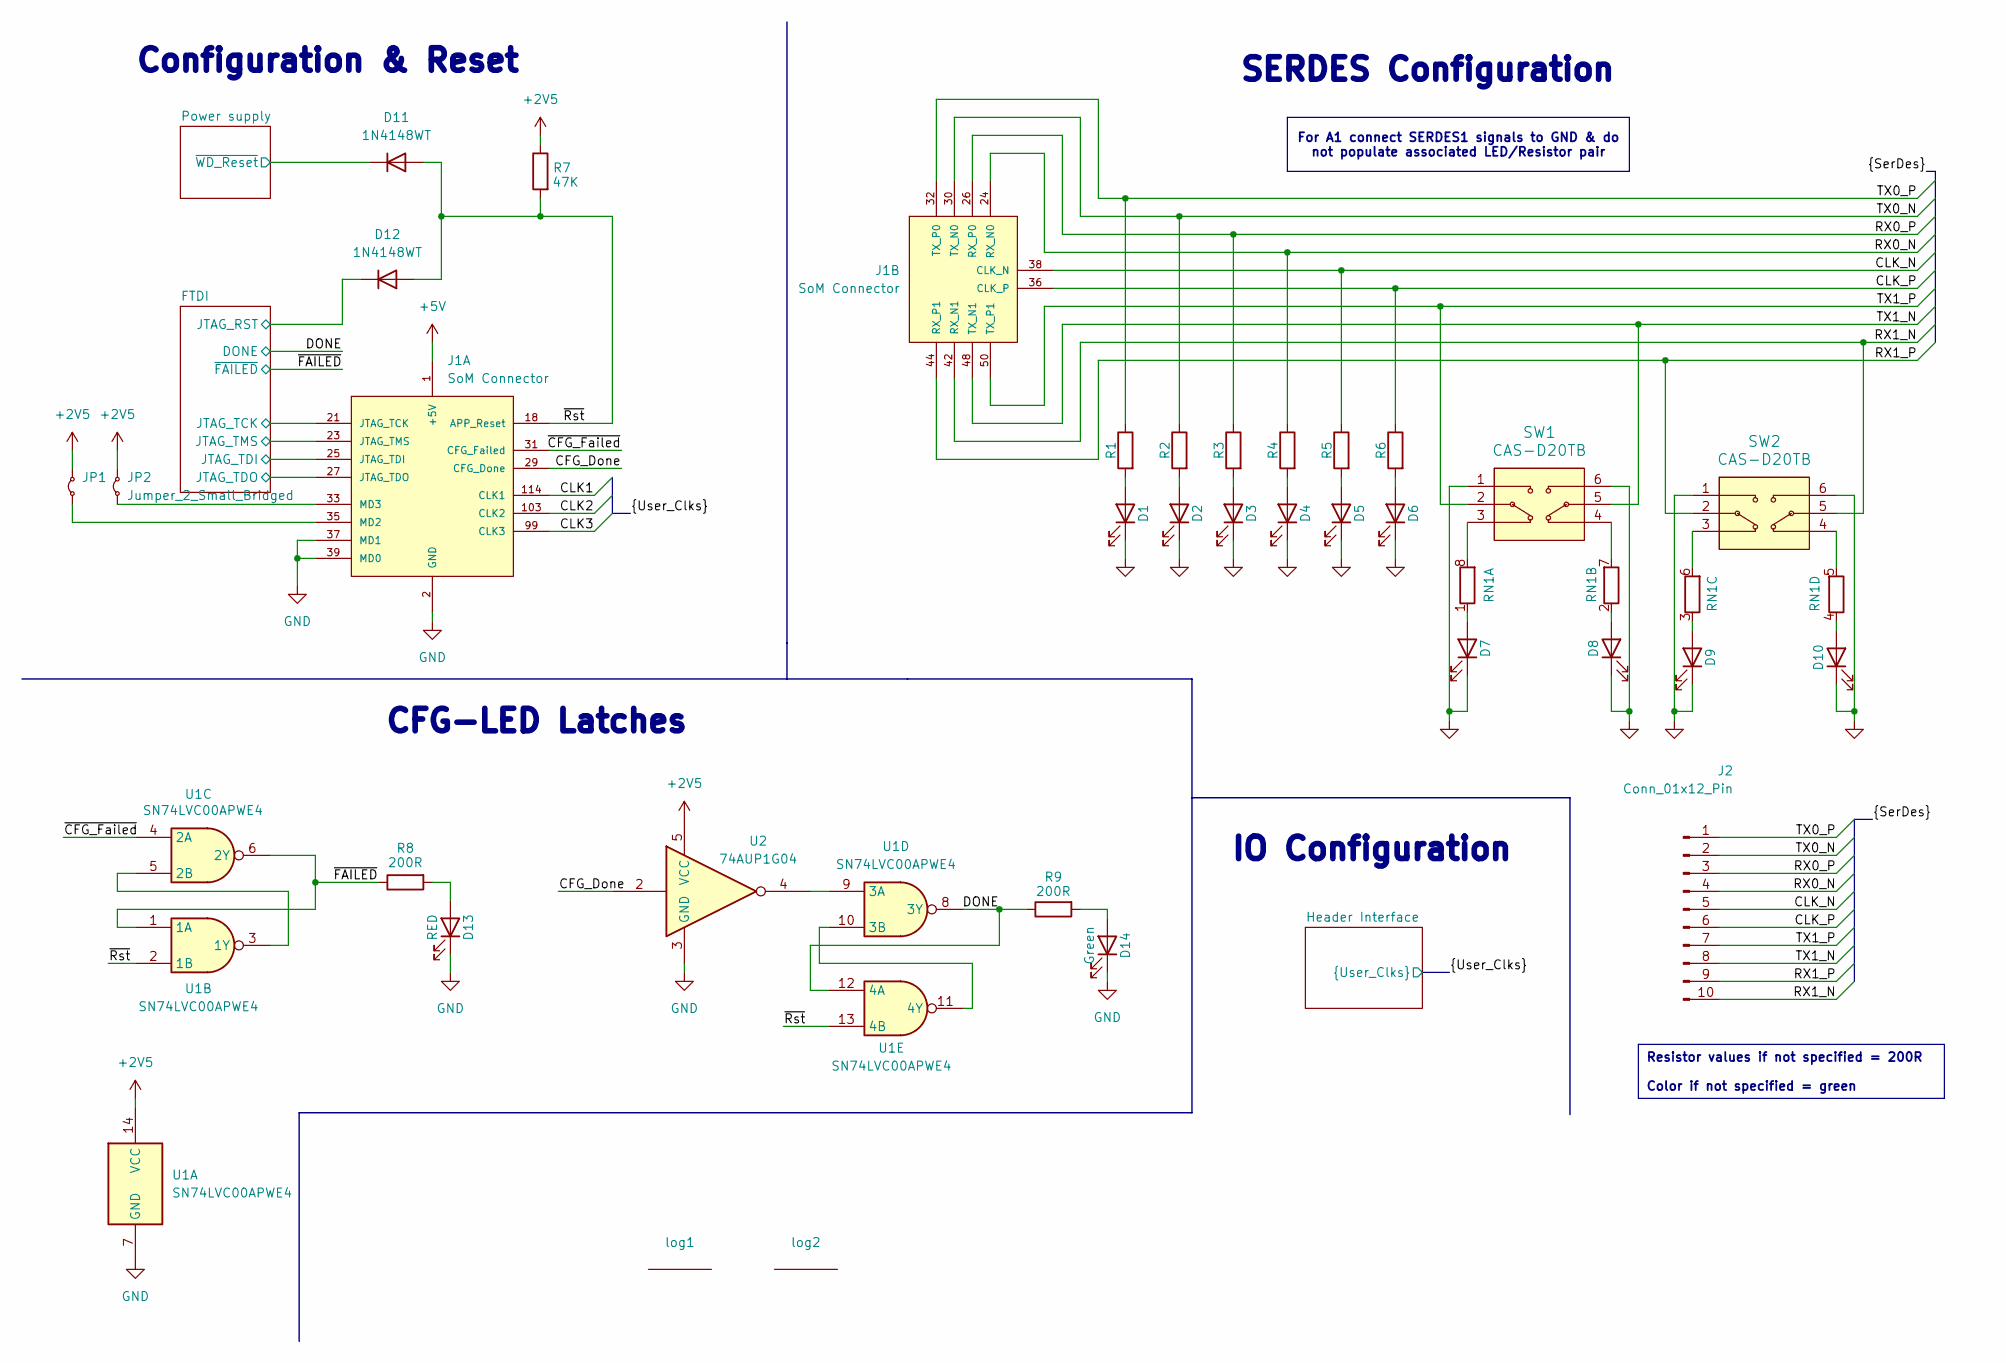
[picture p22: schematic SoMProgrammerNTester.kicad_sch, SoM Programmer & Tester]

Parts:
D1, D2, D3, D4, D5, D6, D7, D8, D9, D10, D14: Green; LED_0603_1608Metric; Mouser Part Number 710-150060VS75000
D11, D12: 1N4148WT; D_SOD-523; Mouser Part Number 637-1N4148WT
D13: RED; LED_0603_1608Metric; Mouser Part Number 710-150060SS75000
J1: SoM Connector; SoM_Connector; Mouser Part Number 571-1473005-1
J2: Conn_01x12_Pin; PinHeader_1x10_P2.54mm_Vertical
JP1, JP2: Jumper_2_Small_Bridged; TestPoint_2Pads_Pitch2.54mm_Drill0.8mm
R1, R2, R3, R4, R5, R6, R8, R9: 200R; R_0603_1608Metric; Mouser Part Number 71-CRCW0603200RFKEC
R7: 47K; R_0603_1608Metric; Mouser Part Number 71-CRCW060347K0FKED
RN1: 200R; R_Array_Convex_4x0603; Mouser Part Number 667-EXB-38V201JV
SW1, SW2: CAS-D20TB; CASD20TB; Mouser Part Number 229-CAS-D20TB
U1: SN74LVC00APWE4; TSSOP-14_4.4x5mm_P0.65mm; Mouser Part Number 595-SN74LVC00APWE4
U2: 74AUP1G04; SOT-23-5; Mouser Part Number 595-SN74AUP1G04DBVR
log1: PinguinLogo
log2: OpenHardwareLogo

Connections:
+2V5: JP1.1 (A), JP2.1 (A), R7.1, U1.14 (VCC), U2.5 (VCC); also elsewhere on the board
+5V: J1.1 (+5V), J1.4 (+5V); also elsewhere on the board
/CFG_Done: J1.29 (CFG_Done), U2.2
/CLK1: J1.114 (CLK1); also elsewhere on the board
/CLK2: J1.103 (CLK2); also elsewhere on the board
/CLK3: J1.99 (CLK3); also elsewhere on the board
/CLK_N: J1.38 (CLK_N), J2.5, R5.1
/CLK_P: J1.36 (CLK_P), J2.6, R6.1
/DONE: R9.1, U1.8 (3Y), U1.12 (4A); also elsewhere on the board
/FTDI/JTAG_RST: D12.1 (K); also elsewhere on the board
/FTDI/JTAG_TCK: J1.21 (JTAG_TCK); also elsewhere on the board
/FTDI/JTAG_TDI: J1.25 (JTAG_TDI); also elsewhere on the board
/FTDI/JTAG_TDO: J1.27 (JTAG_TDO); also elsewhere on the board
/FTDI/JTAG_TMS: J1.23 (JTAG_TMS); also elsewhere on the board
/Power supply/~WD_Reset: D11.1 (K); also elsewhere on the board
/RX0_N: J1.24 (RX_N0), J2.4, R4.1
/RX0_P: J1.26 (RX_P0), J2.3, R3.1
/RX1_N: J1.42 (RX_N1), J2.10, SW2.5
/RX1_P: J1.44 (RX_P1), J2.9, SW2.2
/TX0_N: J1.30 (TX_N0), J2.2, R2.1
/TX0_P: J1.32 (TX_P0), J2.1, R1.1
/TX1_N: J1.48 (TX_N1), J2.8, SW1.5
/TX1_P: J1.50 (TX_P1), J2.7, SW1.2
/~CFG_Failed: J1.31 (CFG_Failed), U1.4 (2A)
/~FAILED: R8.1, U1.1 (1A), U1.6 (2Y); also elsewhere on the board
/~Rst: D11.2 (A), D12.2 (A), J1.18 (APP_Reset), R7.2, U1.2 (1B), U1.13 (4B)
GND: D1.1 (K), D2.1 (K), D3.1 (K), D4.1 (K), D5.1 (K), D6.1 (K), D7.1 (K), D8.1 (K), D9.1 (K), D10.1 (K), D13.1 (K), D14.1 (K), J1.2 (GND), J1.3 (GND), J1.6 (GND), J1.7 (GND), J1.10 (GND), J1.11 (GND), J1.14 (GND), J1.15 (GND), J1.19 (GND), J1.20 (GND), J1.22 (GND), J1.28 (GND), J1.34 (GND), J1.37 (MD1), J1.39 (MD0), J1.40 (GND), J1.46 (GND), J1.52 (GND), J1.54 (GND), J1.97 (GND), J1.101 (GND), J1.105 (GND), J1.112 (GND), J1.116 (GND), J1.122 (GND), J1.144 (GND), J1.159 (GND), J1.162 (GND), J1.180 (GND), J1.181 (GND), J1.199 (GND), J1.S1 (SHIELD), J1.S2 (SHIELD__1), SW1.1, SW1.6, SW2.1, SW2.6, U1.7 (GND), U2.3 (GND); also elsewhere on the board
unnamed: D1.2 (A), R1.2
unnamed: D2.2 (A), R2.2
unnamed: D3.2 (A), R3.2
unnamed: D4.2 (A), R4.2
unnamed: D5.2 (A), R5.2
unnamed: D6.2 (A), R6.2
unnamed: D7.2 (A), RN1.1 (R1.1)
unnamed: D8.2 (A), RN1.2 (R2.1)
unnamed: D9.2 (A), RN1.3 (R3.1)
unnamed: D10.2 (A), RN1.4 (R4.1)
unnamed: D13.2 (A), R8.2
unnamed: D14.2 (A), R9.2
unnamed: J1.35 (MD2), JP1.2 (B)
unnamed: J1.33 (MD3), JP2.2 (B)
unnamed: RN1.8 (R1.2), SW1.3
unnamed: RN1.7 (R2.2), SW1.4
unnamed: RN1.6 (R3.2), SW2.3
unnamed: RN1.5 (R4.2), SW2.4
unnamed: U1.3 (1Y), U1.5 (2B)
unnamed: U1.9 (3A), U2.4
unnamed: U1.10 (3B), U1.11 (4Y)

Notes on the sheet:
Resistor values if not specified = 200R Color if not specified = green
For A1 connect SERDES1 signals to GND & do not populate associated LED/Resistor pair
Configuration & Reset
CFG-LED Latches
IO Configuration
SERDES Configuration

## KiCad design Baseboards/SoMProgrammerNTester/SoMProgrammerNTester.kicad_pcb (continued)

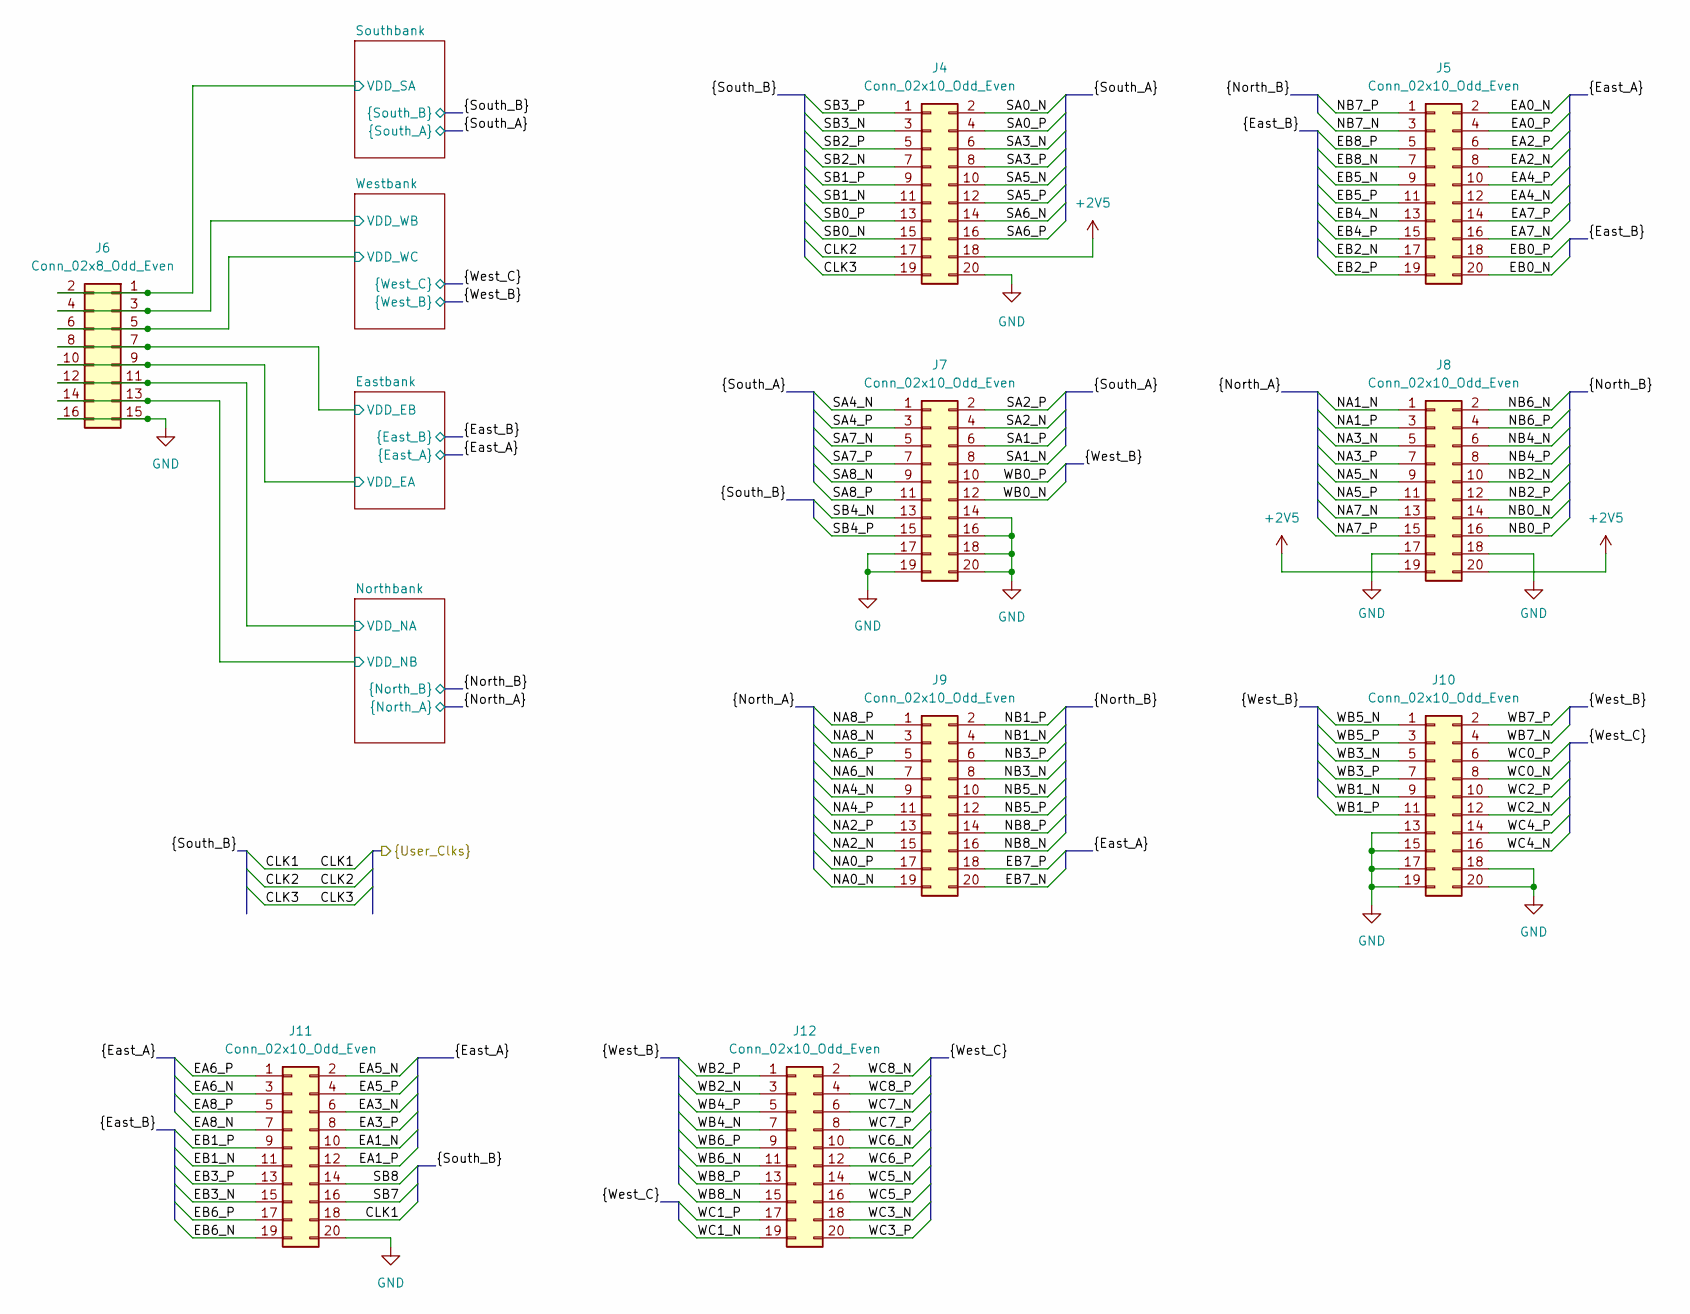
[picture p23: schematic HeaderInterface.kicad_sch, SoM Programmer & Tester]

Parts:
J4, J5, J7, J8, J9, J10, J11, J12: Conn_02x10_Odd_Even; PinHeader_2x10_P2.54mm_Vertical; Mouser Part Number 649-1012938192002BLF
J6: Conn_02x8_Odd_Even; PinHeader_2x08_P2.54mm_Vertical; Mouser Part Number 649-1012938191601BLF

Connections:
+2V5: J4.18, J8.19, J8.20; also elsewhere on the board
/CLK1: J11.18; also elsewhere on the board
/CLK2: J4.17; also elsewhere on the board
/CLK3: J4.19; also elsewhere on the board
/Header Interface/EA0_N: J5.2; also elsewhere on the board
/Header Interface/EA0_P: J5.4; also elsewhere on the board
/Header Interface/EA1_N: J11.10; also elsewhere on the board
/Header Interface/EA1_P: J11.12; also elsewhere on the board
/Header Interface/EA2_N: J5.8; also elsewhere on the board
/Header Interface/EA2_P: J5.6; also elsewhere on the board
/Header Interface/EA3_N: J11.6; also elsewhere on the board
/Header Interface/EA3_P: J11.8; also elsewhere on the board
/Header Interface/EA4_N: J5.12; also elsewhere on the board
/Header Interface/EA4_P: J5.10; also elsewhere on the board
/Header Interface/EA5_N: J11.2; also elsewhere on the board
/Header Interface/EA5_P: J11.4; also elsewhere on the board
/Header Interface/EA6_N: J11.3; also elsewhere on the board
/Header Interface/EA6_P: J11.1; also elsewhere on the board
/Header Interface/EA7_N: J5.16; also elsewhere on the board
/Header Interface/EA7_P: J5.14; also elsewhere on the board
/Header Interface/EA8_N: J11.7; also elsewhere on the board
/Header Interface/EA8_P: J11.5; also elsewhere on the board
/Header Interface/EB0_N: J5.20; also elsewhere on the board
/Header Interface/EB0_P: J5.18; also elsewhere on the board
/Header Interface/EB1_N: J11.11; also elsewhere on the board
/Header Interface/EB1_P: J11.9; also elsewhere on the board
/Header Interface/EB2_N: J5.17; also elsewhere on the board
/Header Interface/EB2_P: J5.19; also elsewhere on the board
/Header Interface/EB3_N: J11.15; also elsewhere on the board
/Header Interface/EB3_P: J11.13; also elsewhere on the board
/Header Interface/EB4_N: J5.13; also elsewhere on the board
/Header Interface/EB4_P: J5.15; also elsewhere on the board
/Header Interface/EB5_N: J5.9; also elsewhere on the board
/Header Interface/EB5_P: J5.11; also elsewhere on the board
/Header Interface/EB6_N: J11.19; also elsewhere on the board
/Header Interface/EB6_P: J11.17; also elsewhere on the board
/Header Interface/EB7_N: J9.20; also elsewhere on the board
/Header Interface/EB7_P: J9.18; also elsewhere on the board
/Header Interface/EB8_N: J5.7; also elsewhere on the board
/Header Interface/EB8_P: J5.5; also elsewhere on the board
/Header Interface/Eastbank/VDD_EA: J6.9, J6.10; also elsewhere on the board
/Header Interface/Eastbank/VDD_EB: J6.7, J6.8; also elsewhere on the board
/Header Interface/NA0_N: J9.19; also elsewhere on the board
/Header Interface/NA0_P: J9.17; also elsewhere on the board
/Header Interface/NA1_N: J8.1; also elsewhere on the board
/Header Interface/NA1_P: J8.3; also elsewhere on the board
/Header Interface/NA2_N: J9.15; also elsewhere on the board
/Header Interface/NA2_P: J9.13; also elsewhere on the board
/Header Interface/NA3_N: J8.5; also elsewhere on the board
/Header Interface/NA3_P: J8.7; also elsewhere on the board
/Header Interface/NA4_N: J9.9; also elsewhere on the board
/Header Interface/NA4_P: J9.11; also elsewhere on the board
/Header Interface/NA5_N: J8.9; also elsewhere on the board
/Header Interface/NA5_P: J8.11; also elsewhere on the board
/Header Interface/NA6_N: J9.7; also elsewhere on the board
/Header Interface/NA6_P: J9.5; also elsewhere on the board
/Header Interface/NA7_N: J8.13; also elsewhere on the board
/Header Interface/NA7_P: J8.15; also elsewhere on the board
/Header Interface/NA8_N: J9.3; also elsewhere on the board
/Header Interface/NA8_P: J9.1; also elsewhere on the board
/Header Interface/NB0_N: J8.14; also elsewhere on the board
/Header Interface/NB0_P: J8.16; also elsewhere on the board
/Header Interface/NB1_N: J9.4; also elsewhere on the board
/Header Interface/NB1_P: J9.2; also elsewhere on the board
/Header Interface/NB2_N: J8.10; also elsewhere on the board
/Header Interface/NB2_P: J8.12; also elsewhere on the board
/Header Interface/NB3_N: J9.8; also elsewhere on the board
/Header Interface/NB3_P: J9.6; also elsewhere on the board
/Header Interface/NB4_N: J8.6; also elsewhere on the board
/Header Interface/NB4_P: J8.8; also elsewhere on the board
/Header Interface/NB5_N: J9.10; also elsewhere on the board
/Header Interface/NB5_P: J9.12; also elsewhere on the board
/Header Interface/NB6_N: J8.2; also elsewhere on the board
/Header Interface/NB6_P: J8.4; also elsewhere on the board
/Header Interface/NB7_N: J5.3; also elsewhere on the board
/Header Interface/NB7_P: J5.1; also elsewhere on the board
/Header Interface/NB8_N: J9.16; also elsewhere on the board
/Header Interface/NB8_P: J9.14; also elsewhere on the board
/Header Interface/Northbank/VDD_NA: J6.11, J6.12; also elsewhere on the board
/Header Interface/Northbank/VDD_NB: J6.13, J6.14; also elsewhere on the board
/Header Interface/SA0_N: J4.2; also elsewhere on the board
/Header Interface/SA0_P: J4.4; also elsewhere on the board
/Header Interface/SA1_N: J7.8; also elsewhere on the board
/Header Interface/SA1_P: J7.6; also elsewhere on the board
/Header Interface/SA2_N: J7.4; also elsewhere on the board
/Header Interface/SA2_P: J7.2; also elsewhere on the board
/Header Interface/SA3_N: J4.6; also elsewhere on the board
/Header Interface/SA3_P: J4.8; also elsewhere on the board
/Header Interface/SA4_N: J7.1; also elsewhere on the board
/Header Interface/SA4_P: J7.3; also elsewhere on the board
/Header Interface/SA5_N: J4.10; also elsewhere on the board
/Header Interface/SA5_P: J4.12; also elsewhere on the board
/Header Interface/SA6_N: J4.14; also elsewhere on the board
/Header Interface/SA6_P: J4.16; also elsewhere on the board
/Header Interface/SA7_N: J7.5; also elsewhere on the board
/Header Interface/SA7_P: J7.7; also elsewhere on the board
/Header Interface/SA8_N: J7.9; also elsewhere on the board
/Header Interface/SA8_P: J7.11; also elsewhere on the board
/Header Interface/SB0_N: J4.15; also elsewhere on the board
/Header Interface/SB0_P: J4.13; also elsewhere on the board
/Header Interface/SB1_N: J4.11; also elsewhere on the board
/Header Interface/SB1_P: J4.9; also elsewhere on the board
/Header Interface/SB2_N: J4.7; also elsewhere on the board
/Header Interface/SB2_P: J4.5; also elsewhere on the board
/Header Interface/SB3_N: J4.3; also elsewhere on the board
/Header Interface/SB3_P: J4.1; also elsewhere on the board
/Header Interface/SB4_N: J7.13; also elsewhere on the board
/Header Interface/SB4_P: J7.15; also elsewhere on the board
/Header Interface/SB7: J11.16; also elsewhere on the board
/Header Interface/SB8: J11.14; also elsewhere on the board
/Header Interface/Southbank/VDD_SA: J6.1, J6.2; also elsewhere on the board
/Header Interface/WB0_N: J7.12; also elsewhere on the board
/Header Interface/WB0_P: J7.10; also elsewhere on the board
/Header Interface/WB1_N: J10.9; also elsewhere on the board
/Header Interface/WB1_P: J10.11; also elsewhere on the board
/Header Interface/WB2_N: J12.3; also elsewhere on the board
/Header Interface/WB2_P: J12.1; also elsewhere on the board
/Header Interface/WB3_N: J10.5; also elsewhere on the board
/Header Interface/WB3_P: J10.7; also elsewhere on the board
/Header Interface/WB4_N: J12.7; also elsewhere on the board
/Header Interface/WB4_P: J12.5; also elsewhere on the board
/Header Interface/WB5_N: J10.1; also elsewhere on the board
/Header Interface/WB5_P: J10.3; also elsewhere on the board
/Header Interface/WB6_N: J12.11; also elsewhere on the board
/Header Interface/WB6_P: J12.9; also elsewhere on the board
/Header Interface/WB7_N: J10.4; also elsewhere on the board
/Header Interface/WB7_P: J10.2; also elsewhere on the board
/Header Interface/WB8_N: J12.15; also elsewhere on the board
/Header Interface/WB8_P: J12.13; also elsewhere on the board
/Header Interface/WC0_N: J10.8; also elsewhere on the board
/Header Interface/WC0_P: J10.6; also elsewhere on the board
/Header Interface/WC1_N: J12.19; also elsewhere on the board
/Header Interface/WC1_P: J12.17; also elsewhere on the board
/Header Interface/WC2_N: J10.12; also elsewhere on the board
/Header Interface/WC2_P: J10.10; also elsewhere on the board
/Header Interface/WC3_N: J12.18; also elsewhere on the board
/Header Interface/WC3_P: J12.20; also elsewhere on the board
/Header Interface/WC4_N: J10.16; also elsewhere on the board
/Header Interface/WC4_P: J10.14; also elsewhere on the board
/Header Interface/WC5_N: J12.14; also elsewhere on the board
/Header Interface/WC5_P: J12.16; also elsewhere on the board
/Header Interface/WC6_N: J12.10; also elsewhere on the board
/Header Interface/WC6_P: J12.12; also elsewhere on the board
/Header Interface/WC7_N: J12.6; also elsewhere on the board
/Header Interface/WC7_P: J12.8; also elsewhere on the board
/Header Interface/WC8_N: J12.2; also elsewhere on the board
/Header Interface/WC8_P: J12.4; also elsewhere on the board
/Header Interface/Westbank/VDD_WB: J6.3, J6.4; also elsewhere on the board
/Header Interface/Westbank/VDD_WC: J6.5, J6.6; also elsewhere on the board
GND: J4.20, J6.15, J6.16, J7.14, J7.16, J7.17, J7.18, J7.19, J7.20, J8.17, J8.18, J10.13, J10.15, J10.17, J10.18, J10.19, J10.20, J11.20; also elsewhere on the board

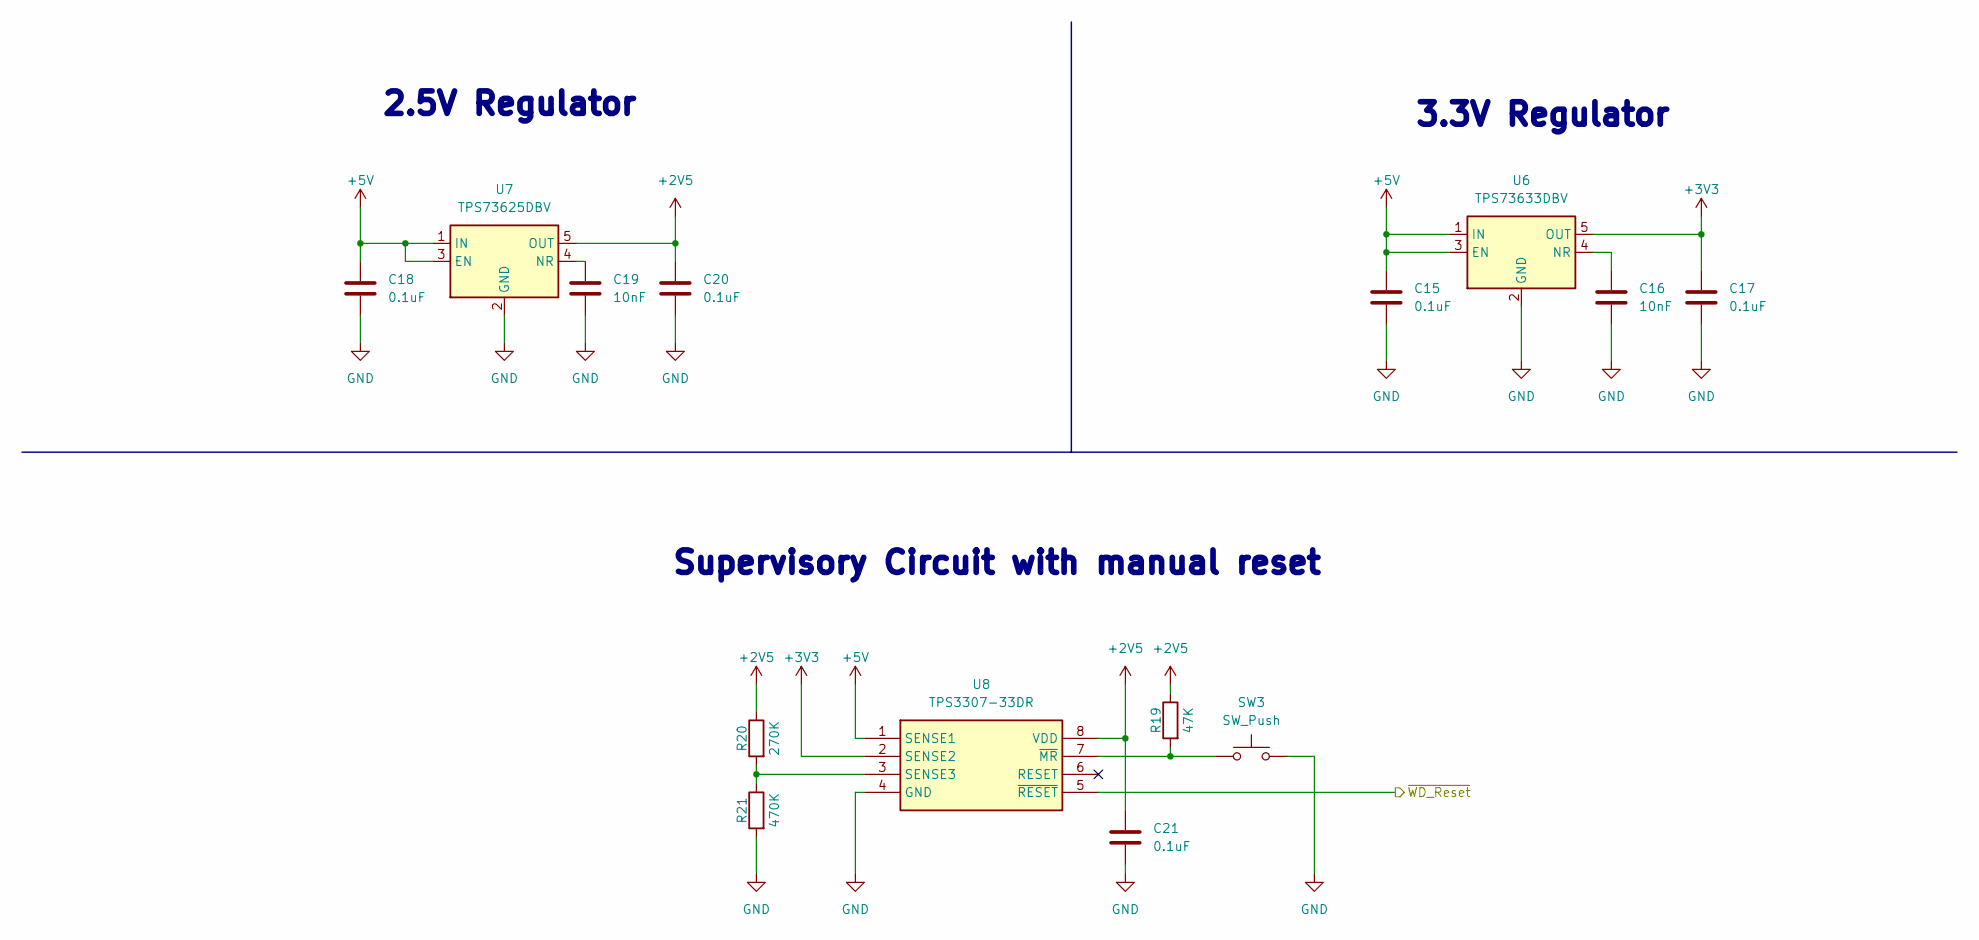
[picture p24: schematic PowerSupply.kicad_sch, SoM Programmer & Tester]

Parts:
C15, C17, C18, C20, C21: 0.1uF; C_0603_1608Metric; Mouser Part Number 80-C0603C104M4R7411
C16, C19: 10nF; C_0603_1608Metric; Mouser Part Number 80-C0603X103J4HAUTO
R19: 47K; R_0603_1608Metric; Mouser Part Number 71-CRCW060347K0FKED
R20: 270K; R_0603_1608Metric; Mouser Part Number 71-CRCW0603-270K-E3
R21: 470K; R_0603_1608Metric; Mouser Part Number 71-CRCW0603470KFKEAH
SW3: SW_Push; SW_SPST_TL3305A; Mouser Part Number 612-TL3305AF260QG
U6: TPS73633DBV; SOT-23-5; Mouser Part Number 595-TPS73633DBVRG4
U7: TPS73625DBV; SOT-23-5; Mouser Part Number 595-TPS73625DBVT
U8: TPS3307-33DR; SOIC-8_5.8x3.81mm; Mouser Part Number 595-TPS3307-33DR

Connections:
+2V5: C20.1, C21.1, R19.1, R20.1, U7.5 (OUT), U8.8 (VDD); also elsewhere on the board
+3V3: C17.1, U6.5 (OUT), U8.2 (SENSE2); also elsewhere on the board
+5V: C15.1, C18.1, U6.1 (IN), U6.3 (EN), U7.1 (IN), U7.3 (EN), U8.1 (SENSE1); also elsewhere on the board
/Power supply/~WD_Reset: U8.5 (~RESET); also elsewhere on the board
GND: C15.2, C16.2, C17.2, C18.2, C19.2, C20.2, C21.2, R21.2, SW3.2, U6.2 (GND), U7.2 (GND), U8.4 (GND); also elsewhere on the board
unnamed: C16.1, U6.4 (NR)
unnamed: C19.1, U7.4 (NR)
unnamed: R20.2, R21.1, U8.3 (SENSE3)
unnamed: R19.2, SW3.1, U8.7 (~MR)

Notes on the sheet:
Supervisory Circuit with manual reset
3.3V Regulator
2.5V Regulator


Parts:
C1, C2: 4.7uF; C_0603_1608Metric; Mouser Part Number 963-MSASE168AB5475KT
C3, C4, C6, C7, C8, C9, C12, C13, C14: 0.1uF; C_0603_1608Metric; Mouser Part Number 80-C0603C104M4R7411
C5: 3.3uF; C_0603_1608Metric; Mouser Part Number 810-C1608X5R1C335KAC
C10, C11: 10pF; C_0603_1608Metric; Mouser Part Number 581-0603YA100JAT2A
FB1, FB2: 600R, 0.5A; L_0603_1608Metric; Mouser Part Number 810-MMZ1608R601ATD25
J13: USB_C_Receptacle_USB2.0_16P; USB_C_Receptacle_GCT_USB4110; Mouser Part Number 640-USB4110-GF-A
R10, R11: 5K1; R_0603_1608Metric; Mouser Part Number 71-RCS060356K0FKEA
R12: 1K; R_0603_1608Metric; Mouser Part Number 71-CRCW0603-1.0K-E3
R13, R14: 12K; R_0603_1608Metric; Mouser Part Number 71-CRCW0603-12K-E3
R15, R16, R17: 10K; R_0603_1608Metric; Mouser Part Number 71-CRCW060310K0FKED
R18: 2K; R_0603_1608Metric; Mouser Part Number 71-TNPW06032K00FHEA
TP1: USB_D-; TestPoint_Pad_D1.5mm
TP2: USB_D+; TestPoint_Pad_D1.5mm
TP3: +3V3; TestPoint_Pad_D1.5mm
TP4: 12MHz; TestPoint_Pad_D1.5mm
TP5: +1V8_FTDI; TestPoint_Pad_D1.5mm
U3: SN74CB3T3245PWR; TSSOP-20_4.4x6.5mm_P0.65mm; Mouser Part Number 595-SN74CB3T3245PWR
U4: FT2232HL; LQFP-64_10x10mm_P0.5mm; Mouser Part Number 895-FT2232HL
U5: 93LC46B; TSSOP-8_4.4x3mm_P0.65mm; Mouser Part Number 579-93LC46BT-E/ST
X1: 12MHz; Crystal_SMD_Abracon_ABM3B-4Pin_5.0x3.2mm; Mouser Part Number 815-ABM3B-12-T

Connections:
+1V8_FTDI: C5.1, C12.1, C13.1, C14.1, TP5.1, U4.12 (VCORE), U4.37 (VCORE), U4.49 (VREGOUT), U4.64 (VCORE)
+2V5: U3.9 (A8), U3.20 (VCC); also elsewhere on the board
+3V3: C6.1, C7.1, C8.1, C9.1, FB1.1, FB2.1, R12.1, R15.1, R16.1, R17.1, TP3.1, U4.20 (VCCIO), U4.31 (VCCIO), U4.42 (VCCIO), U4.50 (VREGIN), U4.56 (VCCIO), U5.8 (VCC); also elsewhere on the board
+5V: J13.A4 (VBUS), J13.A9 (VBUS), J13.B4 (VBUS), J13.B9 (VBUS); also elsewhere on the board
/DONE: U3.7 (A6); also elsewhere on the board
/FTDI/FTDI_EEPROM_CS: R17.2, U4.63 (EECS), U5.1 (CS)
/FTDI/JTAG_RST: U3.6 (A5); also elsewhere on the board
/FTDI/JTAG_TCK: U3.2 (A1); also elsewhere on the board
/FTDI/JTAG_TDI: U3.3 (A2); also elsewhere on the board
/FTDI/JTAG_TDO: U3.4 (A3); also elsewhere on the board
/FTDI/JTAG_TMS: U3.5 (A4); also elsewhere on the board
/~FAILED: U3.8 (A7); also elsewhere on the board
GND: C1.2, C2.2, C3.2, C4.2, C5.2, C6.2, C7.2, C8.2, C9.2, C10.2, C11.2, C12.2, C13.2, C14.2, J13.A1 (GND), J13.A12 (GND), J13.B1 (GND), J13.B12 (GND), J13.S1 (SHIELD), R10.2, R11.1, R13.2, R14.2, U3.10 (GND), U4.1 (GND), U4.5 (GND), U4.10 (AGND), U4.11 (GND), U4.13 (TEST), U4.15 (GND), U4.25 (GND), U4.35 (GND), U4.47 (GND), U4.51 (GND), U5.5 (GND), X1.2, X1.4; also elsewhere on the board
unnamed: J13.A5 (CC1), R10.1
unnamed: J13.B5 (CC2), R11.2
unnamed: U3.18 (B1), U4.16 (ADBUS0)
unnamed: U3.17 (B2), U4.17 (ADBUS1)
unnamed: U3.16 (B3), U4.18 (ADBUS2)
unnamed: U3.15 (B4), U4.19 (ADBUS3)
unnamed: U3.14 (B5), U4.21 (ADBUS4)
unnamed: U3.13 (B6), U4.22 (ADBUS5)
unnamed: U3.12 (B7), U4.23 (ADBUS6)
unnamed: U3.11 (B8), U4.24 (ADBUS7)
unnamed: U3.19 (~OE), U4.26 (ACBUS0)
unnamed: R13.1, U4.29 (ACBUS3)
unnamed: J13.A7 (D-), J13.B7 (D-), TP1.1, U4.7 (DM)
unnamed: J13.A6 (D+), J13.B6 (D+), TP2.1, U4.8 (DP)
unnamed: R16.2, U4.62 (EECLK), U5.2 (SCLK)
unnamed: R18.1, U4.61 (EEDATA), U5.3 (DI)
unnamed: C10.1, U4.2 (OSCI), X1.1
unnamed: C11.1, TP4.1, U4.3 (OSCO), X1.3
unnamed: R14.1, U4.6 (REF)
unnamed: C2.1, C4.1, FB2.2, U4.4 (VPHY)
unnamed: C1.1, C3.1, FB1.2, U4.9 (VPLL)
unnamed: R12.2, U4.14 (~RESET)
unnamed: R15.2, R18.2, U5.4 (DO)

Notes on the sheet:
Fitering
FTDI Configuration


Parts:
D51, D52, D53, D54, D55, D56, D57, D58, D59, D60, D61, D62, D63, D64, D65, D66, D67, D68, D69, D70, D71, D72, D73, D74, D75, D76, D77, D78, D79, D80, D81, D82, D83, D84, D85, D86: Green; LED_0603_1608Metric; Mouser Part Number 710-150060VS75000
J1: SoM Connector; SoM_Connector; Mouser Part Number 571-1473005-1
RN2, RN8, RN9, RN10, RN11: 200R; R_Array_Convex_8x0602; Mouser Part Number 667-EXB-2HV201JV
RN5: 200R; R_Array_Convex_4x0603; Mouser Part Number 667-EXB-38V201JV

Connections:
/Header Interface/NA0_N: J1.200 (NA0_N), RN10.8 (R8.1); also elsewhere on the board
/Header Interface/NA0_P: J1.198 (NA0_P), RN10.7 (R7.1); also elsewhere on the board
/Header Interface/NA1_N: J1.197 (NA1_N), RN11.1 (R1.1); also elsewhere on the board
/Header Interface/NA1_P: J1.195 (NA1_P), RN11.2 (R2.1); also elsewhere on the board
/Header Interface/NA2_N: J1.196 (NA2_N), RN10.6 (R6.1); also elsewhere on the board
/Header Interface/NA2_P: J1.194 (NA2_P), RN10.5 (R5.1); also elsewhere on the board
/Header Interface/NA3_N: J1.193 (NA3_N), RN11.3 (R3.1); also elsewhere on the board
/Header Interface/NA3_P: J1.191 (NA3_P), RN11.4 (R4.1); also elsewhere on the board
/Header Interface/NA4_N: J1.190 (NA4_N), RN10.3 (R3.1); also elsewhere on the board
/Header Interface/NA4_P: J1.192 (NA4_P), RN10.4 (R4.1); also elsewhere on the board
/Header Interface/NA5_N: J1.189 (NA5_N), RN11.5 (R5.1); also elsewhere on the board
/Header Interface/NA5_P: J1.187 (NA5_P), RN11.6 (R6.1); also elsewhere on the board
/Header Interface/NA6_N: J1.188 (NA6_N), RN10.2 (R2.1); also elsewhere on the board
/Header Interface/NA6_P: J1.186 (NA6_P), RN10.1 (R1.1); also elsewhere on the board
/Header Interface/NA7_N: J1.185 (NA7_N), RN11.7 (R7.1); also elsewhere on the board
/Header Interface/NA7_P: J1.183 (NA7_P), RN11.8 (R8.1); also elsewhere on the board
/Header Interface/NA8_N: J1.184 (NA8_N), RN8.8 (R8.1); also elsewhere on the board
/Header Interface/NA8_P: J1.182 (NA8_P), RN8.7 (R7.1); also elsewhere on the board
/Header Interface/NB0_N: J1.177 (NB0_N), RN9.10 (R7.2); also elsewhere on the board
/Header Interface/NB0_P: J1.179 (NB0_P), RN9.9 (R8.2); also elsewhere on the board
/Header Interface/NB1_N: J1.176 (NB1_N), RN8.5 (R5.1); also elsewhere on the board
/Header Interface/NB1_P: J1.178 (NB1_P), RN8.6 (R6.1); also elsewhere on the board
/Header Interface/NB2_N: J1.173 (NB2_N), RN9.12 (R5.2); also elsewhere on the board
/Header Interface/NB2_P: J1.175 (NB2_P), RN9.11 (R6.2); also elsewhere on the board
/Header Interface/NB3_N: J1.172 (NB3_N), RN8.3 (R3.1); also elsewhere on the board
/Header Interface/NB3_P: J1.174 (NB3_P), RN8.4 (R4.1); also elsewhere on the board
/Header Interface/NB4_N: J1.169 (NB4_N), RN9.14 (R3.2); also elsewhere on the board
/Header Interface/NB4_P: J1.171 (NB4_P), RN9.13 (R4.2); also elsewhere on the board
/Header Interface/NB5_N: J1.170 (NB5_N), RN8.2 (R2.1); also elsewhere on the board
/Header Interface/NB5_P: J1.168 (NB5_P), RN8.1 (R1.1); also elsewhere on the board
/Header Interface/NB6_N: J1.165 (NB6_N), RN9.16 (R1.2); also elsewhere on the board
/Header Interface/NB6_P: J1.167 (NB6_P), RN9.15 (R2.2); also elsewhere on the board
/Header Interface/NB7_N: J1.161 (NB7_N), RN5.6 (R3.2); also elsewhere on the board
/Header Interface/NB7_P: J1.163 (NB7_P), RN5.5 (R4.2); also elsewhere on the board
/Header Interface/NB8_N: J1.164 (NB8_N), RN2.15 (R2.2); also elsewhere on the board
/Header Interface/NB8_P: J1.166 (NB8_P), RN2.16 (R1.2); also elsewhere on the board
/Header Interface/Northbank/VDD_NA: J1.9 (VDD_NA); also elsewhere on the board
/Header Interface/Northbank/VDD_NB: J1.5 (VDD_NB); also elsewhere on the board
GND: D51.1 (K), D52.1 (K), D53.1 (K), D54.1 (K), D55.1 (K), D56.1 (K), D57.1 (K), D58.1 (K), D59.1 (K), D60.1 (K), D61.1 (K), D62.1 (K), D63.1 (K), D64.1 (K), D65.1 (K), D66.1 (K), D67.1 (K), D68.1 (K), D69.1 (K), D70.1 (K), D71.1 (K), D72.1 (K), D73.1 (K), D74.1 (K), D75.1 (K), D76.1 (K), D77.1 (K), D78.1 (K), D79.1 (K), D80.1 (K), D81.1 (K), D82.1 (K), D83.1 (K), D84.1 (K), D85.1 (K), D86.1 (K); also elsewhere on the board
unnamed: D51.2 (A), RN5.3 (R3.1)
unnamed: D52.2 (A), RN5.4 (R4.1)
unnamed: D53.2 (A), RN8.15 (R2.2)
unnamed: D54.2 (A), RN8.16 (R1.2)
unnamed: D55.2 (A), RN8.14 (R3.2)
unnamed: D56.2 (A), RN8.13 (R4.2)
unnamed: D57.2 (A), RN8.12 (R5.2)
unnamed: D58.2 (A), RN8.11 (R6.2)
unnamed: D59.2 (A), RN9.8 (R8.1)
unnamed: D60.2 (A), RN9.7 (R7.1)
unnamed: D61.2 (A), RN9.6 (R6.1)
unnamed: D62.2 (A), RN9.5 (R5.1)
unnamed: D63.2 (A), RN9.4 (R4.1)
unnamed: D64.2 (A), RN9.3 (R3.1)
unnamed: D65.2 (A), RN9.2 (R2.1)
unnamed: D66.2 (A), RN9.1 (R1.1)
unnamed: D67.2 (A), RN2.1 (R1.1)
unnamed: D68.2 (A), RN2.2 (R2.1)
unnamed: D69.2 (A), RN10.10 (R7.2)
unnamed: D70.2 (A), RN10.9 (R8.2)
unnamed: D71.2 (A), RN10.12 (R5.2)
unnamed: D72.2 (A), RN10.11 (R6.2)
unnamed: D73.2 (A), RN10.13 (R4.2)
unnamed: D74.2 (A), RN10.14 (R3.2)
unnamed: D75.2 (A), RN10.16 (R1.2)
unnamed: D76.2 (A), RN10.15 (R2.2)
unnamed: D77.2 (A), RN8.10 (R7.2)
unnamed: D78.2 (A), RN8.9 (R8.2)
unnamed: D79.2 (A), RN11.10 (R7.2)
unnamed: D80.2 (A), RN11.9 (R8.2)
unnamed: D81.2 (A), RN11.12 (R5.2)
unnamed: D82.2 (A), RN11.11 (R6.2)
unnamed: D83.2 (A), RN11.14 (R3.2)
unnamed: D84.2 (A), RN11.13 (R4.2)
unnamed: D85.2 (A), RN11.16 (R1.2)
unnamed: D86.2 (A), RN11.15 (R2.2)

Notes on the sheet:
Resistor network values if not specified = 200R Color if not specified = green

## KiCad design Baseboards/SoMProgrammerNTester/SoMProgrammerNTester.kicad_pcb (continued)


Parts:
D87, D88, D89, D90, D91, D92, D93, D94, D95, D96, D97, D98, D99, D100, D101, D102, D103, D104, D105, D106, D107, D108, D109, D110, D111, D112, D113, D114, D115, D116: Green; LED_0603_1608Metric; Mouser Part Number 710-150060VS75000
J1: SoM Connector; SoM_Connector; Mouser Part Number 571-1473005-1
RN7, RN12, RN13, RN14: 200R; R_Array_Convex_8x0602; Mouser Part Number 667-EXB-2HV201JV
RN15: 200R; R_Array_Convex_4x0603; Mouser Part Number 667-EXB-38V201JV

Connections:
/Header Interface/SA0_N: J1.81 (SA0_N), RN13.8 (R8.1); also elsewhere on the board
/Header Interface/SA0_P: J1.83 (SA0_P), RN13.7 (R7.1); also elsewhere on the board
/Header Interface/SA1_N: J1.88 (SA1_N), RN14.3 (R3.1); also elsewhere on the board
/Header Interface/SA1_P: J1.90 (SA1_P), RN14.4 (R4.1); also elsewhere on the board
/Header Interface/SA2_N: J1.92 (SA2_N), RN14.5 (R5.1); also elsewhere on the board
/Header Interface/SA2_P: J1.94 (SA2_P), RN14.6 (R6.1); also elsewhere on the board
/Header Interface/SA3_N: J1.85 (SA3_N), RN13.6 (R6.1); also elsewhere on the board
/Header Interface/SA3_P: J1.87 (SA3_P), RN13.5 (R5.1); also elsewhere on the board
/Header Interface/SA4_N: J1.96 (SA4_N), RN14.7 (R7.1); also elsewhere on the board
/Header Interface/SA4_P: J1.98 (SA4_P), RN14.8 (R8.1); also elsewhere on the board
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

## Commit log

2024-12-20 Release commit
    [DCDC.kicad_sch, Eastbank.kicad_sch, FPGA_IO_Config.kicad_sch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]
2026-02-22 Created Version with 0402 components
    [DCDC.kicad_sch, Eastbank.kicad_sch, FPGA_IO_Config.kicad_sch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]
2026-02-22 Revise 0402 footprint version availability details
    Updated information about the 0402 footprint version availability.
